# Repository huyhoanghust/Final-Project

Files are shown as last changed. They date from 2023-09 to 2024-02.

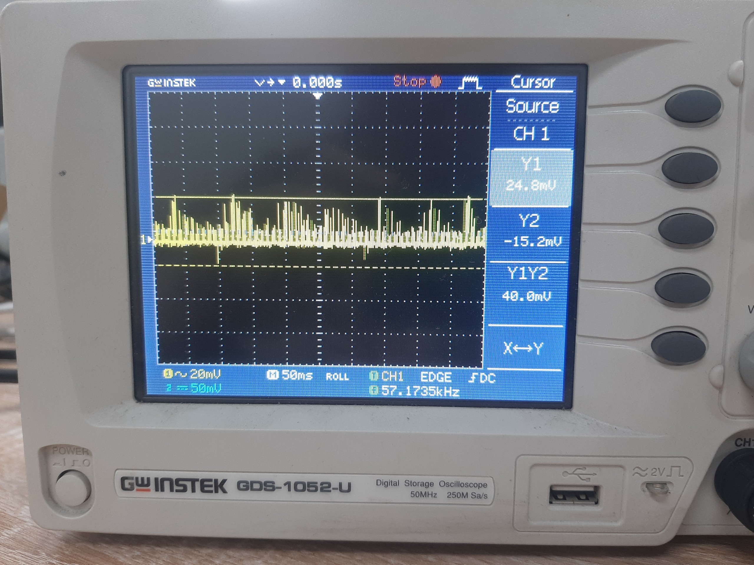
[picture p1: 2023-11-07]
PICTURE/đo nguồn/ripple_mcu.jpg

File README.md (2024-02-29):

# Final-Project
Hướng dẫn cài đặt chương trình
A1. Cài đặt môi trường làm việc

A1.1 Cài đặt IDE Visual Studio Code
Visual Studio Code (VS Code) là một trình soạn thảo mã nguồn mở và miễn phí, được phát triển bởi Microsoft. Được thiết kế để hỗ trợ nhiều ngôn ngữ lập trình và nền tảng, VS Code đã trở thành một trong những trình soạn thảo mã nguồn phổ biến nhất trong cộng đồng phần mềm. 
Truy cập vào đường link sau: https://code.visualstudio.com/download, để tải môi trường lập trình IDE cho dự án. 

A1.2. Cài đặt Extensions cho dự án
Khi hoàn thành việc cài đặt IDE, tiếp theo là cài đặt Extensions để hỗ trợ lập trình cho chip STM32 với ngôn ngữ C/C++, các bước lần lượt như sau:

Bước 1: Cài đặt ngôn ngữ C/C++ cho môi trường
 
 
Hình A- 1 Tiện ích cho ngôn ngữ C/C++

Bước 2: Cài đặt gói cho chip STM32
 
 
Hình A- 2 Tiện ích cho chip STM32

Bước 3: Cài đặt MakeFile để build chương trình
 
 
Hình A- 3 Tiện ích cho Makefile

A1.3. Cài đặt Driver ST - Link hỗ trợ nạp chương trình
Sau khi thiết kế xong firmware, việc tiếp theo là nạp chương trình và debug thông qua Driver có sẵn do hãng ST của chip hỗ trợ. Đường dẫn để cài đặt Driver sau: https://www.st.com/en/development-tools/stsw-link009.html. 
A1.4. Viết file Json và Makefile cho dự án
Do Vscode là môi trường mở và đa nền tảng nên việc trích tới đường dẫn file build và chạy chương trình là cần thiết và do người dùng tự viết. Với dự án này em thiết kế như sau:
 
 
Hình A- 4 Thiết kế file Json cho trích xuất đường dẫn
 
 
Hình A- 5 Thiết kế Makefile để chạy chương trình

A2. Hướng dẫn sử dụng thiết bị
•	Bước 1: Lắp đặt các thành phần phụ kiện như Anten GPS, Anten 4G, các cảm biến, Pin RTC, màn hình Oled, quạt tản nhiệt vào thiết bị như Hình A- 6.

•	Bước 2: Cấp nguồn cho thiết bị bằng cách cắm nguồn Accqui từ xe vào thiết bị như Hình A- 7. 

•	Bước 3: Sau khi cấp nguồn, đợi khoảng 30 giây để thiết bị khởi động, kết nối mạng 4G, kết nối GPS. Nếu khởi động và kết nối thành công, đèn Led hiển thị trạng thái thiết bị bao gồm trạng thái làm việc vị trí số 1 (sáng liên tục), trạng thái sóng 4G vị trí số 2, GPS vị trí số 3 sẽ nhấp nháy với chu kì lần lượt là 0.5 giây và 1 giây như Hình A- 8.

•	Bước 4: Sau khi thấy Led hiển thị theo chu kì đó, nghĩa là thiết bị đã sẵn sàng để hoạt động trong suốt quá trình xe hoạt động. Thiết bị sẽ thu thập thông tin rồi xử lí sau đó gửi lên DashBoard để hiển thị và giám sát dữ liệu và thông tin như Hình A- 8. Nếu xe dừng hẳn sau 1 thời gian, thiết bị sẽ vào trạng thái ngủ đông để tiết kiệm năng lượng.

  
  
  
Hình A- 6 Lắp đặt các thành phần vào thiết bị

 
 
Hình A- 7 Phần cấp nguồn từ Accqui vào thiết bị

 
 
Hình A- 9 Đèn Led hiển thị trạng thái

 
 
Hình A- 8 Giao diện theo dõi thiết bị

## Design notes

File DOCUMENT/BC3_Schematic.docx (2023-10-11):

BÁO CÁO TIẾN TRÌNH ĐỒ ÁN TỐT NGHIỆP (3)

Nguyễn Huy Hoàng_20191855_Tự động hóa 06 - K64

DANH MỤC HÌNH VẼ VÀ BẢNG BIỂU

# 1. Thiết kế sơ đồ nguyên lý

Từ sơ đồ khối chung của toàn bộ hệ thống đã được trình bày ở trên, phần này của báo cáo sẽ đi vào thiết kế, tính toán, lựa chọn linh kiện cho từng khối.

Sau khi có sơ đồ khối, đồ án đi vào thiết kế sơ đồ nguyên lý. Hình dưới thể hiện các sơ đồ khối phần cứng được thiết kế kết nối với nhau một cách chi tiết:

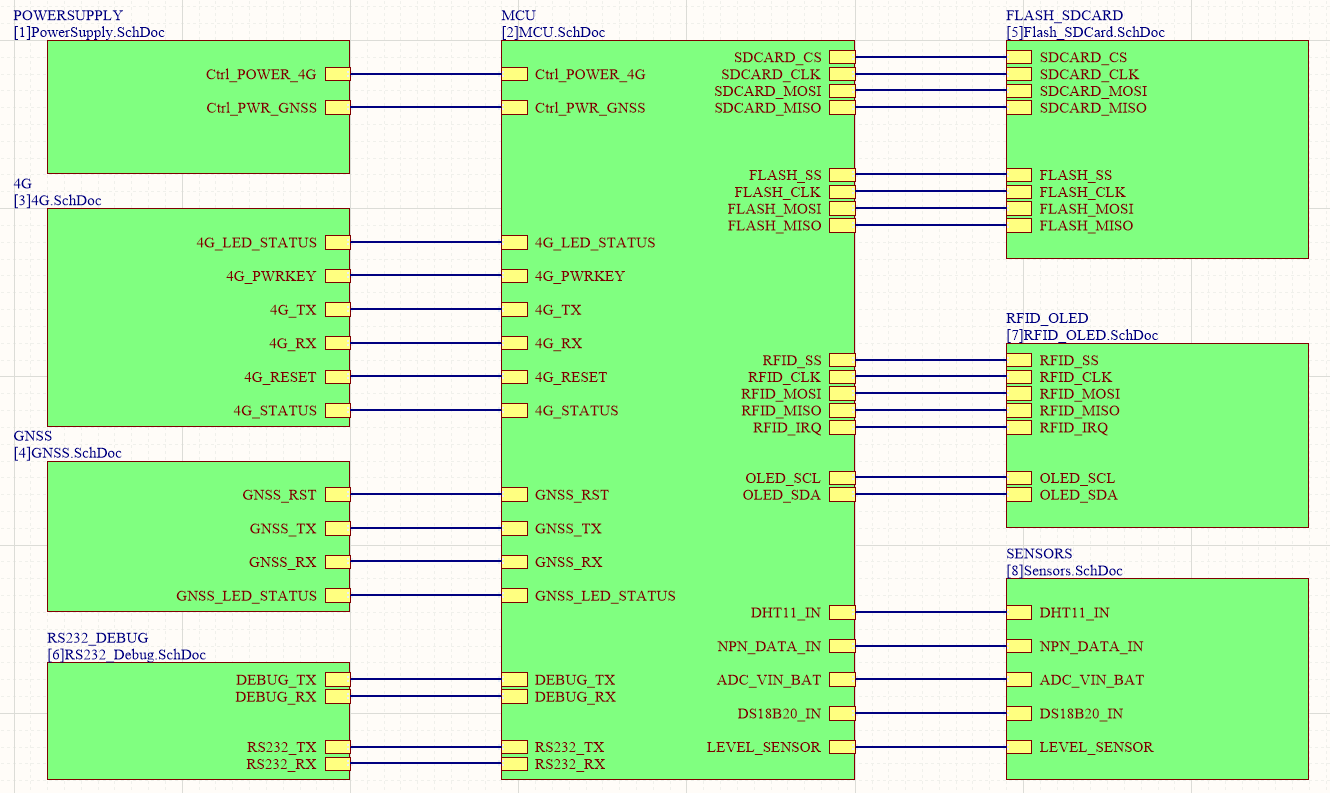
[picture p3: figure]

Hình 1. 1 Sơ đồ mạch nguyên lý tổng thể của thiết bị

# 2. Thiết kế khối nguồn

Đây là khối giúp cung cấp năng lượng cho toàn bộ thiết bị hoạt động. Nó được coi như trái tim của thiết bị, quyết định đến sự hoạt động ổn định và lâu dài của thiết bị. Do đó việc tính toán thiết kế khối nguồn một cách cẩn thận sẽ giúp cho thiết bị hoạt động hiệu quả liên tục trong thời gian dài.

Để thiết kế được khối nguồn đảm bảo hoạt động của toàn bộ các thành phần còn lại của hệ thống, trước tiên em phải làm rõ mức độ tiêu thụ của các khối chính trong mạch. Năng lượng tiêu thụ của các thành phần trong mạch sẽ được tham khảo từ Datasheet của các thành phần đó.

Đối với MCU STM32F103RCT6, năng lượng tiêu thụ của chip sẽ được tham khảo từ công cụ STM32CubeMX của chính hãng STMicroelectronics cũng cấp. Từ công cụ, em tính toán được một cách tương đối dòng tiêu thụ của MCU khi tất cả ngoại vi cùng hoạt động rơi vào khoảng 41mA

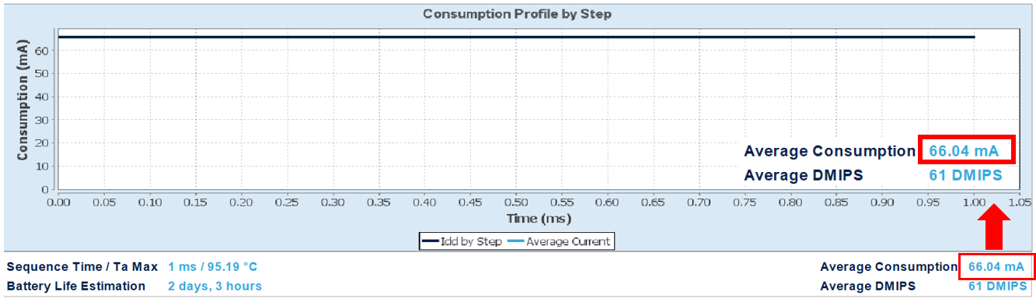
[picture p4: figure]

Hình 1. 2Năng lượng tiêu thục trung bình của MCU khi tất cả các ngoại vi cần thiết hoạt động

Đối với các thành phần còn lại, em tham khảo Datasheet của các hãng cung cấp để ước lượng tương đối năng lượng tiêu thụ trung bình của các linh kiện đó và được thể hiện như trong Bảng sau:

Bảng 1. 1Mức độ tiêu thụ năng lượng của các khối chính trong mạch

STT | Khối chính | Tác vụ tiêu thụ | Điện áp sử dụng (V) | Mức tiêu thụ (mA)
1 | STM32F103RCT6 | Tất cả ngoại vi cần thiết hoạt động đồng thời | 3.3 | ≈ 66
2 | OLED 1.3” | Hiển thị ( Nền đen. Chữ trắng, độ sáng từ 31-255) | 3.3 | ≈ 23 - 32
3 | RFID | Quét mã thẻ RFID | 3.3 | ≈ 13 - 26
4 | GNSS L70 | Tracking Mode | 3.3 | ≈ 18
5 | Đèn led, còi | Sáng đèn, bật còi | 3.3 | ≈ 100
6 | Sensor | Đo nhiệt độ và độ ẩm môi trường: DHT11 Đo nhiệt độ thiết bị: DS18B20 | 5 | ≈ 4 1.5 2.5
7 | RS232/Debug | Truyền, nhận dữ liệu | 5/3.3 | ≈ 10
8 | Flash/SDcard | Đọc, ghi dữ liệu | 3.3 | ≈ 100
9 | SIM A7672 | Gửi dữ liệu | 3.8 | ≈ 600
TỔNG | | | | ≈ 1000

Riêng đối với module SIM7672, do có nhiều chế độ hoạt động khác nhau dẫn đến việc tiêu thụ năng lượng trong từng chế độ cũng khác nhau, vì thế cần phải tính toán thiết kế riêng cho module này hệ thống nguồn riêng tách biệt với các thành phần còn lại của thiết bị. Bảng 2.2 thể hiện mức độ tiêu thụ của module SIM800 trong các chế độ khác nhau.

Bảng 1. 2Mức tiêu thụ năng lượng của module SIM7672 ở các chế độ

Chế độ | Tần số hoạt động | Mức tiêu thụ
Sleep Mode | | 3.5mA
Idle Mode | | 28.5mA
Call | EGSM900 | 320mA
| DCS1800 | 262mA
LTE Cat1 (LTE-FDD B1) | 10MHz, 23dBm | 600mA
Transmission Burst | | 2A

Từ bảng trên ta có thể thấy rằng, có thời điểm module SIM7672 có thể tiêu thụ dòng cỡ 2A. Do đó cần phải tính toán thiết kế khối nguồn riêng cho module SIM7672 tách biết với nguồn cho các thành phần còn lại của hệ thống.

Từ 2 bảng trên, thấy được nguồn và dòng cần cung cấp cho các khối là khác nhau, tùy theo các khối sử dụng điện áp và dòng điện có thể tách biệt hoặc dùng chung với những điện áp cấp cho các khối là: 12V, 5V, 3.8V, 3.3V. Do vậy, để đáp ứng về các khối có thể hoạt động bình thường trong thời gian dài, em thiết kế khối nguồn như hình sau:

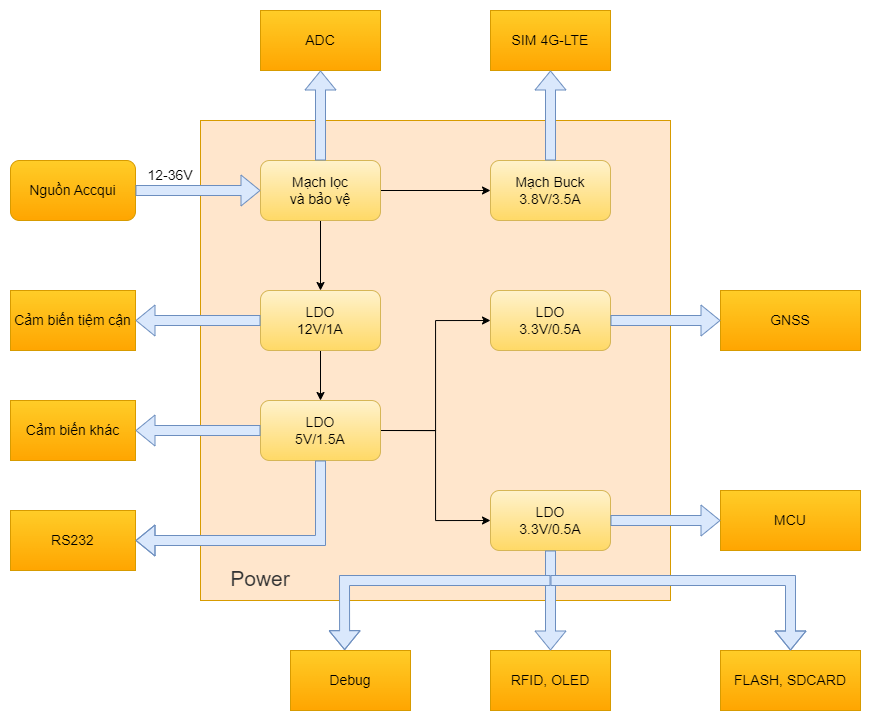
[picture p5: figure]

Hình 1. 3Mô hình tổng quan thiết kế khối nguồn cho thiết bị

Từ Bảng 1 và Bảng 2, ta thấy nguồn điện cần cung cấp cho thiết bị tối đa là 3A. Nguồn điện này hoàn toàn có thể đáp ứng được do thiết bị sử dụng trực tiếp nguồn điện từ ắc quy xe. Điện áp cung cấp cho thiết bị sẽ lấy từ ắc quy của xe, có dải điện áp dao động từ 12V-36VDC. Vì điện áp này cũng được sử dụng cho việc khởi động xe do đó nếu dùng chung điện áp này để cấp cho thiết bị thì cần có một hệ thống bảo vệ, lọc điện áp, tránh các xung điện cao áp tác động làm hư hại thiết bị trong quá trình xe khởi động/tắt máy. Hơn nữa dòng 2A mà module SIM7672 cần trong 1 khoảng thời gian rắt ngắn, cỡ μs. Do đó ở module SIM7672, em sẽ tính toán thiết kế một mạch nguồn Buck khoảng 3.5A riêng cho SIM, còn đối với các thành phần còn lại của hệ thống sẽ được cấp nguồn qua các mạch LDO riêng biệt có dòng điện và điện áp phù hợp.

## 2.1. Khối bảo vệ và lọc điện áp đầu vào

Khối bảo vệ quá áp/quá dòng, bảo vệ chống ngược cực, lọc điện áp đầu vào được mô tả như trong hình dưới. Trong đó cầu chì F1(Tự phục hồi) là loại 40V-3.5A để bảo vệ quá áp/quá dòng. Tụ chống sét C5 bảo vệ thiết bị khỏi xung cao áp lẫn trong nguồn vào. Diode D1 5A-60V bảo vệ chống ngược cực thiết bị, cuộn lọc L1 cùng 2 tụ C3, C4 tần số cao để lọc phẳng điện áp vào.

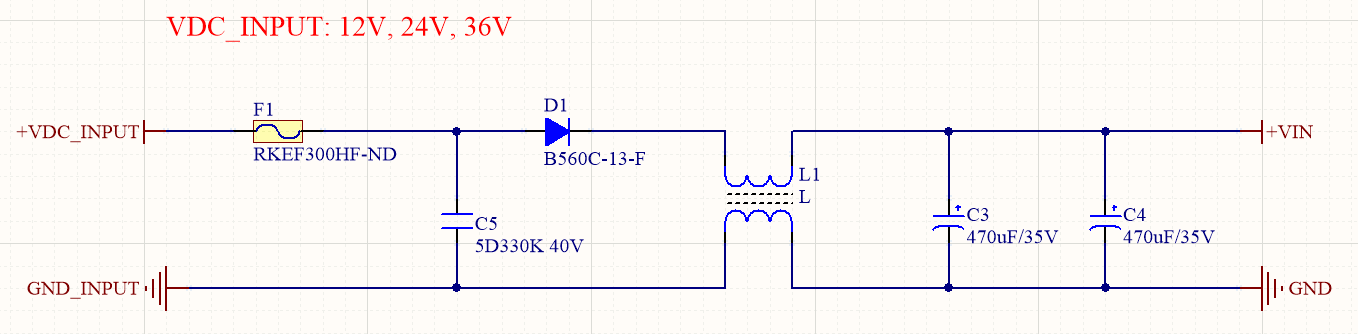
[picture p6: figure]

Hình 1. 4Khối bảo vệ và lọc điện áp đầu vào

Điện áp VIN sau khối này có thể nói là đã khá đẹp và có thể dùng để cấp cho hệ thống mạch LDO và mạch Buck ở sau.

## 2.2. Thiết kế mạch Buck cho SIM7672

Từ phân tích ở trên, module SIM7672 cần nguồn đáp ứng dòng lên tới 2A, vì thế yêu cầu thiết kế một mạch Buck riêng cấp cho SIM7672. Các thông số cơ bản đối với mạch Buck này như sau:

- V_(IN) : 12-36V
- V_(OUT) : 3.8V ± 0.1V
- I_(OUT) > 2A

Từ các thông số trên, em lựa chọn IC nguồn TPS54360 của hãng TI. Đây là một dòng IC nguồn chất lượng cao, giá thành hợp lí, hiệu suất chuyển đổi cao của hãng TI, phù hợp với các thiết bị yêu cầu tính nhỏ gọn. Một vài tính năng của IC này được trình bày ngắn gọn như sau:

- Dải điện áp vào rộng: 4.5V-60V
- Dòng liên tục cỡ 3.5A, có thể peak lên 4.5A
- Dòng không tải nhỏ ~ 146uA
- Tự động lock chip khi VIN <4.3 V.

Sơ đồ chân và chức năng từng chân được trình bày như hình và bảng dưới đây:

Tên chân | Chức năng
BOOT | Chân gắn tụ Bootstrap
VIN | Cấp điện áp Input
EN | On/Off chip
RT/CLK | Chân tạo clock
FB | Chân phản hồi điện áp
GND | Chân Ground
SW | Chân S của Mosfet

Hình 1. 5Sơ đồ chân IC TPS54360

Sơ đồ thiết kế mạch Buck sử dụng IC TPS54360 được tham khảo từ Datasheet của hãng và được mô tả như trong hình dưới. Trong đó VIN là điện áp đã được lọc từ trước, 2 tụ đầu vào C9, C10 2.2uF/100V được thêm vào để ổn định điện áp đầu vào VIN. Tụ C6 là tụ Bootstrap thêm vào theo đúng Reference của hãng. Các thành phần còn lại được thiết kế dựa trên sơ đồ chung của một mạch Buck thông thường bao gồm diode schotky D2 B560C, cuộn cảm L2 8.2uH, khối phản hồi điện áp về để fix điện áp đầu ra ở khoảng 3.8V, diode và tụ lọc điện áp đầu ra. Các linh kiện mắc vào chân RT/CLK và chân COMP được tham khảo từ Datasheet của hãng. IC được điều khiển hoạt động (ON/OFF) bằng MCU thông qua chân EN. Cụ thể khi điện áp chân EN dưới 1.2V thì IC sẽ ngừng hoạt động. Do đó em thiết kế thêm mạch ON/OFF IC nguồn này thông qua Transistor Q1 C1815 nhằm Power-off IC nguồn cấp điện cho module SIM7672 trong những trường hợp muốn cho thiết bị hoạt động ở chế độ ngủ.

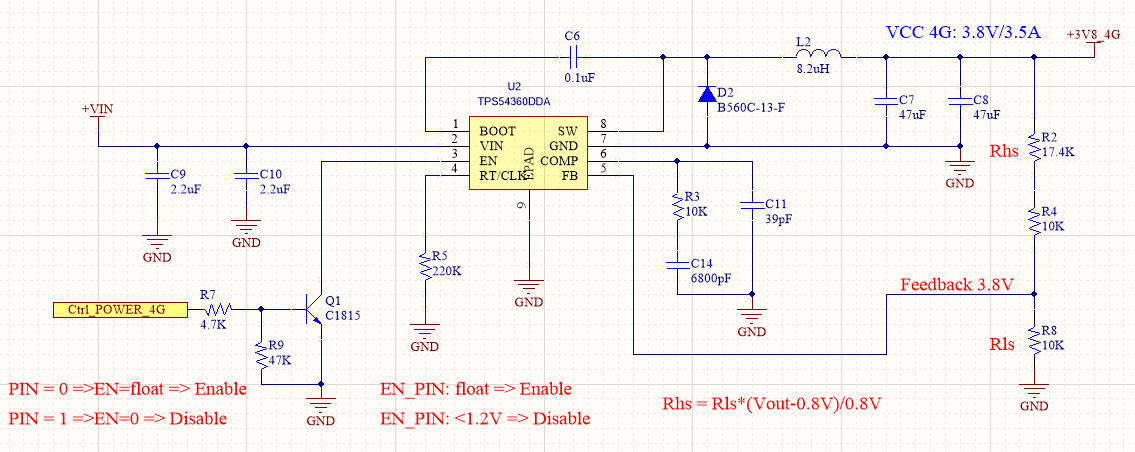
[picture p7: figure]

Hình 1. 6Sơ đồ nguyên lí mạch Buck 3.8V

Bảng 1. 3Chi tiết các thông số thành phần của mạch Buck được thiết kế như sau:

Thông số | Giá trị
Điện áp ra | 3.8V
Dòng điện ra | 3.5A
Điện áp vào | Dải điện áp vào từ 8.5V đến 60V Đáp ứng điện áp accqui: 12V, 24V, 36V
Độ ripple của điện áp ra | 0.5%Vout

Thiết kế lựa chọn Tần số đóng cắt (Switch Frequency)

f_(SW) =1/(t_(ON))*(I_0 *R_(dc) *V_(OUT) *V_d)/(V_(IN) *I_0 *R_(DS(on)) *V_d)

- I_0 : dòng ra
- I_(cl) : dòng giới hạn
- R_(dc) : điện trở cuộn cảm
- V_(in) : điện áp vào max
- V_(out) : điện áp ra
- V_(outsc) : điện áp trong suốt short
- V_d : điện áp rơi trên diode
- R_(ds) :điện trở đóng cắt
- T_(on) : thời gian có thể điều khiển

F_(div) : hệ số chia tần với điện trở:

Với t_(onmin) được chọn theo hãng là 135 ns, điện áp ra là 3.8V và điện áp vào max là 36V, điện áp rơi trên diode là 0.7V, trở kháng cuộn dây là 25 mΩ , điện trở đóng cắt là 92 mΩ , dòng điện giới hạn là 4.7A và điện áp ra short là 0.1V. Từ đó tính được tần số đóng cắt theo phương trình là:

f_(SW(maxskip)) =1/(135ns)*((3.5A* 25mΩ+3.8V+0.7V)/(36V-3.5A*92mΩ+0.7V))=934kHz

Chọn tần số đóng cắt f_(SW) =441kHz từ đó thay vào phương trình tìm điện trở R_T :

R_T =101756/(441^1.008)=220 (kΩ)

Hai tụ C9 và C10 được thêm vào để lọc điện áp đầu và xác định độ Ripple của điện áp vào tương ứng với I_(OUT) =3.5A , C_(in) =4.4uF , f_(SW) =441kHz ta được:

ΔV_(in) =(I_(OUT) *0.25)/(C_(in) *f_(SW))= (3.5A*0.25)/(4.4uF*441kHz)=451mV

Do khối buck hoạt động theo nguyên lí băm xung. Do đó phần tử cuộn cảm có tác dụng hiệu chỉnh dòng điện ra được tính theo công thức:

L_(0(min)) =(V_(IN(max)) -V_(OUT))/(I_(OUT) *0.3)*(V_(OUT))/(V_(IN(max)) *f_(SW))=(36V-3.8V)/(3.5A*0.3)*(3.8V)/(36V*441kHz)

- L_(0(min)) =7.3 uH

Chọn cuộn dây có L = 8.2uH

Độ Ripple của cuộn dây:

I_(RIPPLE) =(V_(OUT) *(V_(IN(max)) -V_(OUT) ))/(V_(IN(max)) *L_0 *f_(SW))=(3.8V*(36V-3.8V))/(36V*8.2uH*441kHz)=0.564 A

I_(L(ms)) =√((I_(OUT) )^2 +1/12*(I_(RIPPLE) )^2)=3.5A

I_L =I_(OUT) +(I_(RIPPLE))/2=3.78 A

Phần tử tụ điện có tác dụng xác định cực, độ Ripple của điện áp ra và điều chỉnh với sự thay đổi của dòng điện tải. ΔI_(OUT) là độ thay đổi dòng điện ra tham khảo từ hãng là từ 0.875A tới 2.625A do vậy ΔI_(OUT) =2.625-0.875=1.75A . ΔV_(OUT) là độ thay đổi điện áp ra cho phép là 4% do đó ΔI_(OUT) =0.04*3.8=0.152V . Từ đó tính được giá trị của tụ điện theo công thức:

C_(OUT) >(2*ΔI_(OUT))/(f_(SW) *ΔV_(OUT))=(2*1.75A)/(441 kHz*0.152V)=52.2 uF

- Chọn 2 tụ có giá trị là 47 uF

Thành phần diode schotky SS56 được lựa chọn dựa theo đề xuất của hãng.

Cầu điện trở phân áp để thiết kế fix điện áp ra ở ngưởng 3.8V theo công thức của hãng:

R_(HS) =R_(LS) *(V_(OUT) -0.8)/0.8

Chọn R_(LS) =10kΩ , với V_(OUT) =3.8V từ đó tính được R_(HS) =37.5kΩ . Chọn 2 điện trở mắc nối tiếp có giá trị là 17.4kΩ và 10kΩ . Thay ngược lại tính được V_(OUT) =3.792V gần với 3.8V. Điện áp này hoàn toàn phù hợp với modul SIM7672.

## 2.3. Thiết kế mạch LDO cho các khối còn lại của thiết bị

Đối với các khối còn lại, do lượng năng lượng tiêu thụ nhỏ ≈1000mA, do đó có thể sử dụng các mạch LDO để cung cấp năng lượng cho các khối đó do đặc điểm đơn giản, dễ thiết kế, hiệu quả cao đối với các tải có công suất thấp cũng như chất lượng điện áp cao nhất giúp các thiết bị hoạt động trong thời gian dài. Do điện áp VIN dao động từ 12-36VDC, khá lớn nếu chúng ta hạ thẳng xuống mức điện áp 5V hoặc 3.3V. Do đặc điểm của mạch nguồn LDO là phát nhiệt nhiều khi chênh lệch điện áp giữa đầu vào và đầu ra lớn, cùng với việc cấp điện áp cho khối cảm biến 12V và 5V, vì thế nên để tăng tính hiệu quả và ổn định thì em sẽ thiết kế mạch LDO để hạ điện áp từ VIN xuống 12V, sau đó hạ tiếp từ 12V xuống 5V, từ điện áp 5V này qua các mạch LDO khác để hạ xuống 3.3V cung cấp cho các khối còn lại.

Sơ đồ mạch LDO hạ áp từ VIN xuống 12V được mô tả như trong hình dưới. IC LDO được sử dụng là IC 7812CD2T của hãng STMicroelectronic, với thông số điện áp đầu ra fix 12V, dòng điện tối đa theo hãng công bố là 1A, hoàn toàn đáp ứng được yêu cầu cung cấp năng lượng cho các khối còn lại. Tụ C1, C2 thêm vào đầu vào và đầu ra giúp ổn định điện áp cho mạch. Đèn Led D2 biểu thị đầu ra của mạch đã có điện áp 12VDC.

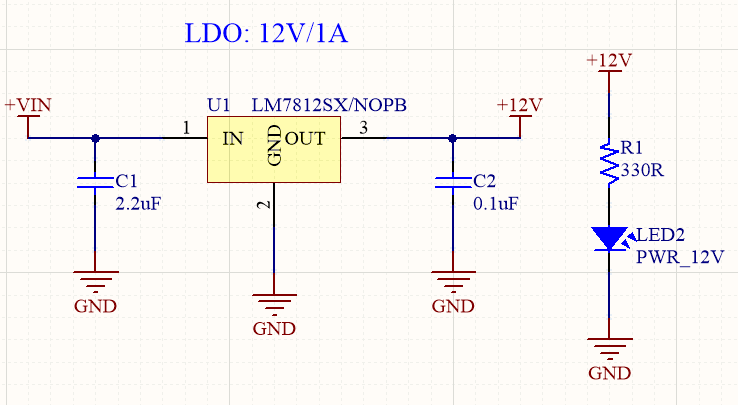
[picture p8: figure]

Hình 1. 7Mạch nguồn LDO hạ áp 12V

Điện áp 12V thu được sau khối hạ áp, tiếp tục được hạ áp xuống 5V cấp cho khối cảm biến sử dụng IC LDO LM317. Điện áp sau khối hạ áp được tính theo công thức của hãng: V_(out) =1.25*(1+(R_15)/(R_14))+I_(adj) *R_15 . Với dòng adjust theo datasheet là 50uA, từ đó chọn được R_14 =1.2k , R_15 =3.48k . Thay ngược lại V_(out) =5.05V hoàn toàn đáp ứng được cho các khối cảm biến. Các tụ điện C12, C13 được thêm vào để lọc điện áp trước và sau khối hạ áp.

Hình 1. 8Mạch nguồn LDO hạ áp 5V

Điện áp 5V tiếp tục được hạ áp xuống 3.3V qua IC RT9013 để cũng cấp cho MCU và các khối sử dụng điện áp 3.3V như Flash, SDCard, RFID, OLED, Debug. Chân EN được kẻo lên VCC qua trở 10K để Enable chip. Các tụ lọc đầu vào và đầu ra của IC giúp ổn định và lọc điện áp. Điện áp ra là 3.3V và dòng 500mA.

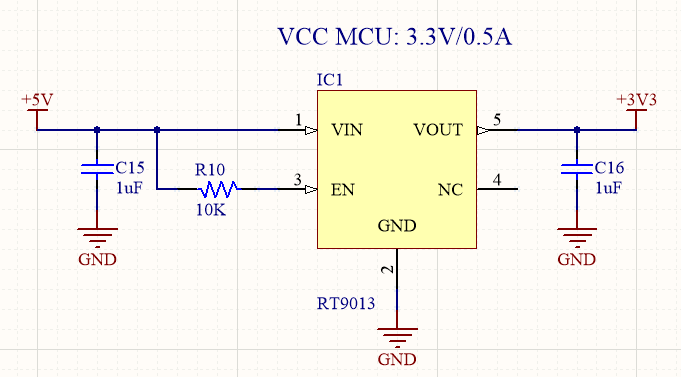
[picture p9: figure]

Hình 1. 9Mạch nguồn LDO cho khối MCU

Riêng với khối GNSS, do điện áp tiêu thụ nhỏ, tuy nhiên để đáp ứng cầu điều khiển ON/OFF module GNSS nên em thiết kế cho module một khối nguồn riêng có khả năng điều khiển ON/OFF thông qua MCU, phục vụ cho thiết bị chạy ở chế độ ngủ, tiết kiệm năng lượng. Khối nguồn cho GNSS vẫn là nguồn LDO 3.3V nên em cũng sử dụng IC RT9013. Các chân cơ bản được thiết kế giống mạch nguồn MCU, nhưng có thêm bộ điều khiển ON/OFF thống qua transistor Q2 C1815 bởi MCU.

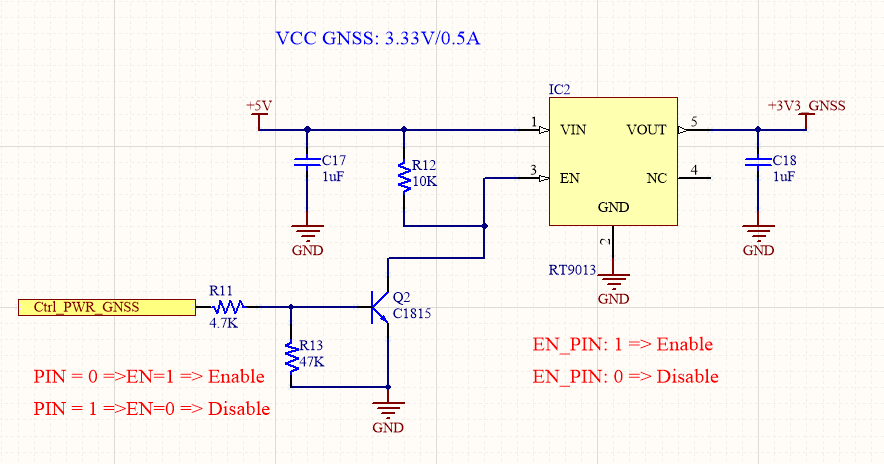
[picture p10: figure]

Hình 1. 10Mạch nguồn LDO cho khối GNSS

# 3. Khối hiển thị và thông báo

Đây là khối có nhiệm vụ hiển thị các thông tin, thông báo giúp người vận hành xe có thể biết được trạng thái làm việc của thiết bị thông qua hệ thống màn hình OLED, đèn led và còi báo. Sơ đồ khối của khối hiển thị được mô tả như hình sau:

Hình 1. 11Khối hiển thị và thông báo

Trạng thái nguồn, trạng thái mạng 4G LTE, trạng thái sóng GNSS được thể hiện qua khối đèn LED. Còi Buzzer là loại 3.3V được điều khiển thông qua transistor Q3 C1815 để thông báo trạng thái quẹt thẻ RFID hoặc các lỗi khác. Các thông tin khác được hiển thị trực tiếp trên màn hình OLED 1.3”. Màn hình này sử dụng công nghệ OLED tiết kiệm điện, giao tiếp với MCU qua giao thức I2C, nguồn điện cung cấp là 3.3VDC được lọc qua cuộn cảm FB2 100uH. Loại màn hình được sử dụng được mô tả như hình sau:

Hình 1. 12Màn hình OLED

# 4. Khối RFID

Khối RFID được thiết kế nhằm mục đích xác định người lái xe là ai, phục vụ nhu cầu giám sát, quản lí nhân sự. Có nhiều công nghệ nhận dạng con người, có thể kể đến như sử dụng RFID, dấu vân tay, sử dụng quét mã vạch/QRCode, sử dụng mật khẩu cá nhân, … Tuy nhiên trên cơ sở phân tích các ưu nhược điểm của các phương pháp trên, em lựa chọn sử dụng phương pháp quét RFID bởi những lí do sau:

- Đây là công nghệ đã phổ biến từ lâu, dễ thiết kế và thi công, độ chính xác và an toàn cao.
- Đây là phương pháp bắt buộc đối với các thiết bị giám sát hành trình thông thường do bộ GTVT quy định.
- Phương pháp sử dụng dấu vân tay hay mật khẩu cá nhân có nhược điểm tốn kém, tốn thời gian khi thao tác, do đó em không lựa chọn.
- Phương pháp sử dụng mã vạch, mã QRCode không phù hợp với bài toán đặt ra.

RFID là công nghệ nhận dạng đối tượng bằng sóng vô tuyến. Công nghệ này cho phép nhận biết các đối tượng thông qua hệ thống thu phát sóng Radio, từ đó có thể giám sát, quản lý hoặc lưu từng đối tượng, có nhiều ưu điểm vượt trội so với công nghệ mã vạch. Một thiết bị RFID được cấu tạo bởi hai thành phần chính là thiết bị đọc (RFID Reader) và thiết bị phát mã RFID có gắn chip (RFID Tag hay thẻ RFID). Hai thiết bị này hoạt động thu phát sóng điện từ cùng tần số với nhau. Các tần số thường được sử dụng trong hệ thống RFID là 125kHz hoặc 13.56MHz. Thẻ RFID được gắn với vật cần nhận dạng và mỗi thẻ RFID chứa một mã số nhất định, không trùng lặp nhau.

Nguyên lý hoạt động: thiết bị RFID Reader phát ra sóng điện từ ở một tần số nhất định; khi thiết bị RFID Tag trong vùng hoạt động sẽ cảm nhận được sóng điện từ này và thu nhận năng lượng, sau đó phát lại cho RFID Reader biết mã số của mình. Trong đồ án em sử dụng module RFID RC522 và thẻ RFID dạng S50 như hình dưới. Module có chức năng dùng để đọc và ghi dữ liệu cho thẻ RFID tần số 13.56MHz, với mức giá rẻ và thiết kế nhỏ gọn.

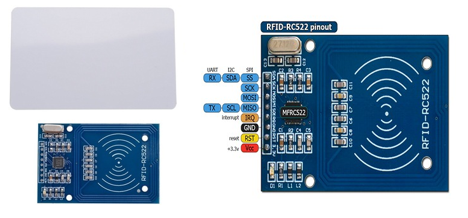
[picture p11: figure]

Hình 1. 13Module RFID RC522 và thẻ RFID S50

Trong đồ án này, em sử dụng module RC522 để đọc mã thẻ RFID S50. Mỗi một lái xe sẽ được cấp thẻ RFID riêng và được đăng kí trước trên hệ thống. Thiết bị sẽ đọc ID thẻ, gửi lên server để xác nhận thông tin ID, từ đó thông báo cho người lái xe thông qua hệ thống hiển thị.

Thông số kĩ thuật của module RFID RC522 như sau:

- Nguồn 3.3VDC, dòng tiêu thụ 13- 26mA
- Tần số sóng mang 13.56Mhz
- Khoảng cách hoạt động <6cm
- Giao tiếp SPI, tốc độ tối đa 10Mbit/s

Sơ đồ thiết kế được mô tả như trong hình dưới. Module được cấp nguồn 3.3VDC qua cuộc cảm FB3 100uH, các chân 1-6 được nối trực tiếp với chân SPI của MCU, chân RST được treo lên nguồn 3.3VDC.

Hình 1. 14Sơ đồ nguyên lí khối RFID

# 5. Khối xử lí trung tâm – MCU

Khối xử lí trung tâm là một IC khả trình có thể thực hiện thuật toán, chương trình được cài đặt sẵn, cụ thể ở đây là một vi điều khiển – MCU. Việc lựa chọn MCU phù hợp sẽ được trình bày chi tiết trong phần này.

Việc lựa chọn MCU sẽ dựa theo các tiêu chí sau:

- Lõi của MCU, xung nhịp lõi của MCU.
- Độ phổ biến của MCU.
- Các công cụ hỗ trợ phát triển (Từ hãng và từ cộng đồng), khả năng hỗ trợ nếu phát sinh lỗi trong quá trình lập trình.
- Số lượng ngoại vi phải phù hợp với yêu cầu của bài toán.
- Giá cả phải hợp lí.
- Độ ổn định khi hoạt động lâu dài.
- Vấn đề về năng lượng tiêu thụ.
- Hỗ trợ mạnh mẽ các Middle-ware như RTOS, FatFs, USB, …

Căn cứ theo bài toán đặt ra, cũng như để thực hiện đúng các chức năng của hệ thống đã đặt ra ban đầu, MCU sẽ cần có các ngoại vi và thông số như sau:

- MCU lõi ARM Cortex M, xung nhịp từ 48Mhz – 72Mhz để đáp ứng tốc độ xử lí cho hệ thống.
- Phải hoạt động tốt với điện áp 3.3V, khả năng hoạt động ổn định, chống nhiễu tốt. Hỗ trợ nhiều chế độ tiết kiệm năng lượng.
- Ngoại vi bao gồm: 1 bộ UART phục vụ giao tiếp với module SIM7672; 1 bộ UART phục vụ giao tiếp với module GNSS L70; 1-2 bộ UART phục vụ cho khối RS232 và Debug; 1 bộ SPI phục vụ giao tiếp với module RFID; 2 bộ SPI để phục vụ giao tiếp với chip flash và SDCard; 1 bộ I2C để giao tiếp với màn hình OLED; 1 bộ I2C để giao tiếp với EEPROM; ngoài ra các thành phần khác như ADC, Timer, Watchdog, RTC cũng phải có đủ.
- Dung lượng ROM phải trên 128Kb, RAM phải trên 32Kb đủ để lưu trữ chương trình và thực thi chương trình khi hoạt động.

Từ các phân tích trên, em đi đến lựa chọn vi điều khiển STM32F103RCT6 của hãng STMicroelectronic. MCU này có các thông số cơ bản hoàn toàn đáp ứng được các yêu cầu đã đặt ra bên trên, cụ thể:

- Lõi ARM Cortex M3 32bit.
- Tần số tối đa 72Mhz
- Bộ nhớ flash 256Kb, SRAM 48Kb
- 3 bộ ADC 12bit, tần số lấy mẫu 1Mhz
- 8 bộ Timer 16 bit, 1 bộ Systick Timer

24bit, 1 bộ watchdog timer, RTC, …

- 2 bộ DMA
- 2*I2C, 3*SPI, 5*USART, CAN,

USB, SDIO, I2S, …

- Số chân 64, trong đó có 51 chân I/O
- Điện áp hoạt động 3.3V, hỗ trợ nhiều

Chế độ Lowpower.

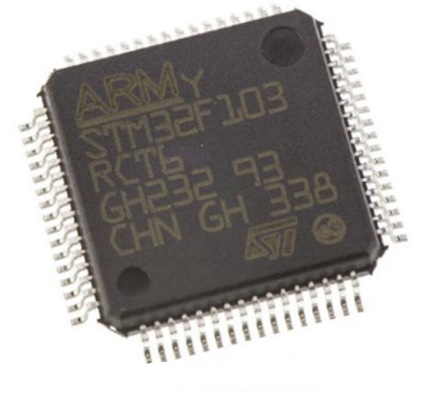
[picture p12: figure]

Hình 1. 15Vi xử lí STM32F103RCT6

Sơ đồ nguyên lí thiết kế cho khối xử lí trung tâm được trình bày trong hình dưới đây:

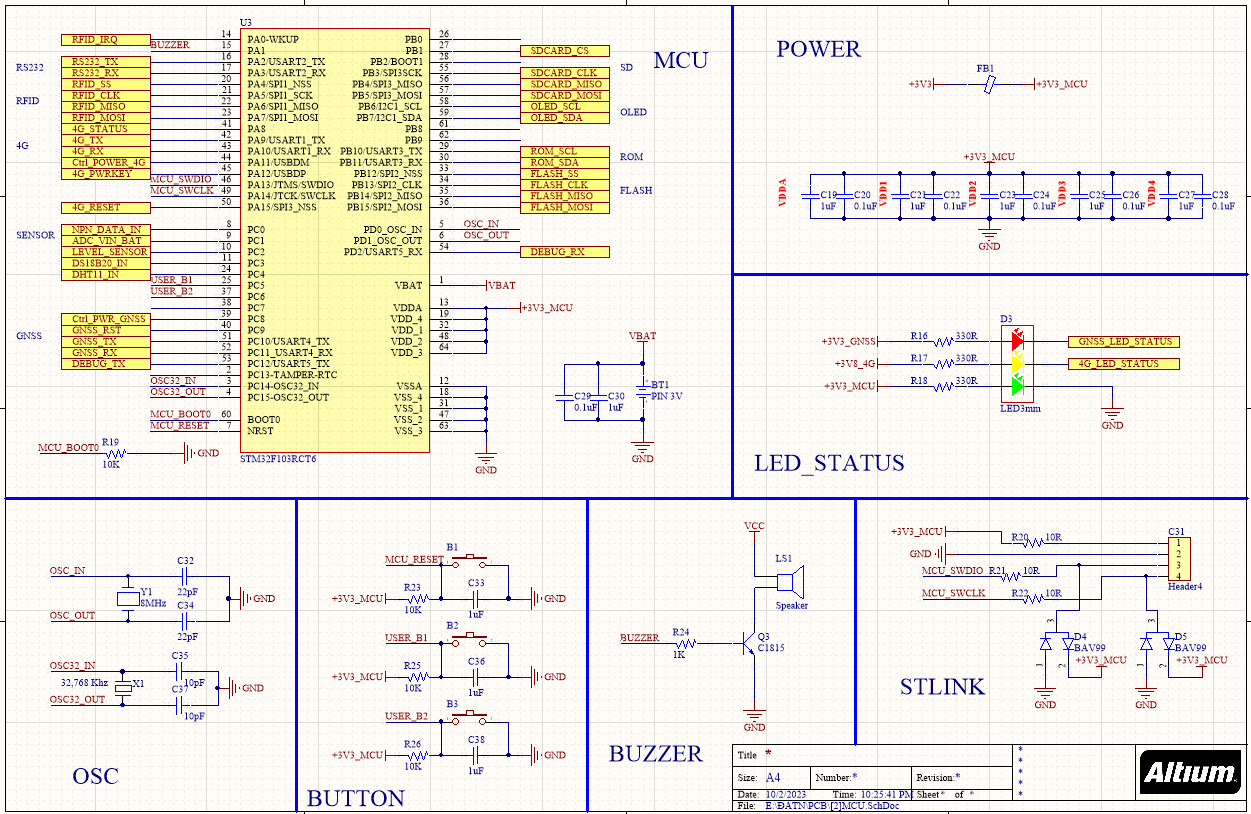
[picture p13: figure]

Hình 1. 16Sơ đồ nguyên lý khối xử lí trung tâm

Chi tiết các thành phần của thiết kế sẽ được thể hiện trong bảng dưới đây

Bảng 1. 4Giải thích các thành phần trong thiết kế khối vi điều khiển.

STT | Giải thích | Sơ đồ nguyên lí
1 | Chân RESET của MCU (Tích cực mức thấp) được treo lên VCC qua trở 10k, nút nhấn S1 nối chân RESET của MCU với GND. Tụ C33 (1-10uF) được mắc song song với nút nhấn để chống dội phím. Khi hoạt động bình thường, chân RST ở mức cao, khi muốn RESET MCU, ta ấn nút kéo chân RESET xuống GND, MCU bị RESET, chương trình chạy lại từ đầu.
2 | Đây là khối phục vụ việc nạp, debug chương trình cho MCU thông qua chuẩn SWD của ST. Các chân cần thiết bao gồm chân TMS và TCK của MCU được nối riêng ra một Connector bên ngoài để kết nối với mạch nạp ST-Link. Ngoài ra chân VCC và GND cấp nguồn cho MCU cũng được nối vào Connector này để có thể cấp nguồn cho MCU bằng mạch nạp ST-Link. Diode TVS D4 và D5 được thêm vào để bảo vệ chân TMS, TCK khỏi sự phóng tĩnh điện do các yếu tố bên ngoài tác động.
3 | Khối tạo dao động cho MCU. Mặc dù bản thân MCU STM32F103RCT6 đã được hãng trang bị bộ tạo dao động nội HSI lên đến 8Mhz và bộ LSI 40Khz cho RTC, tuy nhiên các bộ dao động này có độ chính xác không cao, HSI tốc độ chỉ có 8Mhz không đáp ứng được yêu cầu hệ thống. Thạch anh HSE 8Mhz được mắc vào 2 chân OSC IN và OSC OUT qua bộ PLL có thể nhân tần số hoạt động của chip lên tối đa 72Mhz. Thạch anh LSE 32.768Khz được mắc vào 2 chân OS32IN và OS32OUT để cấp tần số cho bộ RTC hoạt động. Các tụ C32, C34, C35, C37 được thêm vào để giúp thạch anh hoạt động ổn định và chính xác.
4 | Mức logic của 2 chân BOOT0, BOOT1 sẽ quyết định chế độ chạy của vi điều khiển, được trình bày như bảng bên dưới. Trong bài toán này lựa chọn lưu chương trình vào Flash memory. Do đó 2 chân BOOT0 và BOOT1 sẽ được kéo xuống GND qua trở.
5 | Tụ lọc tại tất cả các chân nguồn của MCU. Điện áp 3.3VDC được cho qua cuộn cảm FB1 100uH để loại bỏ điện cao tần ảnh hưởng đến MCU.
6 | Led báo trạng thái nguồn cấp cho MCU và 2 Led còn lại báo trạng thái 4G và GNSS.
7 | 2 nút nhấn dự phòng trong trường hợp cần dùng đến

# 6. Khối lưu trữ dữ liệu

Đối với các thiết bị giám sát hành trình, việc lưu trữ dữ liệu về vị trí, tốc độ, trạng thái của thiết bị 24/24 liên tục trong tối thiểu 30 ngày là yêu cầu bắt buộc. Do đó khi thiết kế thiết bị, em cũng thiết kế thêm khối lưu trữ dữ liệu để phục vụ mục đích này.

Có nhiều phương pháp để lưu trữ dữ liệu: có thể sử dụng các bộ nhớ không bay hơi như flash, hoặc sử dụng thẻ nhớ SDcard/MMC để lưu trữ dữ liệu. Trong đồ án này em lựa chọn phương án sử dụng thẻ nhớ SDCard để lưu trữ dữ liệu vì những lí do sau:

- Đơn giản, dễ thiết kế, độ ổn định cao.
- Tốc độ cao, hoàn toàn đáp ứng việc đọc ghi liên tục trong thời gian dài.
- Thẻ SDCard ngày càng có dung lượng cao và tốc độ càng nhanh.
- Dễ dàng tổ chức dữ liệu lưu trữ theo dạng File, hỗ trợ mạnh mẽ bởi các middle-ware như FatFs.
- Khi có sự cố, chỉ cần lấy thẻ SDcard cắm vào máy tính là có thể xem được dữ liệu được ghi lại.

Sơ đồ thiết kế khối SDCard được mô tả như hình dưới. Nguồn cấp cho khối này được lọc qua 2 tụ 104 và cuộn cảm FB4 100uH. Đầu đọc thẻ SDCard là loại 9Pin PUSH-PULL. Thẻ nhớ SDCard được giao tiếp với MCU qua chuẩn SPI ở chế độ 1 bit, do đó chân DAT3 của thẻ được dùng làm chân CS, chân DAT1 và DAT2 không dùng đến. Các chân của giao tiếp SPI được kéo lên nguồn VCC qua trở treo 10K Ω .

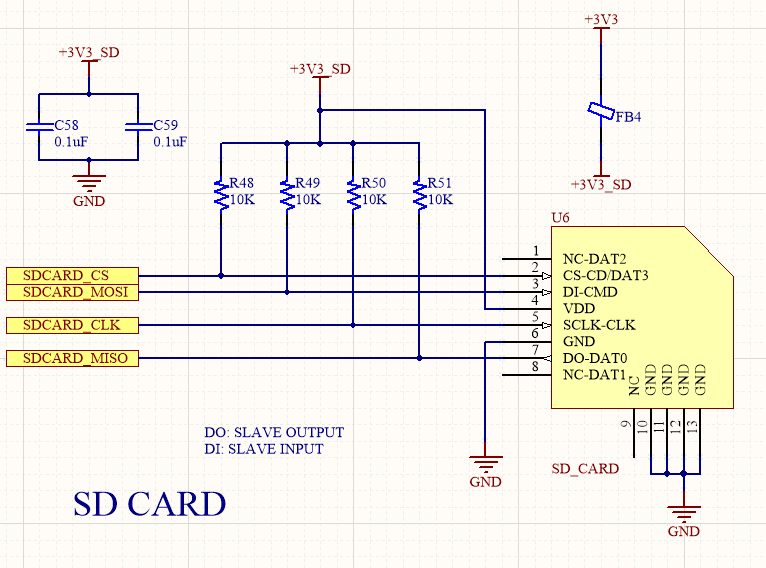
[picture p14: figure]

Hình 1. 17Sơ đồ nguyên lí khối SDCard

Ngoài ra, trong thiết kế khối này, em có thiết kế thêm một bộ FLASH nhằm lưu trữ các dữ liệu quan trọng khác như các cài đặt ban đầu cho thiết bị, các dữ liệu phục vụ việc xác định xem các thành phần khác của thiết bị đã bị thay thế hay chưa. Sơ đồ thiết kế được mô tả như hình sau. IC được dùng là Flash W25Q32JV điện áp hoạt động 3.3V, bộ nhớ 4MB tuổi thọ 1 triệu lần ghi. Hỗ trợ giao tiếp tốc độ cao SPI và QSPI. Nguồn cấp cho khối này được lọc qua 2 tụ 104 và cuộn cảm FB5 100uH. Các chân của giao tiếp SPI được kéo lên nguồn VCC qua trở treo 10K Ω .

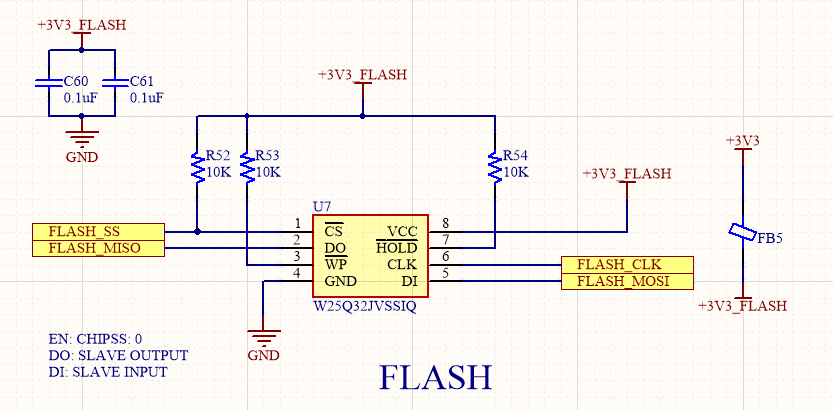
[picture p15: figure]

Hình 1. 18Sơ đồ nguyên lí khối Flash

# 7. Khối 4G LTE

Đây là khối có nhiệm vụ kết nối thiết bị với server thông qua hệ thống mạng 4G LTE để thiết bị và server có thể trao đổi dữ liệu với nhau. Hiện nay có rất nhiều giao thức không dây hỗ trợ truyền dữ liệu như wifi, lora, BLE, … Tuy nhiên đồ án sử dụng mạng 4G LTE để phục vụ kết nối thiết bị với server vì những lí do sau:

- Độ phổ biến của mạng 4G
- Đơn giản, dễ thiết kế, triển khai.
- Phạm vi kết nối rộng do hầu hết các nhà mạng như Viettel, Mobiphone, Vinaphone đều hỗ trợ công nghệ này.
- Tốc độ truyền dữ liệu cao đảm bảo tính thời gian thực của hệ thống.

Hình 1. 19Module SIM A76772

Một vài thông số kĩ thuật và các tính năng cơ bản của module SIM7672 như sau:

- Điện áp hoạt động 3.4-4.2VDC, thường dùng 3.8V
- Hỗ trợ nhiều chế độ hoạt động khác nhau, dòng điện ở chế độ ngủ là 3.5mA
- Hỗ trợ 3 dải tần: LTE – FDD(B1/B3/B5/B8), LTE - TDD (B34/B38/B39/B40/B4), GSM/GPRS/EDGE 900/1800
- LTE Cat 1: Upload 5Mbps, Download 10Mbps; EDGE: 236kbps; GPRS: 85.6Mbps.
- Hỗ trợ giao thức TCP/IP/IPV4/IPV6/Multi-PDP, FTP, FTPS , HTTP, HTTPS, DNS, MQTT
- Hỗ trợ gửi SMS và gọi điện thông qua mạng 4G.
- Hỗ trợ tập lệnh AT, dễ dàng giao tiếp với các MCU khác nhau
- Ngoại vi: SIM Card, UART, ADC, GPIO, I2C.
- Giao tiếp UART: Baudrate từ 9600 – 115200, hỗ trợ chế độ Auto Baudrate
- Hỗ trợ giao tiếp USB

Sơ đồ thiết kế khối 4G LTE sử dụng module SIM A7672 của hãng SIMCOM mô tả trong hình dưới đây. Ở đây Module được cấp nguồn chính là +3.8V qua 3 chân pin là VBAT_RF. Chân POWERKEY của module điều khiển việc ON/OFF module, do đó chân này được MCU điều khiển qua transistor Q5. Chân RESET để khởi động lại module và cũng được điều khiển bằng MCU thông qua Q4. Các chân SIM_VDD, SIM_DATA, SIM_CLK, SIM_RST được nối với khe cắm sim MICRO, đồng thời được nối với IC ESDA6 để bảo vệ các xung điện áp cao và phóng tĩnh điện. Chân NETLIGHT được nối với đèn led bên ngoài để báo hiệu trạng thái hoạt động của SIM A7672, chân STATUS được nối với đèn net và đưa đến MCU để hiển thị và đọc trạng thái hoạt động của module.

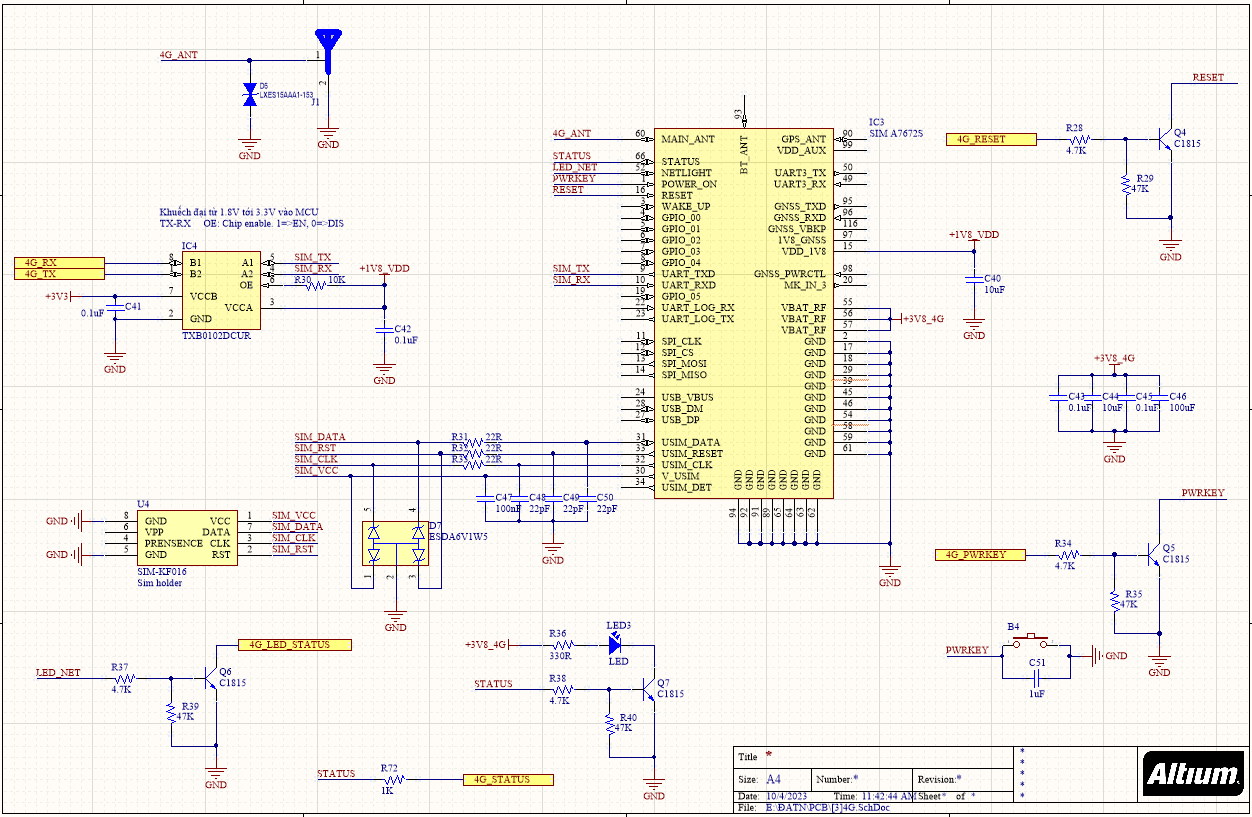
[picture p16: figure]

Hình 1. 20Sơ đồ nguyên lí khối 4G LTE

Anten của module SIM A7672 được nối vào chân MAIN_ANT qua một diode Zener D6 để giới hạn các sóng bậc cao và nhiễu do phóng tĩnh điện gây ra làm ảnh hưởng tới công suất và chất lượng đường truyền.

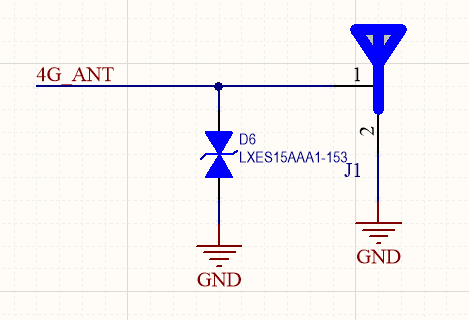
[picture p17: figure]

Hình 1. 21Anten của module SIM A7672

Module SIM giao tiếp với MCU thông qua giao thức không đồng bộ UART. Do điện áp ra và và vào chân pin của module giới hạn ngưỡng 1.8V. Vì thế em thiết kế bộ chuyển đổi mức tín hiệu (level shifter) để chuyển đổi tín hiệu giữa 2 mức điện áp khác nhau là 3.3V và 1.8V. Chân OE của IC được kéo lên VDD để enable chip. Các tụ điện C41 và C42 để lọc điện áp.

Hình 1. 22Sơ đồ nguyên lí khối chuyển đổi mức tín hiệu

# 8. Khối GNSS

Đây là khối có nhiệm vụ tính toán, xác định vị trí của thiết bị thông qua hệ thống Định vị Toàn cầu bằng Vệ Tinh GNSS - Global Navigation Satellite System. Hệ thống GNSS chủ yếu dựa vào sự kết hợp của nhiều vệ tinh trên vùng không gian để gửi tín hiệu đến các thiết bị trên mặt đất. Hai hệ thống GNSS phổ biến nhất là GPS (Global Positioning System) của Hoa Kỳ và GLONASS của Nga. Có thêm các hệ thống GNSS khác như Galileo của Liên minh Châu Âu và BeiDou của Trung Quốc. Nó là một hệ thống bao gồm nhiều vệ tinh bay xung quanh Trái Đất ở độ cao 20200 Km, hoạt động trong mọi điều kiện, thời tiết, mọi nơi trên Trái, liên tục trong 24 giờ và hoàn toàn miễn phí đối với một số dịch vụ.

Nguyên lí hoạt động của GNSS thông qua vệ tinh cụ thể là GPS của Mỹ: Các vệ tinh bay quanh trái đất hai lần một ngày theo một quỹ đạo rất chính xác và phát tín hiệu có thông tin xuống Trái Đất. Các máy thu GPS nhận tín hiệu này, sau đó tính toán thông qua các phép tính lượng giác để tính được chính xác vị trí của máy thu. Bản chất của GPS là so sánh thời gian tín hiệu được phát đi từ vệ tinh với thời gian nhận được chúng ở bộ thu. Độ sai lệch thời gian cho biết máy thu GPS cách vệ tinh bao xa, với nhiều khoảng cách từ máy thu đến các vệ tinh mà máy thu có thể tính toán được vị trí của chúng. Để tính ra được vị trí 2 chiều (kinh độ và vĩ độ) thì máy thu phải nhận được tín hiệu ít nhất là 3 vệ tinh, với ít nhất 4 vệ tinh thì có thể tính được vị trí 3 chiều (kinh độ, vĩ độ và độ cao). Một khi vị trí người dùng đã tính được thì máy thu GPS có thể tính các thông tin khác như tốc độ, hướng chuyển động, bám sát di chuyển, khoảng hành trình, ...

Hiện nay có nhiều hãng sản xuất module GNSS như AI-Thinker, Ublox, Quectel với nhiều dòng và nhiều mức giá khác nhau phục vụ cho yêu cầu định vị GNSS thông thường và định vị chính xác. Đối với đồ án này, yêu cầu định vị GNSS chỉ là định vị thông thường với sai số dưới 10m, do đó em sử dụng module GNSS L70 của hãng QUECTEL với ưu điểm: Nhỏ gọn, giá thành hợp lí, độ ổn định và chính xác cao. Hình dưới là hình ảnh thực tế module GNSS L70 với các thông số cơ bản như sau:

- Điện áp hoạt động: 2.8-4.3V
- Dòng tiêu thụ tối đa 18mA
- Tần số GPS: 1575.42MHz (L1)
- Giao tiếp UART với MCU
- Hỗ trợ NMEA, MTK Command

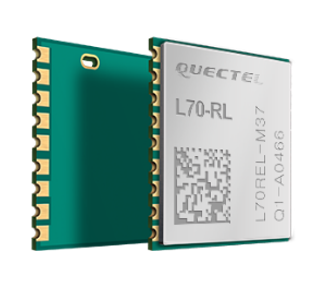
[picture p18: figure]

Hình 1. 23Module GNSS QUECTEL L70

Sơ đồ thiết kế khối GPS được mô tả như dưới. Module được cấp nguồn qua chân VCC_GPS 3.3V từ khối nguồn. Chân V_BCKP được nối với nguồn Backup nhằm nuôi bộ RTC khi module không có nguồn ở chân VCC. Antena được thiết kế theo Reference của hãng. Module giao tiếp với MCU thông qua giao thức UART.

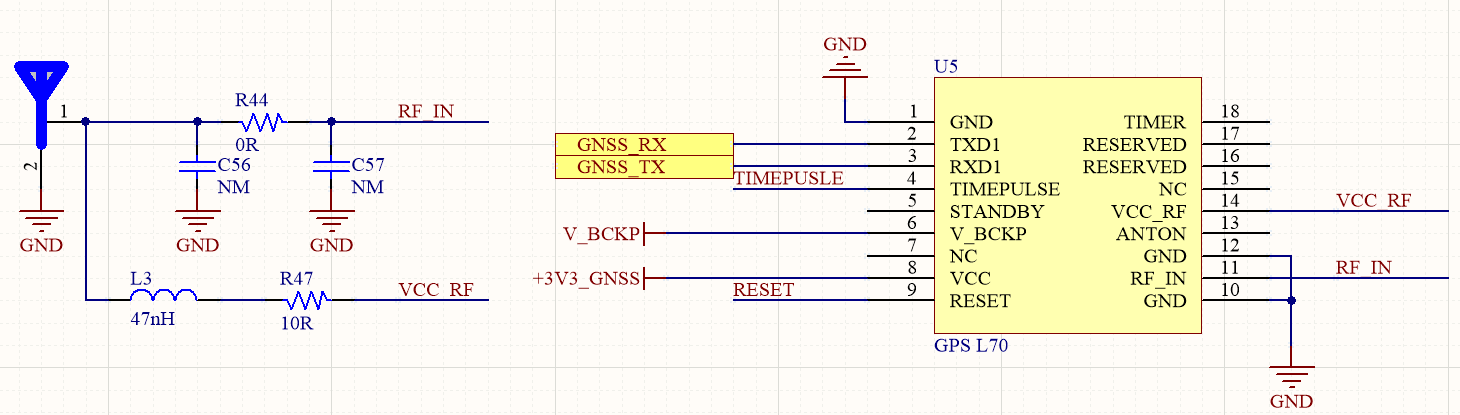
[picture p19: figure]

Hình 1. 24Sơ đồ nguyên lí khối GNSS L70

Khi thiết kế antenna cho khối GNSS, em tham khảo sơ Reference Circuit từ nhà sản xuất. có 4 phương án được đề xuất đó là

- Sử dụng Active Antenna và không sử dụng chân ATON: Trong đó Antenna được cấp nguồn trực tiếp qua chân VCC_RF. Nguồn cấp cho antenna từ 2.8 – 4.3V. Do trong bộ Active Antenna có sẵn 1 bộ LNA do đó cần nguồn nuôi trực tiếp từ chân VCC_RF để hoạt động. R1, C1, C2 được thiết kế để tạo thành mạch phối hợp trở kháng đầu vào để trở kháng antenna xấp xỉ 50 Ohm. Đồ án sử dụng thiết kế này, do đã tính toán trước kích thước Antenna Trace để trở kháng đạt xấp xỉ 50Ohm do đó R1 = 0 Ohm, C1, C2 bỏ trống (Not Mounted). Cuộn cảm L1 được thêm vào để ngăn chặn sự rò rỉ tín hiệu RF vào chân VCC_RF, theo khuyến cáo thì L1 không quá 47nH. R2=10 Ohm được thêm vào để hạn dòng trong trường hợp antenna bị ngắn mạch xuống GND.

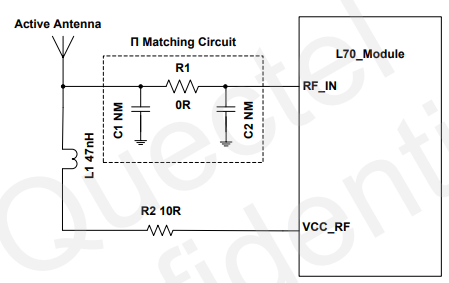
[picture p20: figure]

Hình 1. 25Sơ đồ thiết kế mạch Active Antenna without ATON

- Sử dụng Active Antenna và dùng chân ATON: Hoàn toàn tương tụ như thiết kế bên trên tuy nhiên nguồn cấp cho antenna qua chân VCC_RF được điều khiển thông qua 2 mosfet Q1 và Q2. Khi chân ATON ở mức cao, Q1 và Q2 dẫn, antenna được cấp nguồn. phương án này được sử dụng với mục đích tiết kiệm năng lượng.

Hình 1. 26Sơ đồ thiết kế Active antenna with ATON

- Sử dụng Passive Antenna không có bộ LNA: R1, C1, C2 được thêm vào để phối hợp trở kháng, đường antenna được thiết kế ngắn nhất có thể.

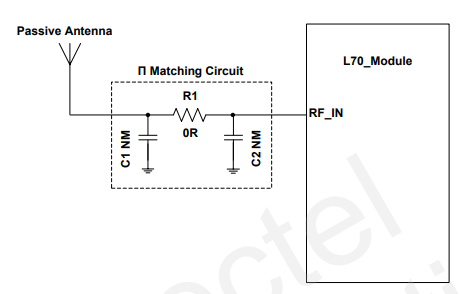
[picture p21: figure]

Hình 1. 27Sơ đồ thiết kế Passive Antenna without LNA

- Sử dụng Passive Antenna có bộ LNA: Thiết kế tương tự một bộ LNA(Low-noise Amplifier) được thêm vào để tăng độ nhạy, giúp cải thiện hiệu suất trong trường hợp tín hiệu yếu.

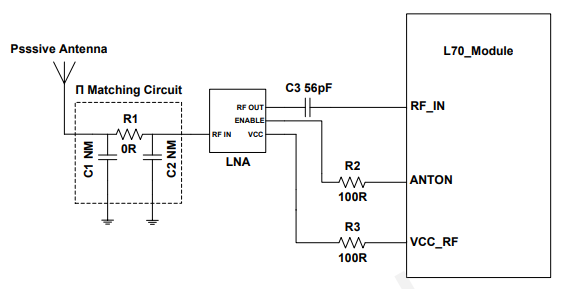
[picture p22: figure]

Hình 1. 28Sơ đồ thiết kế passive antenna with LNA

# 9. Khối RS232 và Debug

Trong quá trình phát triển firmware cho thiết bị, việc Debug là rất quan trọng. Khối RS232/Debug được thêm vào thiết bị nhằm các mục đích sau:

- Hỗ trợ quá trình Debug khi phát triển Firmware
- Bám sát yêu cầu của thiết bị GSHT: Cần có cổng RS232 để trích xuất dữ liệu.

Khối này sử dụng 2 bộ UART của MCU là UART5 cho khối Debug và UART2 cho khối RS232. IC được sử dụng là IC MAX232 của hãng MAXIM, giúp chuyển đổi mức điện áp TTL sang mức điện áp phù hợp với chuẩn RS232.

Hình 1. 29Sơ đồ nguyên lí khối RS232

Bộ Debug sử dụng IC CH340G, một IC thông dụng và rất phổ biến, độ ổn định cao, IC này giúp chuyển đổi giao tiếp Serial trên MCU (UART) sang giao tiếp USB trên máy tính giúp gửi dữ liệu từ cổng UART trên MCU lên máy tính qua cổng USB. Diode TSV được thêm vào để bảo vệ đường USB D+ và USB D-.

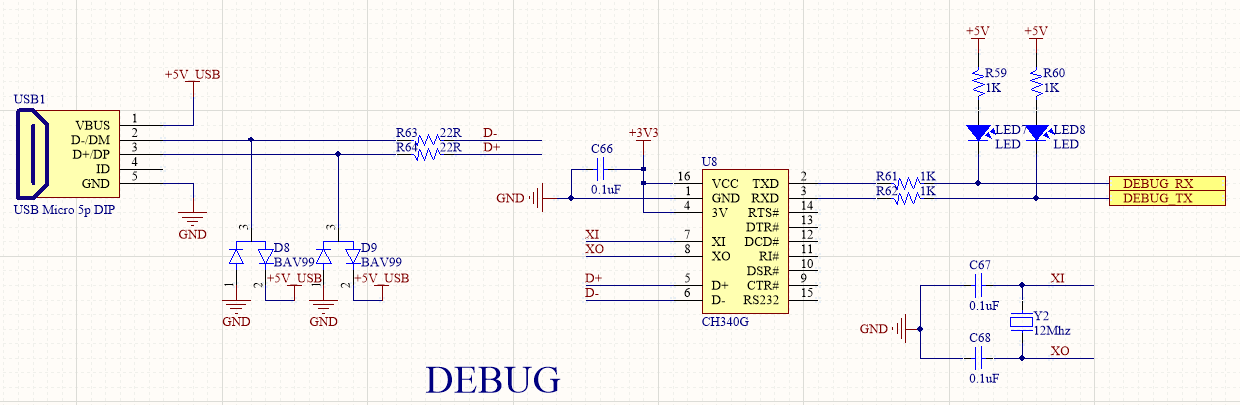
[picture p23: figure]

Hình 1. 30Sơ đồ nguyên lí khối Debug

# 10. Khối cảm biến

Để có thể đo được các thông số như nhiệt độ, độ ẩm môi trường thì em sử dụng cảm biến nhiệt độ - độ ẩm DHT11, và giám sát nhiệt độ của thiết bị em sử dụng cảm biến nhiệt độ DS18B20 với dải đo rộng. Đây là các cảm biến sử dụng giao tiếp 1-Wire. Việc đo, xử lí tính toán nhiệt độ sẽ do cảm biến tự tiến hành, nhiệm vụ của người lập trình đó là giao tiếp giữa MCU với các cảm biến này để đọc dữ liệu về.

Cảm biến DS18B20 sẽ được sử dụng để đo nhiệt độ của thiết bị, nhiệt độ của môi trường, còn cảm biến DHT11 được sử dụng để đo nhiệt độ, độ ẩm của môi trường. Hình dạng các cảm biến sử dụng được mô tả như hình dưới.

Cảm biến STRELA A là loại cảm biến được ứng dụng vào việc đo mức nhiên liệu của các xe oto cũng như các xe công trình nhằm kiểm soát được lượng nạp và rút nhiên liệu, tối ưu hóa được việc quản lí lộ trình xe đi và dừng, tránh được tình trạng trộm cắp nhiên liệu, đồng thời hình thành phong cách laais xe phù hợp nhằm tiết kiệm nhiên liệu, giảm phát thải các chất độc hại vào môi trường.

Hình 1. 31Các cảm biến sử dụng để đo nhiệt độ, độ ẩm và mức nhiên liệu

Thông số cơ bản của cảm biến DS18B20:

- Điện áp hoạt động 3-5.5VDC
- Dòng tiêu thụ ~1-1.5mA
- Chuẩn giao tiếp: Digital TTL 1-Wire. Dữ liệu truyền và nhận trên 1 đường dây duy nhất.
- Dải đo: -55°C - 125°C
- Độ chính xác: ±0.5°C
- Độ phân giải: 9-12bit có thể lập trình được.
- Thời gian chuyển đổi: 750ms ở độ phân giải 12bit.
- Hỗ trợ dạng đóng gói TO-92 và dạng dây kéo dài 1m chống nước có đầu bảo vệ bằng thép.

Thông số cơ bản của cảm biến DHT11:

- Điện áp hoạt động 3-5VDC
- Dòng tiêu thụ: tối đa 2.5mA
- Dải đo: 20-80%RH (±5%); 0-50°C (±2°C).
- Thời gian chuyển đổi: tối thiểu 1S
- Chuẩn giao tiếp: Digital TTL 1-Wire.

Thông số cơ bản của cảm biến mức STRELA A:

- Điện áp hoạt động 3-10VDC
- Dòng tiêu thụ 100mA
- Điện áp đầu ra dải từ 0-5V tương ứng với 0% và 100% mức nhiên liệu
- Đọc ADC đầu vào

Sơ đồ thiết kế khối cảm biến được mô tả như dưới. Trong đó cảm biến DS18B20 được mắc cùng trên 1 bus 1-Wire. 1 cảm biến phục vụ đo nhiệt độ của thiết bị, cảm biến còn lại đo nhiệt độ môi trường bên ngoài. Cảm biến DHT11 thì được mắc trên bus 1-wire khác nhằm đo nhiệt độ, độ ẩm môi trường xung quanh thiết bị. Cách mắc nối của cảm biến STRELA A cũng tương tự như 2 cảm biến trên. Tất cả các đường bus 1-wire đều được kéo lên VCC qua điện trở 4.7k do bus 1-wire được cấu hình ở dạng Open - drain Output. Do đó khi bus không được điều khiển bởi MCU thì cần được kéo lên VCC để giữ mức logic 1. Việc cấu hình bus 1-wire ở Open-Drain Output nhằm cho phép nhiều thiết bị hoạt động trên cùng 1 bus giống như chuẩn I2C.

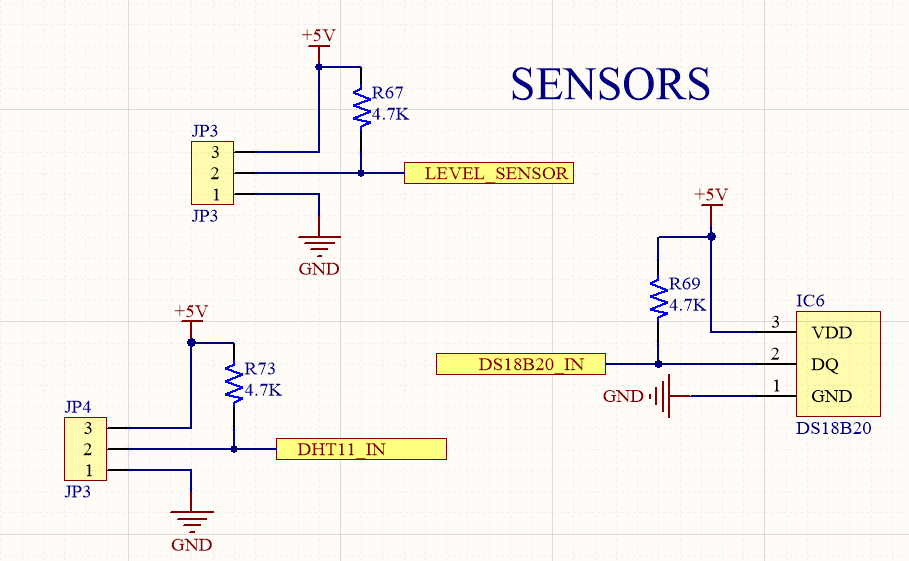
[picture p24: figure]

Hình 1. 32Sơ đồ khối cảm biến nhiệt độ, độ ẩm và đo mức

Điện áp của Ắc quy được đo thông qua ADC. Do điện áp ắc quy của xe có dải từ 12-36V, mà ADC của MCU STM32F103RCT6 có điện áp tham chiếu chỉ là 3.3V, hơn nữa nếu ta cấp thẳng điện áp trên 5V vào bất kì I/O nào của MCU đều có thể làm hư hỏng MCU. Do vậy cần một khối để chuyển đổi mức điện áp đầu vào của ắc quy để cấp cho ADC. Các đơn giản và dễ sử dụng nhất đó chính là sử dụng cầu phân áp, sơ đồ thiết kế được mô tả như hình dưới. Hai điện trở độ chính xác cao R_68 và R_70 tạo thành cầu chia áp, điện áp sau cầu chia áp sẽ nằm trong một dải nhất định phụ thuộc vào tỉ số giữa 2 điện trở phân áp.

Cụ thể là V_(OUT) = V_(IN) *(R_70)/(R_70 +R_68)

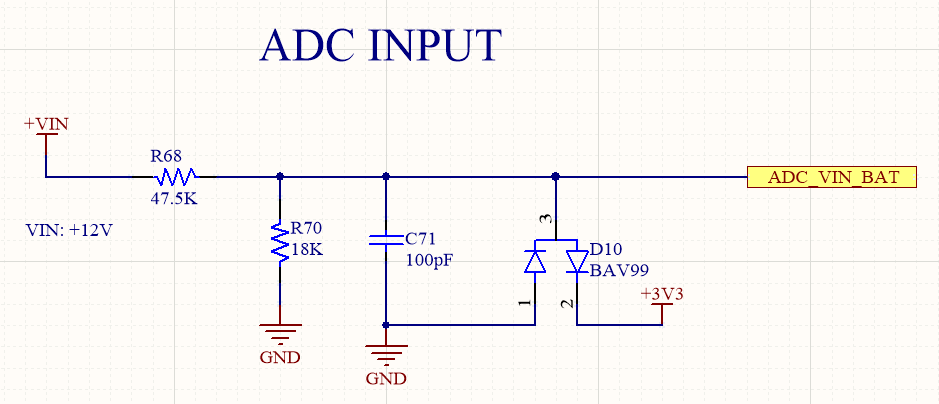
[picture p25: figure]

Hình 1. 33Sơ đồ khối mạch phân áp cho ADC

Chọn R70 = 18k, R71= 47.5k. Nếu VIN = 12VDC thì VOUT = 3.29V < 3.3V. Ngoài ra để bảo vệ cho điện áp trên chân ADC_INPUT luôn nằm trong khoảng từ 0-3.3V, TVS Diode được thêm vào để giữ cho điện áp trên chân ADC không vượt quá 3.3VDC, bảo vệ bộ ADC của MCU.

Việc đo tốc độ di chuyển của xe sẽ thông qua 2 phương án: Thứ nhất là dựa vào tốc độ đo được thông qua module GNSS, thứ 2 là đo trực tiếp thông qua cảm biến tiệm cận bằng phương pháp đếm xung. Phương án thứ 2 được sử dụng trong trường hợp thiết bị mất sóng GPS. Cảm biến tiệm cận được sử dụng để đo tốc độ là loại cảm biến tiệm cận NPN.

Hình 1. 34Cảm biến tiệm cận từ LJ12A3-4-Z/BX NPN

Một vài thông số chính của cảm biến như sau:

- Điện áp hoạt động: 6 ~ 36Vdc

- Dòng đầu ra: 300mA

- Phát hiện kim loại, khoảng cách tối đa 4mm

- Đường kính cảm biến: 12mm

- Ngõ ra NPN 3 Dây, NO

- Đối tượng phát hiện: Kim loại/sắt

Sơ đồ thiết kế mạch được mô tả hình dưới. Sử dụng Opto PC817 để cách li tín hiệu đầu ra cảm biến với chân I/O của MCU, giúp bảo vệ MCU khi có sử cố từ cảm biến. Đầu ra của cảm biến là dạng Open - Collector, được mắc với chân K của Opto PC817, chân A của opto được mắc với nguồn 12V cấp chung cho cảm biến tiệm cận. Chân C của Opto được mắc lên nguồn 3V3 để giữ mức logic 1, chân E của Opto được mắc xuống GND. Khi cảm biến phát hiện kim loại, đầu ra của nó ở mức điện áp 12V, không có dòng chạy qua Led hồng ngoại của opto, phototransitor không dẫn, đầu ra DATA_IN ở mức logic 1. Khi cảm biến không phát hiện kim loại, đầu ra của nó ở mức logic 0V, có dòng chạy qua led hồng ngoại của opto, phototransistor dẫn, đầu ra DATA_IN ở mức logic 0.

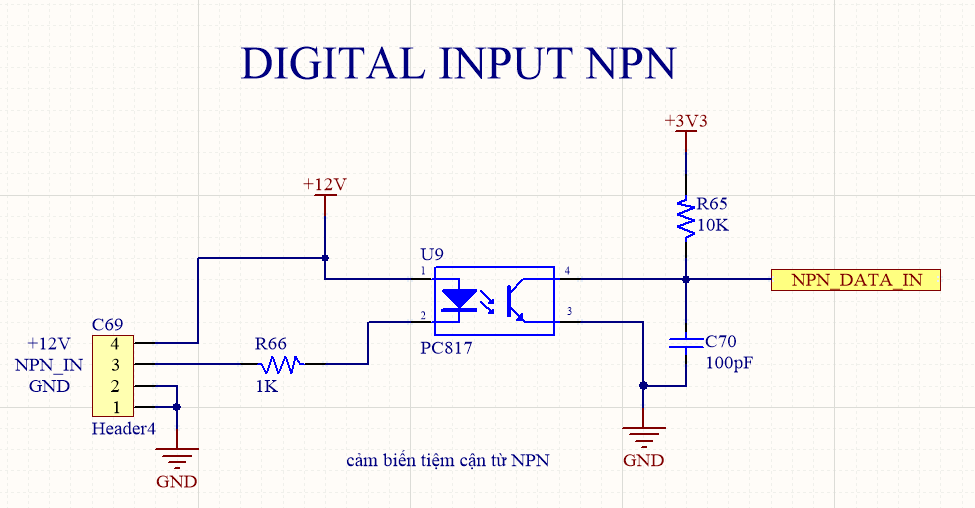
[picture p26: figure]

Hình 1. 35Sơ đồ nguyên lí cảm biến tiệm cận NPN

Nguyên lí đo tốc độ sử dụng cảm biến tiệm cận: Sử dụng một đĩa có dạng giống đĩa encoder đục lỗ gắn đồng trục với bánh xe của xe. Đặt cảm biến gần sát đĩa, khi đĩa quay, tại các điểm bị đục lỗ, cảm biến không phát hiện được kim loại, từ đó thay đổi mức logic đầu ra. Đếm xung đầu ra của cảm biến trong một đơn vị thời gian, căn cứ theo số xung đếm được trong 1 giây, chu vi đĩa encoder, hệ số truyền từ bánh xe đến đĩa encoder ta có thế tính toán ra được tốc độ quay của bánh xe, từ đó tính ra vận tốc di chuyển của xe.

Hình 1. 36Đo tốc độ bằng cảm biến tiệm cận NPN

Dựa theo hãng sản xuất, 4 tụ điện ceramic 33pF/10pF/0.1uF/1uF được sử dụng để lọc nguồn cấp vào chip và tăng hiệu suất của RF.

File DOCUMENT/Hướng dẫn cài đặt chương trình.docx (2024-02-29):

Hướng dẫn cài đặt chương trình

A1. Cài đặt môi trường làm việc

A1.1 Cài đặt IDE Visual Studio Code

Visual Studio Code (VS Code) là một trình soạn thảo mã nguồn mở và miễn phí, được phát triển bởi Microsoft. Được thiết kế để hỗ trợ nhiều ngôn ngữ lập trình và nền tảng, VS Code đã trở thành một trong những trình soạn thảo mã nguồn phổ biến nhất trong cộng đồng phần mềm.

Truy cập vào đường link sau: https://code.visualstudio.com/download, để tải môi trường lập trình IDE cho dự án.

A1.2. Cài đặt Extensions cho dự án

Khi hoàn thành việc cài đặt IDE, tiếp theo là cài đặt Extensions để hỗ trợ lập trình cho chip STM32 với ngôn ngữ C/C++, các bước lần lượt như sau:

Bước 1: Cài đặt ngôn ngữ C/C++ cho môi trường


Hình A- 1 Tiện ích cho ngôn ngữ C/C++

Bước 2: Cài đặt gói cho chip STM32


Hình A- 2 Tiện ích cho chip STM32

Bước 3: Cài đặt MakeFile để build chương trình


Hình A- 3 Tiện ích cho Makefile

A1.3. Cài đặt Driver ST - Link hỗ trợ nạp chương trình

Sau khi thiết kế xong firmware, việc tiếp theo là nạp chương trình và debug thông qua Driver có sẵn do hãng ST của chip hỗ trợ. Đường dẫn để cài đặt Driver sau: https://www.st.com/en/development-tools/stsw-link009.html.

A1.4. Viết file Json và Makefile cho dự án

Do Vscode là môi trường mở và đa nền tảng nên việc trích tới đường dẫn file build và chạy chương trình là cần thiết và do người dùng tự viết. Với dự án này em thiết kế như sau:


Hình A- 4 Thiết kế file Json cho trích xuất đường dẫn


Hình A- 5 Thiết kế Makefile để chạy chương trình

A2. Hướng dẫn sử dụng thiết bị

- Bước 1: Lắp đặt các thành phần phụ kiện như Anten GPS, Anten 4G, các cảm biến, Pin RTC, màn hình Oled, quạt tản nhiệt vào thiết bị như Hình A- 6.
- Bước 2: Cấp nguồn cho thiết bị bằng cách cắm nguồn Accqui từ xe vào thiết bị như Hình A- 7.
- Bước 3: Sau khi cấp nguồn, đợi khoảng 30 giây để thiết bị khởi động, kết nối mạng 4G, kết nối GPS. Nếu khởi động và kết nối thành công, đèn Led hiển thị trạng thái thiết bị bao gồm trạng thái làm việc vị trí số 1 (sáng liên tục), trạng thái sóng 4G vị trí số 2, GPS vị trí số 3 sẽ nhấp nháy với chu kì lần lượt là 0.5 giây và 1 giây như Hình A- 8.
- Bước 4: Sau khi thấy Led hiển thị theo chu kì đó, nghĩa là thiết bị đã sẵn sàng để hoạt động trong suốt quá trình xe hoạt động. Thiết bị sẽ thu thập thông tin rồi xử lí sau đó gửi lên DashBoard để hiển thị và giám sát dữ liệu và thông tin như Hình A- 8. Nếu xe dừng hẳn sau 1 thời gian, thiết bị sẽ vào trạng thái ngủ đông để tiết kiệm năng lượng.


Hình A- 6 Lắp đặt các thành phần vào thiết bị


Hình A- 7 Phần cấp nguồn từ Accqui vào thiết bị


Hình A- 9 Đèn Led hiển thị trạng thái


Hình A- 8 Giao diện theo dõi thiết bị

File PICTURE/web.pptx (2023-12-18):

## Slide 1


Access Token

Các Device được tạo thành công

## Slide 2


Các bản tin nhận được

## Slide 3


Khu vực hiện vị trí thiết bị

Khu vực hiện trạng thái thiết bị

Khu vực hiện nhiệt độ, độ ẩm môi trường

Khu vực hiện danh sách thiết bị

Khu vực hiện nhiệt độ thiết bị

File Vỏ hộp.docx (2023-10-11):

Đây là bản mạch của ae mũi tên tương ứng với khoảng cách của từng vật thể, ae có đính kèm ảnh 1 mẫu thiết kế hơi giống cái ae đang muốn thiết kế:


Mặt trước và sau nó trông như thế này (cái này ae tham khảo từ 1 hộp có trước):


Mặt trước


Mặt sau


Vỏ nhìn từ trên xuống


Vỏ trên là mặt sau, dưới là mặt trước

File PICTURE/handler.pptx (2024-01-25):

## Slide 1


Quá trình truyền nhận tốt

Kiểm tra chức năng và trạng thái của simCard

Kiểm tra cường độ tín hiệu của mạng

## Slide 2


Cho phép kết nối bằng MQTT

Kết nối tới Broker với Idclient và địa chỉ Broker cổng com 1883

Chọn Topic “Test1z” để gửi bản tin thử nghiệm “123456789”

Chọn Topic “Test1z” để nhận bản tin thử nghiệm “123456780” từ 1 client khác

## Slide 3


Bản tin phản hồi dạng đầy đủ

Vị trí tọa độ đã được xử lý

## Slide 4


Khối nguồn

Khối MCU

Khối SIM 4G

Khối RS232

Khối GPS và Debug

Khối cảm biến và hiển thị

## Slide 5


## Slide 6


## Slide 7


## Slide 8


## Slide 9


Bộ xử lý

Nguồn Accquy

Anten

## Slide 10


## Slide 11

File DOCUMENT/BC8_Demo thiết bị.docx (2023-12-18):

BÁO CÁO TIẾN TRÌNH ĐỒ ÁN TỐT NGHIỆP (8)

Nguyễn Huy Hoàng_20191855_Tự động hóa 06 - K64

# 1. Thiết kế vỏ hộp

Ở báo cáo 2, đồ án đã trình bày các yêu cầu về vỏ hộp thiết bị, từ những yêu cầu đó, em sẽ sử dụng nhựa để làm vỏ hộp vì những ưu điểm sau:

- Dễ gia công, sử dụng công nghệ in 3D.
- Giá thành rẻ, phổ biến.
- Trọng lượng nhẹ, khả năng chịu lực cao, sử dụng loại nhựa ABS

Vỏ hộp được thiết kế trên phần mềm Solid Work, sau đó gia công bằng in 3D để tạo mẫu. Thiết kế 3D của vỏ hộp được trình bày như hình dưới:


Vỏ hộp dạng 3D được thiết kế trên SolidWork

Phần vỏ hộp bao gồm phần thân vỏ, 2 cạnh bên ốp và lắp trên, phần mạch sẽ đặt cố định ở bên trong phần thân vỏ. Phần cạnh bên sẽ có các lỗ antenna, đèn báo và cổng cắm. thiết kế 2D của các phần được mô tả như hình sau:


Thiết kế phần mặt trước và sau của hộp


Thiết kế phần mặt đáy của hộp

# 2. Kết quả gia công

Kết quả sau khi gia công phần thân và cách cạnh của vỏ hộp.


Mặt trên có màn hình hiển thị OLED 0.96inch


Mặt sau của vỏ hộp


Kết quả đóng hộp thiết bị

# 3. Demo sản phẩm

Link video:

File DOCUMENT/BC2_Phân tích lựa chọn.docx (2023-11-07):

BÁO CÁO 2

Nguyễn Huy Hoàng - Tự động hóa 06 – K64

# 1. Vạch kĩ các chức năng hoạt động

Sau khi tìm hiểu và tổng hợp thông tin trong QCVN 31: 22014 của BGTVT em đưa ra các chức năng sau:

1) Xác định tài xế thông qua RFID, thời điểm bắt đầu và kết thúc phiên làm việc, từ đó xác định thời gian làm việc liên tục của tài xế (việc đăng nhập/đăng xuất chỉ thực hiện khi xe dừng).
2) Cảnh báo đối với lái xe khi quá tốc độ và thời gian lái xe liên tục quá 4h hoặc tổng thời gian làm việc của cùng 1 người là quá 10h/ ngày.
3) Lưu trữ các thông số đo được vào bộ nhớ bao gồm cả thời gian, tọa độ, tốc độ. Tần suất ghi và lưu không quá 30 giây/ lần khi xe hoạt động và không quá 15 phút/ lần khi xe dừng. Cho phép trích xuất dữ liệu từ bộ nhớ qua phần mềm của bộ GTVT.
4) Xác định vị trị của xe và gửi lên Server thông qua Module GNSS, Module Sim (4G LTE).
5) Đo tốc độ di chuyển thông qua GNSS hoặc qua cảm biến tiệm cận, từ đó xác định được thời gian và quãng đường di chuyển cũng như số lần thời gian dừng, đỗ xe.
6) Đo thông số về môi trường như nhiệt độ độ ẩm, điện áp làm việc của ắc quy, mức nhiên liệu (dầu hoặc xăng) của xe.
7) Gửi tất cả các thông số đo được lên server. Web hiển thị bản đồ vị trí của thiết bị, danh sách trạng thái thiết bị(dừng/đỗ, biển số xe, thông tin lái xe, tốc độ xe, phiên làm việc, số lần đỗ), số thiết bị online, offline, giao diện theo dõi nhiệt độ, độ ẩm và mức nhiên liệu, .
8) Cho phép cấu hình từ server, bao gồm: tần suất gửi của nhiệt độ thiết bị, nhiệt độ, độ ẩm môi trường, mức nhiên liệu, gửi vị trí thiết bị, gửi điện áp ắc quy, giới hạn và thời gian gửi tốc độ xe.
9) Hiển thị trạng thái làm việc, trạng thái GPS, trạng thái kết nối với server, tình trạng bộ nhớ thông qua màn hình hoặc đèn led.
10) Trích xuất, sao lưu truyền dữ liệu từ thiết bị qua cổng kết nối RS232.
11) OTA cập nhật firmware trên thiết bị từ máy chủ khi có yêu cầu.

Yêu cầu với giao diện Web Server:

- Đối với giao diện web: cần phải thân thiện, dễ sử dụng, phải đảm bảo các chức năng cơ bản đó là:
- Hiển thị các thông tin từ thiết bị gửi lên bao gồm giao diện hiển thị bản đồ vị trí của thiết bị, danh sách trạng thái thiết bị(dừng/đỗ, biển số xe, thông tin lái xe, tốc độ xe, phiên làm việc, số lần đỗ), số thiết bị online, offline, giao diện theo dõi nhiệt độ, độ ẩm và mức nhiên liệu.
- Vẽ lại hành trình di chuyển của thiết bị.
- Trích xuất dữ liệu hành trình.
- Quản lí được thời gian làm việc của lái xe, thời gian, số lần dừng đỗ, thời gian khởi hành và kết thúc.
- Cấu hình thiết bị từ server bao gồm: tần suất gửi của nhiệt độ thiết bị, nhiệt độ, độ ẩm môi trường, mức nhiên liệu, gửi vị trí thiết bị, gửi điện áp ắc quy, giới hạn và thời gian gửi tốc độ xe.
- Cảnh báo sử dụng thất thường nhiên liệu.
- Đối với server, yêu cầu phải có khả năng xử lí được luồng dữ liệu từ nhiều thiết bị gửi lên.
- Đối với database: yêu cầu phải có khả năng lưu trữ thông tin về phiên làm việc của lái xe; lộ trình của xe, các thông tin về lịch trình lái trong ít nhất 30 ngày; các thông tin thu được từ các cảm biến được thiết bị gửi lên cũng phải được lưu lại.

# 2. Sơ đồ hệ thống

Chọn phương án thiết kế tổng thể: Mỗi xe gắn 1 thiết bị quản lý, hoạt động độc lập với nhau, kết nối chung về 1 Server quản lí để truyền/ nhận dữ liệu


Sơ đồ tổng quan giải pháp thiết kế hệ thống

# 3. Phân tích lựa chọn đáp ứng yêu cầu

Đối với mô hình kết nối từ các thiết bị gắn xe với server, em lựa chọn các giao thức dựa trên mô hình bảy tầng OSI.


Mô hình 7 tầng OSI

Trong 7 tầng, em sẽ lựa chọn các giao thức liên quan đến đồ án như sau:

- Lựa chọn giao thức tầng vật lí (Physical Layer):

Như đã trình bày ở trên, đồ án lựa chọn sử dụng mạng 4G LTE để truyền nhận dữ liệu với server.

- Lựa chọn giao thức tầng giao vận (Transport Layer):

Đồ án lựa chọn sử dụng giao thức TCP để đảm bảo dữ liệu được truyền toàn vẹn và đáng tin cậy giữa server và thiết bị.

- Lựa chọn giao thức tầng ứng dụng (Application):

Mặc dù sử dụng giao thức TCP, ta đã có thể kết nối và trao đổi dữ liệu giữa server và thiết bị, nhưng khi đó, khối lượng công việc sẽ lớn do phải xử lý thêm các gói tin ở tầng giao vận, bên cạnh công việc xử lý của tầng ứng dụng.

Hơn nữa, hiện nay đã có nhiều giao thức ở tầng ứng dụng đã giúp ta xử lý các gói tin TCP, đã và đang được sử dụng rộng rãi như HTTP, MQTT, …

Do khả năng xử lý hạn chế của các thiết bị phần cứng so với máy tính, cũng như băng thông mạng hạn chế và không ổn định, nên việc đảm bảo các gói tin phải có kích thước nhỏ gọn, và giao thức tiêu tốn ít băng thông. Và MQTT đã ra đời để phục vụ mục đích đó, do vậy, đồ án sẽ em sẽ lựa chọn giao thức MQTT.

Từ thiết kế tổng quan và các yêu cầu chức năng trên, em đi vào thiết kế các khối trong thiết bị thu thập thông tin hiện trường (gọi tắt là thiết bị giám sát máy công trình). Em chia hệ thống trong mỗi thiết bị thành các khối như sau:


Sơ đồ thiết kế thiết bị giám sát máy công trình

Chức năng của từng khối được trình bày ngắn gọn như sau:

- Khối 1 - Khối nguồn: Đây được coi là trái tim của toàn thiết bị, quyết định đến sự vận hành ổn định của thiết bị sau này. Khối này nhận điện áp trực tiếp từ ắc quy của xe công trình( 12-24-36VDC) sau đó chuyển đổi thành các mức điện áp phù hợp để cung cấp cho các thành phần khác của thiết bị.
- Khối 2 – Khối hiển thị, thông báo: Đây là khối giúp cho người vận hành xe/máy công trình biết được trạng thái hoạt động của thiết bị cũng như thông báo các thông tin đến người vận hành. Khối này bao gồm hệ thống đèn led báo trạng thái ( Nguồn, GPS, 4G LTE, RFID); màn hình Oled 1.3” và Còi buzzer.
- Khối 3 – Khối Flash/SD Card : Đối với mỗi thiết bị giám sát, việc lưu trữ thông tin giám sát cần phải thực hiện liên tục trong tối thiểu 30 ngày để phục vụ cho việc sử dụng sau này. Do đó khối này có nhiệm vụ lưu trữ các thông tin về tốc độ, vị trí của xe 24/24 trong vòng tối thiểu 30 ngày. Ngoài ra còn lưu trữ một số thông tin khác về xe, về thiết bị cũng như thông tin người lái. Em sử dụng thẻ SDcard kết hợp với chip nhớ flash tốc độ cao để lưu trữ các thông tin này.
- Khối 4 – Khối RFID: Đây là khối giúp nhận dạng được người lái. Để có thể nhận dạng được người dùng là ai, có rất nhiều công nghệ phổ biến hiện nay có thể kể đến như dùng thẻ RFID, sử dụng vân tay, sử dụng mã QR/mã vạch, hay nhập mật khẩu cá nhân. Sau khi phân tích các hình thức trên thì em lựa chọn sử dụng thẻ RFID do tính tiện lợi, dễ sử dụng và thiết kế cũng như độ bảo mật là tương đối cao. Ở đây em sử dụng Đầu đọc RFID tần số hoạt động 13.56Mhz theo quy chuẩn kĩ thuật quốc gia về thiết bị GSHT.
- Khối 5 – Khối MCU: Đây có thể coi là bộ não của thiết bị, xử lí/tính toán các công việc đã được lập trình trước. Để đáp ứng các yêu cầu về tốc độ, ngoại vi thì em sẽ lựa chọn sử dụng chip ARM Cortex M3 của ST, cụ thể là STM32F103RCT6.
- Khối 6 – Khối cảm biến IN/OUT: Đây là khối phục vụ việc chuẩn hóa, nhận tín hiệu từ các cảm biến để đưa vào MCU.
- Khối 7 – Khối RS232/Debug: Khối này nhằm gửi các thông tin phục vụ yêu cầu đọc dữ liệu từ phần mềm phân tích dữ liệu của bộ GTVT.
- Khối 8 – Khối 4G LTE: Khối này phục vụ việc trao đổi dữ liệu giữa thiết bị với server thông qua mạng 4G LTE. Ở đây em lựa chọn Module SIM7672 của SIMCOM.
- Khối 9 – Khối GNSS: Khối này phục vụ việc định vị về vị trí của thiết bị thông qua hệ thống định vị toàn cầu GPS. Ở đây em lựa chọn module GPS L70 của QUECTEL.

Hình dưới thể hiện rõ chi tiết các giao thức liên kết giữa từng khối với nhau trong thiết bị.


Các giao thức sử dụng

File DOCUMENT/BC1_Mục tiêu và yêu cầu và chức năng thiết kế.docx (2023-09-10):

Mục tiêu, các yêu cầu và chức năng thiết kế của đồ án tốt nghiệp

Kỳ 2023.1

Nguyễn Huy Hoàng - Tự động hóa 06 – K64

# 1. Mục tiêu thiết kế

Đề tài “Thiết kế thiết bị thu thập thông tin hiện trường ứng dụng trong hệ thống quản lí giám sát xe công trình” dựa theo quy chuẩn QCVN 31: 2014 của BGTVT về thiết bị giám sát hành trình của ô tô nhằm những mục đích sau:

- Tạo ra một thiết bị có khả năng thu thập các thông tin hiện trường bao gồm:

• Nhiệt độ/ độ ẩm môi trường làm việc.

• Nhiệt độ làm việc của thiết bị.

• Điện áp làm việc của ắc quy xe.

• Tọa độ và tốc độ của xe.

• ID của người vận hành.

• Thông tin về xe.

• Thông tin về thời gian khởi động/ kết thúc phiên làm việc của xe.

- Gửi các thông tin thu thập được lên hệ thống quản lí, giám sát riêng của doanh nghiệp.
- Đối tượng áp dụng của đề tài này là những loại xe làm việc tại công trường xây dựng, nơi có điều kiện làm việc khắc nghiệt.


Thiết bị giám sát hành trình của Viettel VTR02

# 2. Cấu tạo chung của một thiết bị giám sát hành trình.

Thiết bị giám sát hành trình là một thiết bị đóng gói hoàn chỉnh nên còn gọi là hộp đen. Cấu tạo chung của phần cứng bao gồm các bộ phận chính như sau.


Thiết bị giám sát hành trình của Viview VT06

- Bộ xử lý trung tâm: Thu thập, xử lí dữ liệu, điều khiển mọi hoạt động của thiết bị. Đây có thể là bất kì một bộ vi điều khiển 8/16/32 bit nào. Hiện nay phổ biến nhất là sử dụng các vi điểu khiển lõi ARM 32 bit.
- Bộ phận lưu trữ thông tin: Lưu trữ các thông tin thu thập được trong suốt quá trình thiết bị vận hành nhằm phục vụ mục đích lưu trữ, sử dụng trong tương lai. Các thông tin được lưu trữ bao gồm : Thông tin lái xe; Thông tin của xe; Thời gian vận hành/kết thúc phiên làm việc; Hành trình của xe; Tốc độ của xe. Các phương pháp lưu trữ đang được sử dụng là sử dụng thẻ nhớ SDCard hoặc chip nhớ Flash.
- Bộ phận GPS: Nhiệm vụ là xác định vị trí ( Kinh độ, vĩ độ) và vận tốc di chuyển của xe.
- Bộ phận 2G/3G/4G: Nhiệm vụ là tạo ra kết nối TCP/IP thông qua hệ thống mạng 2G/3G/4G giúp cho thiết bị với máy chủ có thể giao tiếp, trao đổi dữ liệu với nhau trong suốt quá trình hoạt động.
- Bộ phận nhận diện lái xe: Nhiệm vụ là xác định thông tin lái xe thông qua RFID hoặc Camera.
- Bộ phận truyền thông RS232/485: phục vụ việc truy xuất dữ liệu được lưu trữ ngay tại thiết bị.
- Ngoài ra để thiết bị hoạt động được thì cần có các khối đảm nhiệm việc cung cấp nguồn điện, khối nhận dữ liệu đầu vào từ các cảm biến và khối đầu ra để điều khiển các cơ cấu chấp hành.

Yêu cầu với giao diện Web Server:

- Đối với giao diện web: cần phải thân thiện, dễ sử dụng, phải đảm bảo các chức năng cơ bản đó là:
- Hiển thị các thông tin từ thiết bị gửi lên bao gồm thông tin về nhiệt độ, độ ẩm, tốc độ, trạng thái hoạt động của thiết bị, vị trí của xe gắn thiết bị, …
- Vẽ lại hành trình di chuyển của thiết bị.
- Trích xuất dữ liệu hành trình.
- Quản lí được thời gian làm việc của lái xe.
- Cấu hình thiết bị từ server
- Đối với server, yêu cầu phải có khả năng xử lí được luồng dữ liệu từ nhiều thiết bị gửi lên.
- Đối với database: yêu cầu phải có khả năng lưu trữ thông tin về phiên làm việc của lái xe; lộ trình của xe, các thông tin về lịch trình lái trong ít nhất 30 ngày; các thông tin thu được từ các cảm biến được thiết bị gửi lên cũng phải được lưu lại.

Đối với vỏ hộp, yêu cầu như sau:

- Có kết cấu chắc chắn, phải có khả năng bảo vệ phần mạch bên trong khỏi các tác nhân bên ngoài như nhiệt độ, độ ẩm, bụi, rung lắc
- Khả năng chịu lực cao. Không bị nứt vỡ khi chịu ngoại lực mạnh tác động vào.
- Tính thẩm mĩ
- Khả năng lắp đặt vào xe.

# 3. Các chức năng cơ bản và cách thức hoạt động của thiết bị

Chức năng hoạt động:

1) Xác định tài xế thông qua RFID, thời điểm bắt đầu và kết thúc phiên làm việc, từ đó xác định thời gian làm việc liên tục của tài xế (việc đăng nhập/đăng xuất chỉ thực hiện khi xe dừng).
2) Cảnh báo đối với lái xe khi quá tốc độ; thời gian lái xe liên tục quá 4h hoặc tổng thời gian làm việc của cùng 1 người lá quá 10h/ ngày.
3) Lưu trữ các thông số đo được vào bộ nhớ bao gồm cả thời gian, tọa độ, tốc độ. Tần suất ghi và lưu không quá 30 giây/ lần khi xe hoạt động và không quá 15 phút/ lần khi xe dừng. Cho phép trích xuất dữ liệu từ bộ nhớ qua phần mềm của bộ GTVT.
4) Xác định vị trị của xe và gửi lên Server thông qua Module GNSS, Module Sim (4G LTE).
5) Đo tốc độ di chuyển thông qua GNSS hoặc qua cảm biến tiệm cận, từ đó xác định được thời gian và quãng đường di chuyển cũng như số lần thời gian dừng, đỗ xe.
6) Đo thông số về môi trường như nhiệt độ độ ẩm, điện áp làm việc của ắc quy, mức nhiên liệu (dầu hoặc xăng) của xe.
7) Gửi tất cả các thông số đo được lên server. Web hiển thị bản đồ vị trí của thiết bị, danh sách trạng thái thiết bị(dừng/đỗ, biển số xe, thông tin lái xe, tốc độ xe, phiên làm việc, số lần đỗ), số thiết bị online, offline, giao diện theo dõi nhiệt độ, độ ẩm và mức nhiên liệu, .
8) Cho phép cấu hình từ server, bao gồm: tần suất gửi của nhiệt độ thiết bị, nhiệt độ, độ ẩm môi trường, mức nhiên liệu, gửi vị trí thiết bị, gửi điện áp ắc quy, giới hạn và thời gian gửi tốc độ xe.
9) Hiển thị trạng thái làm việc, trạng thái GPS, trạng thái kết nối với server, tình trạng bộ nhớ thông qua màn hình hoặc đèn led.
10) Trích xuất, sao lưu truyền dữ liệu từ thiết bị qua cổng kết nối RS232.
11) OTA

Ngoài ra thiết bị phải đáp ứng các yêu cầu sau:

- Khả năng làm việc ổn định trong thời gian dài ở điều kiện khắc nghiệt. (Nhiệt độ và độ ẩm thay đổi; bụi; rung lắc; …)
- Khả năng kết nối ổn định với server.
- Khả năng lưu trữ dữ liệu trong thời gian tối thiểu 30 ngày.

Cách thức hoạt động của thiết bị:

Khi thiết bị được gắn lên xe, nó được cấp nguồn trực tiếp từ ắc quy của xe. Khi chưa đăng nhập tài xế, thiết bị sẽ liên tục đo các thông số và gửi lên server để theo dõi và lưu lại. Khi có tài xế đăng nhập qua RFID, thiết bị sẽ đợi phản hồi từ server xem ID đó có hợp lệ không, nếu ID hợp lệ thì tài xế đã đăng nhập phiên làm việc thành công. Khi này thiết bị sẽ bắt đầu tính toán thời gian làm việc cho đến khi tài xế quẹt thẻ RFID lần nữa để đăng xuất. Thông tin đăng xuất cũng như thời gian làm việc của tài xế sẽ được đồng bộ lên server.

Tần suất gửi thông tin lên server được cấu hình từ server tùy theo từng thời điểm trong ngày. Cụ thể khi xe không di chuyển trong thời gian dài thì tần suất gửi thông tin sẽ giảm đi đồng thời tắt các ngoại vi không cần thiết để tiết kiệm năng lượng.

# 4. Phương án thiết kế tổng thể

Khi thiết kế hệ thống thu thập thông tin hiện trường, em dựa trên cơ sở của một hệ thống giám sát hành trình cho xe ô tô thông thường. Do đó, hệ thống bao gồm rất nhiều các thiết bị thu thập thông tin gắn trên các xe cần giám sát ở công trường. Từ đó em đưa ra 2 phương án thiết kế như sau:

- Phương án 1: Mỗi xe sẽ gắn một thiết bị để quản lí, thu thập thông tin, các thiết bị ở mỗi xe sẽ giao tiếp với nhau và truyền lên một thiết bị chính để đẩy dữ liệu lên server.

- Phương án 2: Mỗi xe sẽ gắn một thiết bị để quản lí, Các thiết bị này hoạt động độc lập với nhau, có khả năng kết nối chung về một server quản lí để truyền/nhận dữ liệu, phục vụ cho hệ thống quản lí, giám sát bên trên.

Đối với phương án thứ nhất, các thiết bị muốn giao tiếp với nhau thì chúng cần phải chung một chuẩn giao tiếp, ở đây có thể dùng các chuẩn giao tiếp không dây phổ biến như wifi, lora, hoặc zigbee. Tuy nhiên yêu cầu chung của các chuẩn giao tiếp không dây này đó là các thiết bị phải nằm trong phạm vi cho phép của chuẩn giao tiếp đó, từ đó dẫn đến hạn chế về phạm vi mà các thiết bị này có thể giao tiếp với nhau. Ngoài ra, khi thiết kế hệ thống theo hướng này thì yêu cầu hệ thống cần có thêm bộ gateway để xử lí dữ liệu. Việc này sẽ làm tăng chi phí của hệ thống và làm tăng độ trễ do các thiết bị phải trao đổi với server thông qua gateway. Do vậy phương án thứ nhất này không được tối ưu.

Đối với phương án thứ hai, cũng là phương án mà đồ án sẽ sử dụng, các thiết bị hoạt động độc lập và kết nối độc lập với server. Do vậy việc gửi dữ liệu lên server cũng như nhận và xử lí lệnh từ server xuống cũng đáp ứng rất nhanh. Ngoài ra trong phương án này, các thiết bị sẽ không sử dụng các chuẩn truyền không dây thông thường như ở phương án một mà sẽ sử dụng mạng LTE 4G để truyền/nhận dữ liệu với server. Do đó phạm vi hoạt động sẽ rất lớn, bất kì ở đâu chỉ cần phủ sóng LTE 4G thì ở đó thiết bị đều có thể hoạt động được. Có thể thấy phương án này khắc phục hoàn toàn những nhược điểm đã nêu ra ở phương án thứ nhất.

Thiết bị giám sát máy công trình có nhiệm vụ đọc các thông tin về nhiệt độ, độ ẩm thông qua các cảm biến; thông tin về điện áp ắc quy thông qua ADC; thông tin về người lái xe thông qua RFID; thông tin về vị trí thông qua module GPS; thông tin về tốc độ thông qua cảm biến tiệm cận và GPS, sau đó xử lí, hiển thị qua hệ thống loa, đèn, màn hình, lưu trữ vào hệ thống thẻ SDcard và bộ nhớ flash, gửi lên server thông qua module Sim LTE 4G với chu kì gửi có thể cài đặt trực tiếp từ trên server.

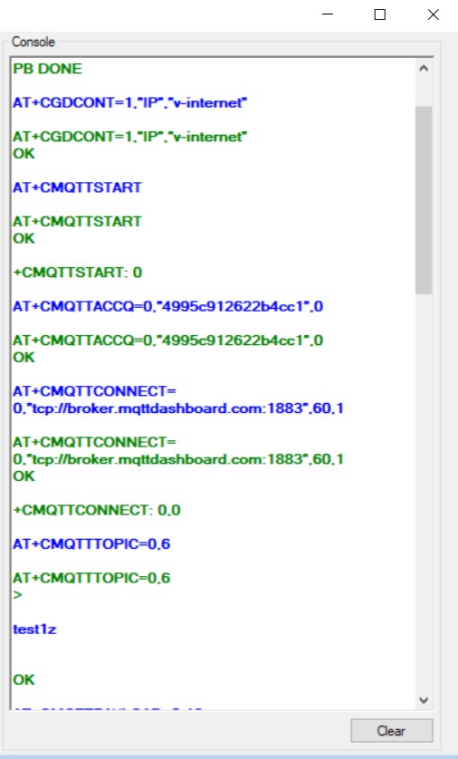
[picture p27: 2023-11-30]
PICTURE/sim/mqtt1.jpg

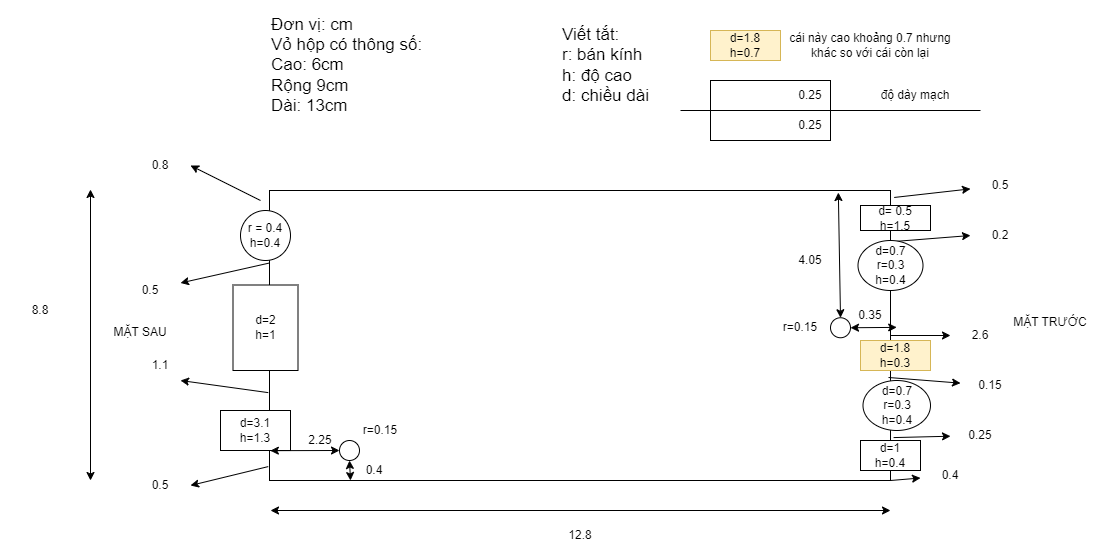
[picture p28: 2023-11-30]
ĐATN-Vỏ.drawio.png

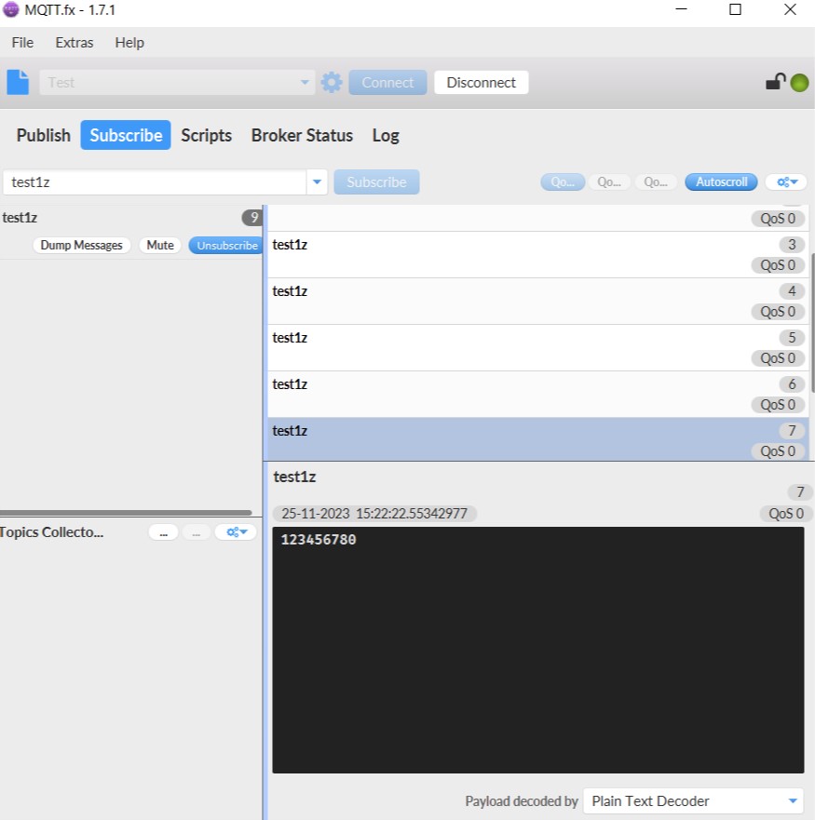
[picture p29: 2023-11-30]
PICTURE/sim/mqtt_v4.jpg

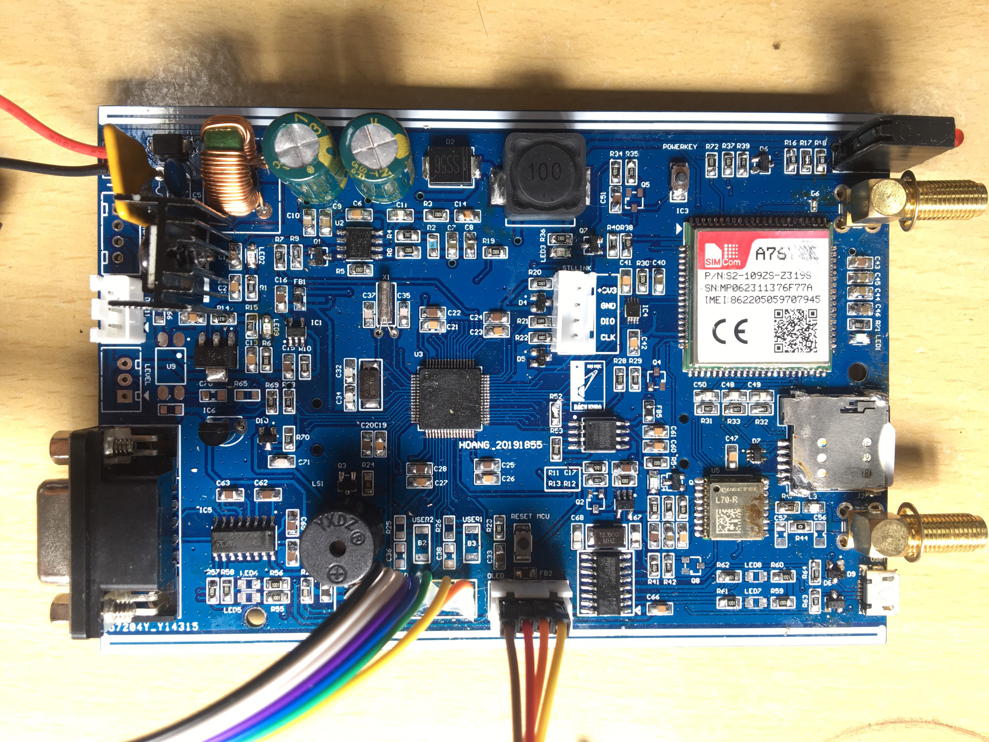
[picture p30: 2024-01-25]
PICTURE/pcb/8b4e9e9893e63bb862f73.jpg

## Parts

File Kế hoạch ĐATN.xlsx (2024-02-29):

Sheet: Kế hoạch
Hoàn thiện tất cả trước tháng 2/ 2024. 29/1/2024 nghỉ tết 19/2 bắt đầu bảo vệ (Dự kiến hoàn thiện 23 tuần từ ngày 18/8/2023)
 | Công việc | Nội dung công việc | Thời gian thực hiện | Ghi chú
Tuần 1 | - Đưa ra mục tiêu thiết kế - Liệt kê các yêu cầu thiết kế, chức năng - QCVN 31: 2014 BGTVT - Phần cứng, Server Web, Vỏ hộp | - Mục tiêu Thiết kế thiết bị thu thập thông tin hiện trường ứng dụng trong hệ thống quản lí giám sát xe công trình” dựa theo quy chuẩn QCVN 31: 2014 của BGTVT về thiết bị giám sát hành trình của ô tô - Chức năng và cách thức hoạt động của thiết bị - Chọn phương án thiết kế tổng thể: Mỗi xe gắn 1 thiết bị quản lý, hoạt động độc lập với nhau, kết nối chung về 1 Server quản lí để truyền/ nhận dữ liệu | 1 tuần 18 - 25/08/2023 | Sơ lược Trao đổi với cô Hường
Tuần 2 | - Vạch ra thêm các yêu cầu (chi tiết các chức năng) - Vẽ sơ đồ cả hệ thống (từ thiết bị - Server - Web) - Liệt kê các thành phần linh kiện sử dụng - Yêu cầu của Web Server - Thêm cảm biến dầu (xác định thời gian, địa điểm nạp/xả dầu - > giảm thất thoát và quản lý tối ưu cài đặt và cảnh báo thất thường) - Web thay đổi mức nhiên liệu bằng đồ thị - OTA | - Bổ sung các yêu cầu chức năng của thiết bị (trong file Báo cáo 1) - Sơ đồ thiết kế, sơ đồ giao thức - Bổ sung yêu cầu của Web Server, chốt phương án sử dụng giao thức MQTT cho việc gửi dữ liệu từ thiết bị - Tìm hiểu các giao thức cần giao tiếp với các module ngoại vi: UART, SPI, 1-wire - Tìm hiểu module SIM7672 về phần thiết kế nguồn, anten, các thông số của module, điện áp hoạt động 3.8V - Tại sao trở kháng vào là 50ohm, 77ohm(tổn thất ít nhất), 30ohm(công suất truyền tối ưu nhất), là 2 đồ thì parabol. - Cần tham khảo mạch anh Trung về nguồn và mạch SIM - Chưa chốt OTA, update qua Server | 2 tuần 25/8/2023 - 6/9/2023 | cảm biến đo mức dầu giá thành cao, gồm có loại cảm biến tiếp xúc và không tiếp xúc. Dự định sử dụng cảm biến siêu âm HC-SR04
Tuần 3 | - Tìm hiểu datasheet các khối trong đồ án(9 khối): Khối nguồn, khối 4G LTE, GNSS, MCU, khối hiển thị,/thông báo, Flash/SD, khối cảm biến, khối debug/RS232, RFID, cho thêm cảm biến dầu (Option) - Phân tích lựa chọn, lý do chọn các linh kiện đó - Thiết kế Schematic | -Vẽ và hoàn thiện 9 khối trong schematic - Bỏ phần EEPROM, chỉ sử dụng Flash và SDCard - Thêm phần cảm biến mức nhiên liệu - Phân tích và thiết kế các khối bảo vệ và lọc điện áp, tránh nhiễu và phóng tĩnh điện trên đường truyền - Chọn các linh kiện phù hợp (trong bomlist file) | 4 tuần 8/9/2023 - 4/10/2023 | Đã báo cáo
Tuần 4 | - Thiết kế mạch PCB, đi dây, và các thông số Clearence cho khối nguồn cũng như dây tín hiệu - Tính toán thiết kế trở kháng đường dây Anten trên Web , (trích dẫn công thức) https://chemandy.com/calculators/coplanar-waveguide-with-ground-calculator.htm - Khoanh vùng các khối, liệt kê 1 số chuẩn đi dây với sắp xếp linh kiện | - Đã thiết kế mạch PCB dài 12.8 rộng 8.6 (cm) - Đặt mạch CXT - Tính toán trở kháng vào của khối 4G(1mm; 0.2mm) và GNSS(1.4mm; 0.2mm) - Hỏi các nguyên lý của mạch schematic về khối bảo vệ ESD, tụ, cuộn lọc,.. | 1 tuần 5/10/2023 - 12/10/2023 | Đã báo cáo
Tuần 5 | - Check mạch, đặt mạch - Đặt linh kiện - Code chức năng RFID, DHT11, DS18b20, cảm biến nhiên liệu, điện áp acqui, thời gian lái xe liên tục, cảm biến tiệm cận - Thời gian lái xe liên tục 4h - Tổng thời gian lái xe của cùng 1 người là 10h/ngày | - Đặt linh kiện ở CXT, llinhkienchatluong, banlinhkien trong file Excel - Viết quá trình giao tiếp với module DS18B20 và DHT11 - Đọc ADC từ cảm biến mức và accqui - RTC đếm thời gian để xuất ra giờ ngày tháng năm, hẹn thời gian để ghi flash (15ph) | 1 tuần 13/10/2023 - 22/10/2023 | Đã báo cáo
Tuần 6 | - Hàn mạch và debug mạch | - Mạch Ver1.2, lí do chip hỏng - Check nguồn oke, Test nguồn vào 12V, qua khối LDO 12V, Buck 3.8V, LDO 5V, LDO 3.3V cho MCU và GNSS - Check giao tiếp SIM oke (Lỗi gặp phải khối chuyển 1.8V-3.3V), đã viết hàm giao tiếp với SIM - Khối USB oke - Khối GNSS - Khối RS232 - Khối lưu trữ | 3 tuần 23/10/2023-11/11/2023 | đo xung ở netlight -đo dòng nguồn 3.8v -usbttl Đã báo cáo
Tuần 7 | - Code các chức năng còn lại: + Khối GNSS đo vị trí + Khối SIM gửi SMS, kết nối tới Server + Đo tốc độ, và cảnh báo tốc độ + Giao tiếp với Flash và SD + Truyền dữ liệu qua RS232 + OTA | - code xong GNSS về latitude, longtitude, speed, time, date - SIM kết nối tới Broker gửi MQTT, và nhận bản tin gửi về - mqtt broker sử dụng của Hive - code xong SDCard(chưa test) - | 3 tuần 12/11/2023-20/12/2023 | Đã báo cáo
Tuần 8 | - Thiết kế WebServer | - Thiết kế xong Dashboard - Thử nghiệm truyền lên dashboard oke, hơi bị delay nhưng không nhiều - Giao thức mqtt - Gồm có 4 device: Status, gps, rfid, sensor - Cần phải có access token để phân biệt giữa các device, và các device chung 1 topic là "v1/devices/me/telemetry" |  | Các bản tin nằm trong mục TestTB.txt
Tuần 9 | - Thiết kế vỏ hộp | - Vỏ hộp Thiết kế Solidworks - Xuất được file .STL - Chờ in |  | Đã báo cáo
Tuần 10 | - Thử nghiệm và đánh giá | - Demo được hoạt động của thiết bị đáp ứng đủ chức năng, nhưng còn thiếu các chức năng như: + Đo tốc độ qua cảm biến tiệm cận + Quãng đường di chuyển + Cấu hình thông số từ server + OTA + Số lần dừng/đỗ - Đã thử nghiệm việc đo độ chính xác của gps và thử nghiệm quãng đường di chuyển của thiết bị | 3 tuần 20/12/2023-10/1/2024 | 22/12/2023 đến gặp cô báo cáo, đề xuất dàn ý báo cáo, sửa đổi và thêm các ý từ bổ sung của cô
Tuần 11 | - Viết báo cáo | - OKE | 1 tuần 22/12/2023-10/1/2024

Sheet: Link sp
Linh kiện
Cầu chì tự phụ hồi | https://linhkien.cxt.vn/3729-cau-chi-tu-phuc-hoi-pptc-30v-tu-0-den-9a.html | x
tụ hóa | http://www.linhkienchatluong.vn/tu-hoa-co-phan-cuc/tu-hoa-35v-470uf-10x17mm-tan-so-cao_sp454_ct930.aspx | x
LM7812 | https://linhkien.cxt.vn/1833-lm7812ct-ic-reg-linear-12v-1a-to-220.html
Đèn báo 2 led | https://banlinhkien.com/den-bao-2-led-xanh-do-dbl22rg-5-chiec-p23489477.html | x
LM317 | https://linhkien.cxt.vn/9013-lm317dcyr-ic-reg-linear-pos-adj-15a-sot223-4.html
nút nhấn 3x4x2.5 | https://linhkien.cxt.vn/5070-nut-nhan-smd-2p.html | x
diode bav | https://linhkien.cxt.vn/2725-bav99215-a7w-diode-100v-125ma-sot-23-10c.html
simcard | https://linhkien.cxt.vn/1994-socket-micro-sim-6p-push.html | x
 | https://linhkien.cxt.vn/4502-esda6v1w5-tvs-diode-3vwm-sot323-5.html
zener anten | https://linhkien.cxt.vn/4503-lxes15aaa1-153-tvs-diode-4vwm-0402-10c.html
cuộn cảm | https://linhkien.cxt.vn/2829-cuon-cam-47nh-0805-10c.html | x
Sdcard | https://linhkien.cxt.vn/9682-tf-card-micro-sd-card-9p.html
flash | https://linhkien.cxt.vn/6664-w25q32fvssig-tr-ic-flash-32mbit-spiquad-8soic.html
usb | https://linhkien.cxt.vn/9725-10118193-0001lf-conn-rcpt-usb20-micro-b-smd-ra.html
xt12mhz | https://linhkien.cxt.vn/6633-thach-anh-12mhz-6035-2p.html
cảm biến tiệm cận từ NPN | http://linhkienchatluong.vn/cam-bien-tiem-can/cam-bien-tiem-can-lj12a3-4-zbx-npn-thuong-mo-chinh-hang-omch_sp1079_ct5094.aspx
tản nhiệt | https://linhkien.cxt.vn/7858-tan-nhiet-20x15x10mm-1-chan.html
rs232 | http://linhkienchatluong.vn/cong-usb-may-tinh-may-in/cong-db9-cai-chan-cong-han-mach-rs232comdr9_sp731_ct4222.aspx
jack nguồn | http://linhkienchatluong.vn/jack---o-cam-nguon-dc/jack-nguon-dc-cai-55x21mm-sat-tron-dc-022b_sp795_ct5466.aspx

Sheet: GSHT
Comment | Description | Designator | Footprint | LibRef | Quantity | Hãng | Trạng thái
Button 3x4x2.5 |  | B1, B2, B3, B4 | Button 3x4x2.5 | Button 3x4x2.5 | 4 | c | oke
PIN 3V MCU | Battery 3VDC | BT1 | CR1220 SMD | PIN 3V | 1 | c | oke
PIN 3V GNSS | Battery 3VDC | BT2 | CR1220 SMD | PIN 3V | 1 | c | oke
2.2uF | Capacitor | C1, C9, C10 | CAP_0805 | CapSMD | 3 | c | oke
0.1uF | Capacitor | C2, C6, C12, C13, C20, C22, C24, C26, C28, C29, C41, C42, C43, C45, C52, C55, C58, C59, C60, C61, C66 | CAP_0805 | CapSMD | 21 | c | oke
470uF/35V | Cap 1000uF/16V - 220uF/50V | C3, C4 | C10mm | CP4 | 2 | l | oke
5D330K 40V | 5D330K 33V | C5 | CN2 | CN | 1 | c | oke
47uF | Capacitor | C7, C8 | CAP_0805 | CapSMD | 2 | c | oke
39pF | Capacitor | C11 | CAP_0805 | CapSMD | 1 | c | oke
6800pF | Capacitor | C14 | CAP_0805 | CapSMD | 1 | c | oke
1uF | Capacitor | C15, C16, C17, C18, C19, C21, C23, C25, C27, C30, C33, C36, C38, C51, C62, C63, C64, C65 | CAP_0805 | CapSMD | 18 | c | oke
STLINK | Header IDC, 4 x 1 Pin Vertical 2.54mm Pitch (Non-Boxed, Male) | C31 | CON_4P | Header4 | 1 | c | oke
22pF | Capacitor | C32, C34, C48, C49, C50, C67, C68 | CAP_0805 | CapSMD | 7 | c | oke
10pF | Capacitor | C35, C37 | CAP_0805 | CapSMD | 2 | c | oke
OLED | Header IDC, 4 x 1 Pin Vertical 2.54mm Pitch (Non-Boxed, Male) | C39 | CON_4P | Header4 | 1 | c | oke
10uF | Capacitor | C40, C44, C53 | CAP_0805 | CapSMD | 3 | c | oke
100uF | Capacitor | C46 | CAP_0805 | CapSMD | 1 | c | oke | thay thế bằng tụ 10uF
100nF | Capacitor | C47 | CAP_0805 | CapSMD | 1 | 0.1u | oke
4.7uF | Capacitor | C54 | CAP_0805 | CapSMD | 1 | c | oke
NM | Capacitor | C56, C57 | CAP_0805 | CapSMD | 2 |  | không cần
NPN | Header IDC, 4 x 1 Pin Vertical 2.54mm Pitch (Non-Boxed, Male) | C69 | CON_4P | Header4 | 1 | c | oke
100pF | Capacitor | C70, C71 | CAP_0805 | CapSMD | 2 | c | oke
COM 9 FMALE | COM 9 | COM1 | DSB 9-F | DSB9F | 1 | l | oke
M7 | Diode 1A | D1 | SMA11 | D1A | 1 | c |  | Diode schottky
B560C-13-F | DIODE SCHOTTKY 60V 5A SMC | D2 | DO-214AB SMC | D5A | 1 | b
LED3mm | LED 3 holder RGB 3mm | D3 | LED 3 holder 3mm | LED3Holder_3 | 1 | b | oke
BAV99 | Diode Array 1 Pair Series Connection Standard 100V 215mA (DC) Surface Mount TO-236-3, SC-59, SOT-23-3 | D4, D5, D8, D9, D10 | DIO_BAV99 | BAV99 | 5 | c | oke
LXES15AAA1-153 | TVS DIODE 4VWM 1005 | D6 | R-0402 | TVS | 1 | c | oke
ESDA6V1W5 | - Clamp - Ipp Tvs Diode Surface Mount SOT-323-5 | D7 | SOT65P210X110-5N | ESDA6V1W5 | 1 | c | oke
RKEF300HF-ND | PTC RESET FUSE 60V 3A RADIAL | F1 | FUSE2 | Fuse | 1 | c | 40V 4A
120R | Ferrite beads | FB1, FB2, FB3, FB4, FB5 | RES-SMD-0805 | Ferrite beads | 5 | c | oke
RT9013 | RT9013-33GB IC REG LINEAR 3.3V 500mA SOT23-5 | IC1, IC2 | SOT23-5 | RT9013 | 2 | c | oke
SIM A7672S | SIM A7672S-CAT-M1 | IC3 | SIM A7672S | SIM A7672S | 1 |  | đặt từ epi
TXB0102DCUR | IC TRNSLTR BIDIRECTIONAL US8 | IC4 | US8 | TXB0102DCUR | 1 | c | oke
MAX232 | Dual EIA-232 Driver/Receiver | IC5 | MAX232DR | MAX232 | 1 | c | oke
DS18B20 | High Precision 1-Wire® Digital Thermometer | IC6 | DS18S20 | DS18S20 | 1 | c | oke
GPS |  | J1 | Antenna-MCX5.08-H5 | ANTEN | 1 | c | oke
GPS_ANTENNA |  | J2 | Antenna-MCX5.08-H5 | ANTEN | 1 | c | oke
RFID | Connector 8 | JP1 | CON_8P | Con8 | 1 | c | oke | có cảm biến
JP2 | WR-PHD 2.54 mm Angled Socket Header | JP2 | JP2-C1T | JP2 | 1 |  | Nguồn
LEVEL | Connector 3 | JP3 | CON3 | Con3 | 1 | c | oke | có cảm biến
DHT11 | Connector 3 | JP4 | CON3 | Con3 | 1 | c | oke | có cảm biến
L | Inductor | L1 | L2 UF9.8 | L2x220 | 1 | b |  | x
8.2uH | FIXED IND 6.2UH 5.7A 22.4 MOHM | L2 | L01 SMD 12*12*6 | L1 | 1 | l | oke | 6.8uH
47nH | Inductor | L3 | RES-SMD-0805 | L1 | 1 | c | oke
PWR_5V | LED Single colour Green and Red | LED1, LED9 | LED-0805-Blue | LED | 2 | c | oke
PWR_12V | LED Single colour Green and Red | LED2 | LED-0805-Blue | LED | 1 | c | oke
LED | LED Single colour Green and Red | LED3, LED4 | LED-0805-Red | LED | 2 | c | oke
LED | LED Single colour Green and Red | LED5, LED6, LED7, LED8 | LED-0805-Blue | LED | 4 | c | oke
Speaker | Loudspeaker | LS1 | SPEAKER | Speaker | 1 | c | oke
C1815 | NPN 600mW, ECB | Q1, Q2, Q3, Q4, Q5, Q6, Q7, Q8, Q9 | SOT23B | C1815 | 9 | c | oke
330R | Resistor SMD | R1, R6, R16, R17, R18, R36, R43, R71 | R0805 | RM | 8 | c | oke
17.4K | Resistor SMD | R2 | R0805 | RM | 1 | c | oke
10K | Resistor SMD | R3, R4, R8, R10, R12, R19, R23, R25, R26, R27, R30, R48, R49, R50, R51, R52, R53, R54, R65 | R0805 | RM | 19 | c | oke
220K | Resistor SMD | R5 | R0805 | RM | 1 | c | oke | l
4.7K | Resistor SMD | R7, R11, R28, R34, R37, R38, R41, R45, R67, R69, R73 | R0805 | RM | 11 | c | oke | l
47K | Resistor SMD | R9, R13, R29, R35, R39, R40, R42, R46 | R0805 | RM | 8 | c | oke
1.2K | Resistor SMD | R14 | R0805 | RM | 1 | c | oke
3.48K | Resistor SMD | R15 | R0805 | RM | 1 | c | oke
10R | Resistor SMD | R20, R21, R22, R47 | R0805 | RM | 4 | c | oke
1K | Resistor SMD | R24, R55, R56, R57, R58, R59, R60, R61, R62, R66, R72 | R0805 | RM | 11 | c | oke
22R | Resistor SMD | R31, R32, R33, R63, R64 | R0805 | RM | 5 | c | oke | l
0R | Resistor SMD | R44 | R0805 | RM | 1 | c | oke
47.5K | Resistor SMD | R68 | R0805 | RM | 1 | c | oke | thay bằng 47K
18K | Resistor SMD | R70 | R0805 | RM | 1 | c | oke
LM317DCYR | 1.5-A, 40-V, adjustable linear voltage regulator 4-SOT-223 0 to 125 | U | SOT230P700X180-4N | LM317DCYR | 1 | c | oke
LM7812SX/NOPB | LM7812SX/NOPB | U1 | QTO-220 | LM78xx_1 | 1 | c | oke
TPS54360DDA | REG BUCK SPLIT RAIL 8SOPWRPAD | U2 | DDA8_3P1X2P4-M | TPS54360DDA | 1 | c | oke
STM32F103RCT6 | MCU 32BIT 256KB FLASH 64LQFP | U3 | LQFP-64 | STM32F103RCT6 | 1 |  | đã có
SIM-KF016 | SIM Card Holder KF-016 | U4 | Sim Socket | Sim holder | 1 | c | oke
GPS L70 |  | U5 | GPS L70 | GPS L70 | 1 |  | đã có
SD_CARD | SD/MMC holder | U6 | MICROSD2 | MicroSD | 1 | c | oke
W25Q32JVSSIQ | FLASH 32MBIT 133MHZ 8SOP | U7 | SO-8 208 | W25Q32JV | 1 | c | oke
CH340G | High and Low Side Driver | U8 | SO16 | CH340G | 1 | c | oke
PC817 | Single Opto | U9 | SOT254P975X400-4N | PC817 | 1 | c | oke
USB Micro 5p DIP | USB Type B | USB1 | USB Micro 5p DIP | USB Micro 5p DIP | 1 | c | oke
32,768 Khz | Crystal 32,768kHz for timer real | X1 | XT32kn | XT32k | 1 | c | oke
8MHz | CRYSTAL 16MHZ 18PF SMD | Y1 | ABM7_v1_1_BIG | ABM7-16.000MHZ-D2Y-T | 1 | c | oke
12Mhz | Crystal For all Crystal 2pin. | Y2 | Thach Anh 2 chan SMD5032 | Thach Anh 2 chan SMD 5032 | 1 | c | oke

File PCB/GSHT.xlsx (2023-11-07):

Comment | Description | Designator | Footprint | LibRef | Quantity
Button 3x4x2.5 |  | B1, B2, B3, B4 | Button 3x4x2.5 | Button 3x4x2.5 | 4
PIN 3V MCU | Battery 3VDC | BT1 | CR1220 SMD | PIN 3V | 1
PIN 3V GNSS | Battery 3VDC | BT2 | CR1220 SMD | PIN 3V | 1
2.2uF | Capacitor | C1, C9, C10 | CAP_0805 | CapSMD | 3
0.1uF | Capacitor | C2, C6, C12, C13, C20, C22, C24, C26, C28, C29, C41, C42, C43, C45, C52, C55, C58, C59, C60, C61, C66 | CAP_0805 | CapSMD | 21
470uF/35V | Cap 1000uF/16V - 220uF/50V | C3, C4 | C10mm | CP4 | 2
5D330K 40V | 5D330K 33V | C5 | CN2 | CN | 1
47uF | Capacitor | C7, C8 | CAP_0805 | CapSMD | 2
39pF | Capacitor | C11 | CAP_0805 | CapSMD | 1
6800pF | Capacitor | C14 | CAP_0805 | CapSMD | 1
1uF | Capacitor | C15, C16, C17, C18, C19, C21, C23, C25, C27, C30, C33, C36, C38, C51, C62, C63, C64, C65 | CAP_0805 | CapSMD | 18
STLINK | Header IDC, 4 x 1 Pin Vertical 2.54mm Pitch (Non-Boxed, Male) | C31 | CON_4P | Header4 | 1
22pF | Capacitor | C32, C34, C48, C49, C50, C67, C68 | CAP_0805 | CapSMD | 7
10pF | Capacitor | C35, C37 | CAP_0805 | CapSMD | 2
OLED | Header IDC, 4 x 1 Pin Vertical 2.54mm Pitch (Non-Boxed, Male) | C39 | CON_4P | Header4 | 1
10uF | Capacitor | C40, C44, C53 | CAP_0805 | CapSMD | 3
100uF | Capacitor | C46 | CAP_0805 | CapSMD | 1
100nF | Capacitor | C47 | CAP_0805 | CapSMD | 1
4.7uF | Capacitor | C54 | CAP_0805 | CapSMD | 1
NM | Capacitor | C56, C57 | CAP_0805 | CapSMD | 2
NPN | Header IDC, 4 x 1 Pin Vertical 2.54mm Pitch (Non-Boxed, Male) | C69 | CON_4P | Header4 | 1
100pF | Capacitor | C70, C71 | CAP_0805 | CapSMD | 2
COM 9 FMALE | COM 9 | COM1 | DSB 9-F | DSB9F | 1
M7 | Diode 1A | D1 | SMA11 | D1A | 1
B560C-13-F | DIODE SCHOTTKY 60V 5A SMC | D2 | DO-214AB SMC | D5A | 1
LED3mm | LED 3 holder RGB 3mm | D3 | LED 3 holder 3mm | LED3Holder_3 | 1
BAV99 | Diode Array 1 Pair Series Connection Standard 100V 215mA (DC) Surface Mount TO-236-3, SC-59, SOT-23-3 | D4, D5, D8, D9, D10 | DIO_BAV99 | BAV99 | 5
LXES15AAA1-153 | TVS DIODE 4VWM 1005 | D6 | R-0402 | TVS | 1
ESDA6V1W5 | - Clamp - Ipp Tvs Diode Surface Mount SOT-323-5 | D7 | SOT65P210X110-5N | ESDA6V1W5 | 1
RKEF300HF-ND | PTC RESET FUSE 60V 3A RADIAL | F1 | FUSE2 | Fuse | 1
120R | Ferrite beads | FB1, FB2, FB3, FB4, FB5 | RES-SMD-0805 | Ferrite beads | 5
RT9013 | RT9013-33GB IC REG LINEAR 3.3V 500mA SOT23-5 | IC1, IC2 | SOT23-5 | RT9013 | 2
SIM A7672S | SIM A7672S-CAT-M1 | IC3 | SIM A7672S | SIM A7672S | 1
TXB0102DCUR | IC TRNSLTR BIDIRECTIONAL US8 | IC4 | US8 | TXB0102DCUR | 1
MAX232 | Dual EIA-232 Driver/Receiver | IC5 | MAX232DR | MAX232 | 1
DS18B20 | High Precision 1-Wire® Digital Thermometer | IC6 | DS18S20 | DS18S20 | 1
GPS |  | J1 | Antenna-MCX5.08-H5 | ANTEN | 1
GPS_ANTENNA |  | J2 | Antenna-MCX5.08-H5 | ANTEN | 1
RFID | Connector 8 | JP1 | CON_8P | Con8 | 1
JP2 | WR-PHD 2.54 mm Angled Socket Header | JP2 | JP2-C1T | JP2 | 1
LEVEL | Connector 3 | JP3 | CON3 | Con3 | 1
DHT11 | Connector 3 | JP4 | CON3 | Con3 | 1
L | Inductor | L1 | L2 UF9.8 | L2x220 | 1
8.2uH | FIXED IND 6.2UH 5.7A 22.4 MOHM | L2 | L01 SMD 12*12*6 | L1 | 1
47nH | Inductor | L3 | RES-SMD-0805 | L1 | 1
PWR_5V | LED Single colour Green and Red | LED1, LED9 | LED-0805-Blue | LED | 2
PWR_12V | LED Single colour Green and Red | LED2 | LED-0805-Blue | LED | 1
LED | LED Single colour Green and Red | LED3, LED4 | LED-0805-Red | LED | 2
LED | LED Single colour Green and Red | LED5, LED6, LED7, LED8 | LED-0805-Blue | LED | 4
Speaker | Loudspeaker | LS1 | SPEAKER | Speaker | 1
C1815 | NPN 600mW, ECB | Q1, Q2, Q3, Q4, Q5, Q6, Q7, Q8, Q9 | SOT23B | C1815 | 9
330R | Resistor SMD | R1, R6, R16, R17, R18, R36, R43, R71 | R0805 | RM | 8
17.4K | Resistor SMD | R2 | R0805 | RM | 1
10K | Resistor SMD | R3, R4, R8, R10, R12, R19, R23, R25, R26, R27, R30, R48, R49, R50, R51, R52, R53, R54, R65 | R0805 | RM | 19
220K | Resistor SMD | R5 | R0805 | RM | 1
4.7K | Resistor SMD | R7, R11, R28, R34, R37, R38, R41, R45, R67, R69, R73 | R0805 | RM | 11
47K | Resistor SMD | R9, R13, R29, R35, R39, R40, R42, R46 | R0805 | RM | 8
1.2K | Resistor SMD | R14 | R0805 | RM | 1
3.48K | Resistor SMD | R15 | R0805 | RM | 1
10R | Resistor SMD | R20, R21, R22, R47 | R0805 | RM | 4
1K | Resistor SMD | R24, R55, R56, R57, R58, R59, R60, R61, R62, R66, R72 | R0805 | RM | 11
22R | Resistor SMD | R31, R32, R33, R63, R64 | R0805 | RM | 5
0R | Resistor SMD | R44 | R0805 | RM | 1
47.5K | Resistor SMD | R68 | R0805 | RM | 1
18K | Resistor SMD | R70 | R0805 | RM | 1
LM317DCYR | 1.5-A, 40-V, adjustable linear voltage regulator 4-SOT-223 0 to 125 | U | SOT230P700X180-4N | LM317DCYR | 1
LM7812SX/NOPB | LM7812SX/NOPB | U1 | QTO-220 | LM78xx_1 | 1
TPS54360DDA | REG BUCK SPLIT RAIL 8SOPWRPAD | U2 | DDA8_3P1X2P4-M | TPS54360DDA | 1
STM32F103RCT6 | MCU 32BIT 256KB FLASH 64LQFP | U3 | LQFP-64 | STM32F103RCT6 | 1
SIM-KF016 | SIM Card Holder KF-016 | U4 | Sim Socket | Sim holder | 1
GPS L70 |  | U5 | GPS L70 | GPS L70 | 1
SD_CARD | SD/MMC holder | U6 | MICROSD2 | MicroSD | 1
W25Q32JVSSIQ | FLASH 32MBIT 133MHZ 8SOP | U7 | SO-8 208 | W25Q32JV | 1
CH340G | High and Low Side Driver | U8 | SO16 | CH340G | 1
PC817 | Single Opto | U9 | SOT254P975X400-4N | PC817 | 1
USB Micro 5p DIP | USB Type B | USB1 | USB Micro 5p DIP | USB Micro 5p DIP | 1
32,768 Khz | Crystal 32,768kHz for timer real | X1 | XT32kn | XT32k | 1
8MHz | CRYSTAL 16MHZ 18PF SMD | Y1 | ABM7_v1_1_BIG | ABM7-16.000MHZ-D2Y-T | 1
12Mhz | Crystal For all Crystal 2pin. | Y2 | Thach Anh 2 chan SMD5032 | Thach Anh 2 chan SMD 5032 | 1

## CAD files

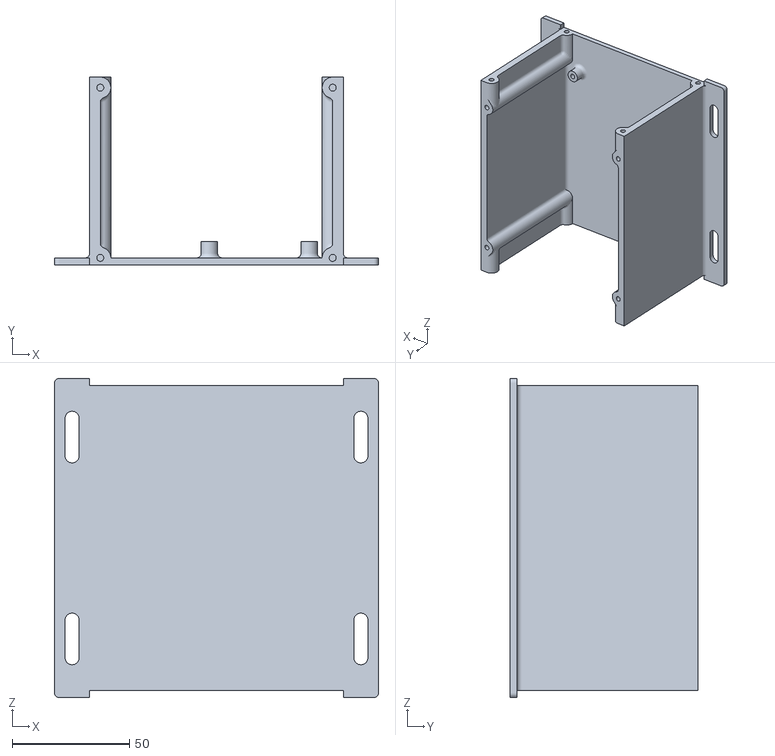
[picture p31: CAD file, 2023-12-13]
PICTURE/hộp/Vỏ hộp/STL/4.0_matday.STL
138.0 x 80.0 x 136.0

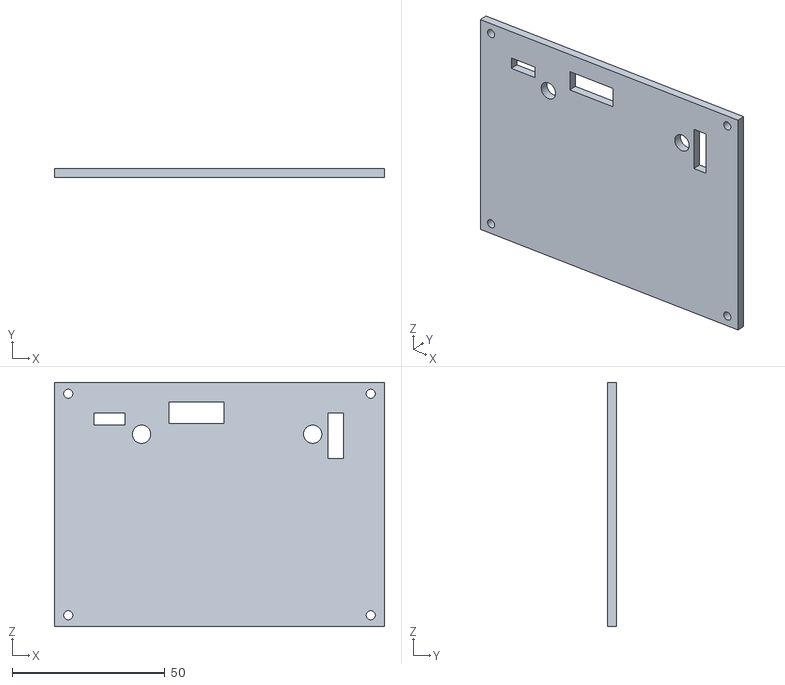
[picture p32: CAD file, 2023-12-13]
PICTURE/hộp/Vỏ hộp/STL/1.0_mattruoc.STL
108.0 x 3.00 x 80.0

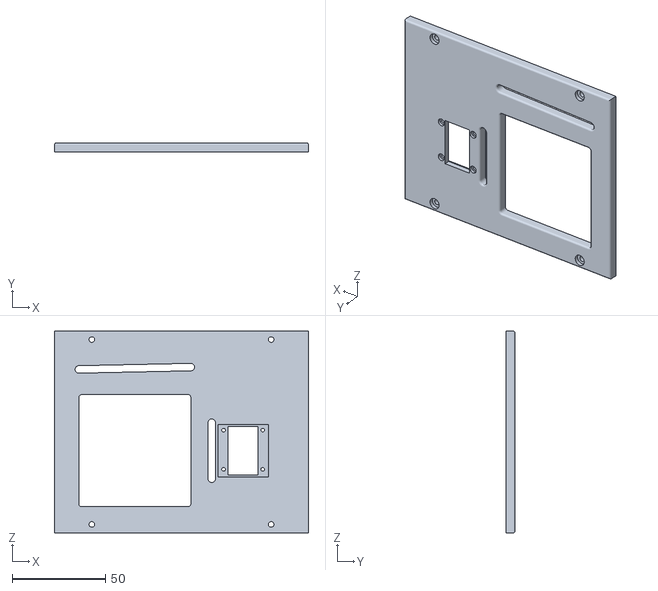
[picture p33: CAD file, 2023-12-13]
PICTURE/hộp/Vỏ hộp/STL/3.0_laptren.STL
136.0 x 5.00 x 108.0

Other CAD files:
PICTURE/hộp/Vỏ hộp/STL/2.0_matsau.STL

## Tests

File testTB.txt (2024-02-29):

https://demo.thingsboard.io/api/noauth/activate?activateToken=aiSYJKd_YbDCoSqaR91g0uFWPA_nQEc_ZemRQJKN	123345678
https://demo.thingsboard.io/api/noauth/activate?activateToken=cdT1aRv27DvPpaHvKE93aQH6zHt3SKKGboGcCjBR	Hoanghust
device-status:
{"online":1,"offline": 0,"sleep":0}
device-gps:
{"license":30N-1234,"name":Nguyen_Huy_Hoang,"phone":VN123456789,"signal":OK,"latitude":21.005159,"longitude":105.841827} 
device-rfid:
{"deviceID":GSHT_ID02,"license":30N-1234,"name": Nguyen_Huy_Hoang,"phone":VN123456789,"signal":OK,"ds18b20":35}
device-sensor:
{"ds18b20":35,"dhttemp":25,"dhthum":80}
******************************************************************************************
DATN_Device
{"online":2,"offline": 1,"sleep":0, "deviceID":GSHT_ID01, "license":30N-1234, "name":Nguyen_Huy_Hoang, "phone":VN123456789, "signal":OK, "latitude":21.005159, "longitude":105.841827,"ds18b20":25,"dhttemp":35,"dhthum":80, "fuel": 80,"timetotal":0h1, "speed":1}
******************************************************************************************
dht
AT+CMQTTCONNECT=0,"tcp://demo.thingsboard.io:1883",90,1,"HDDsbgj5mlE0lvt4UhX9","64731920-9460-11ee-ad71-4d1e7bacfffa"
ds
AT+CMQTTCONNECT=0,"tcp://demo.thingsboard.io:1883",90,1,"57OrAgUzdWLWjWE760Ir","5437ac10-9460-11ee-ad71-4d1e7bacfffa"
https://demo.thingsboard.io/dashboard/c39a29b0-9457-11ee-ad71-4d1e7bacfffa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

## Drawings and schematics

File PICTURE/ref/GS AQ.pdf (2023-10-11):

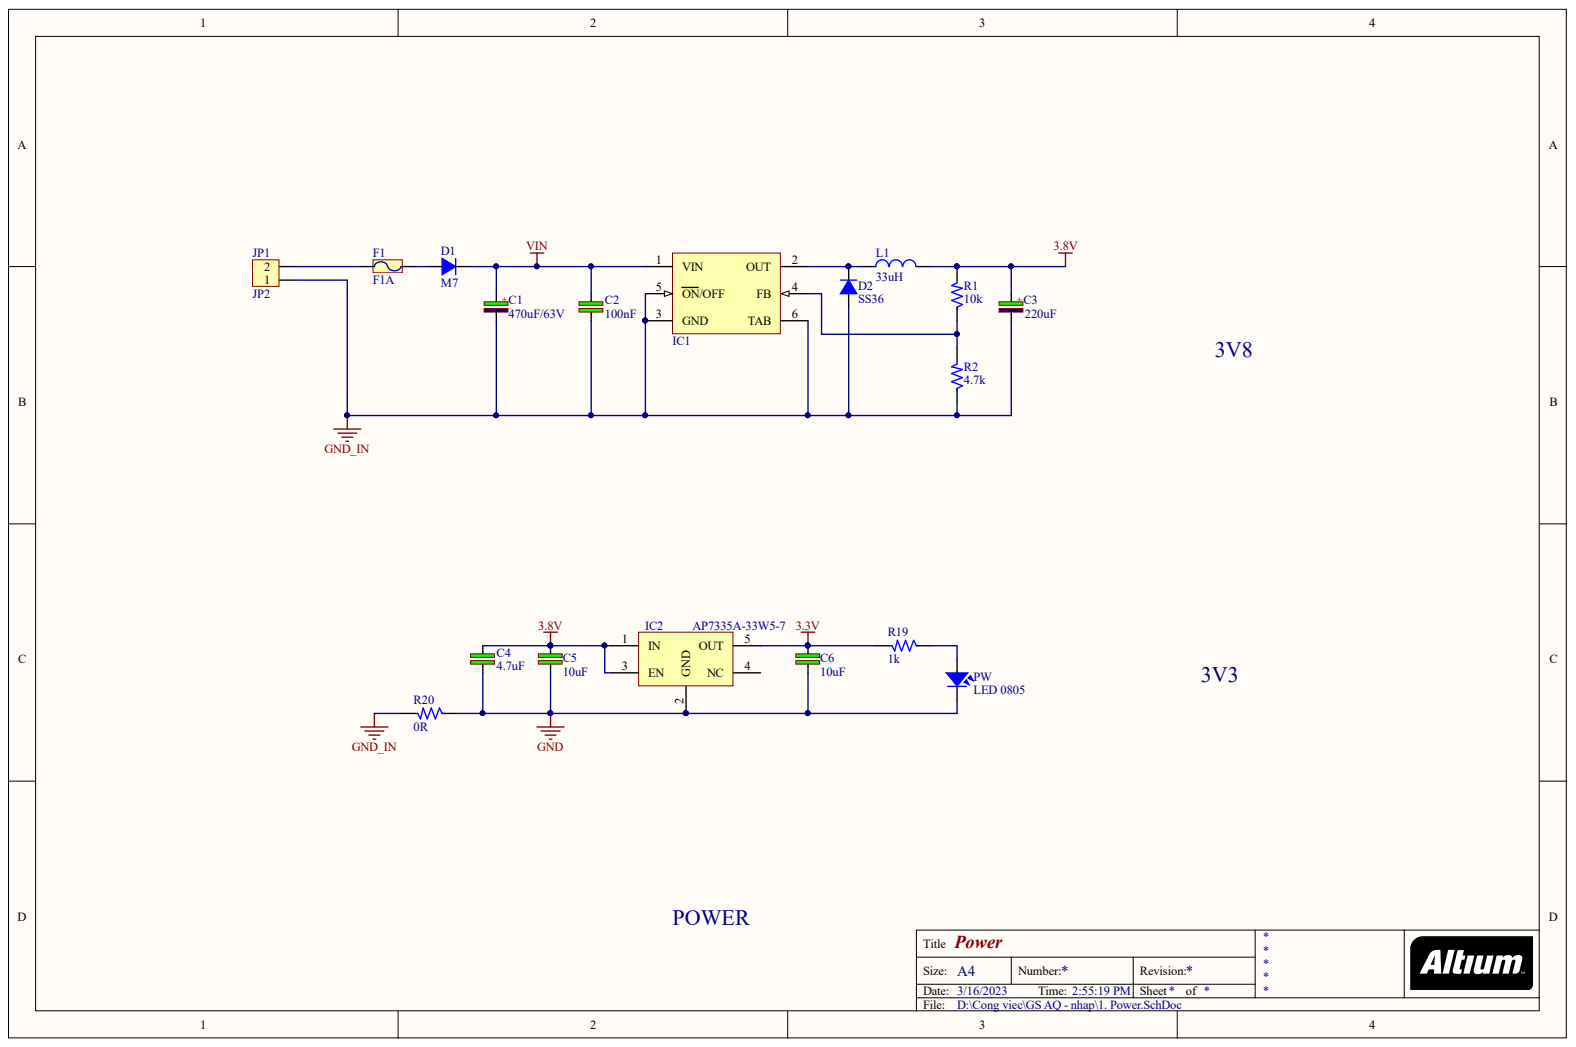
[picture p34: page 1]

Power Title | * * * * *

A4 Size: | * Number: | * Revision:

Date: 3/16/2023 Time: 2:55:19 PM | | Sheet * of *
File: D:\Cong viec\GS AQ - nhap\1. Power.SchDoc

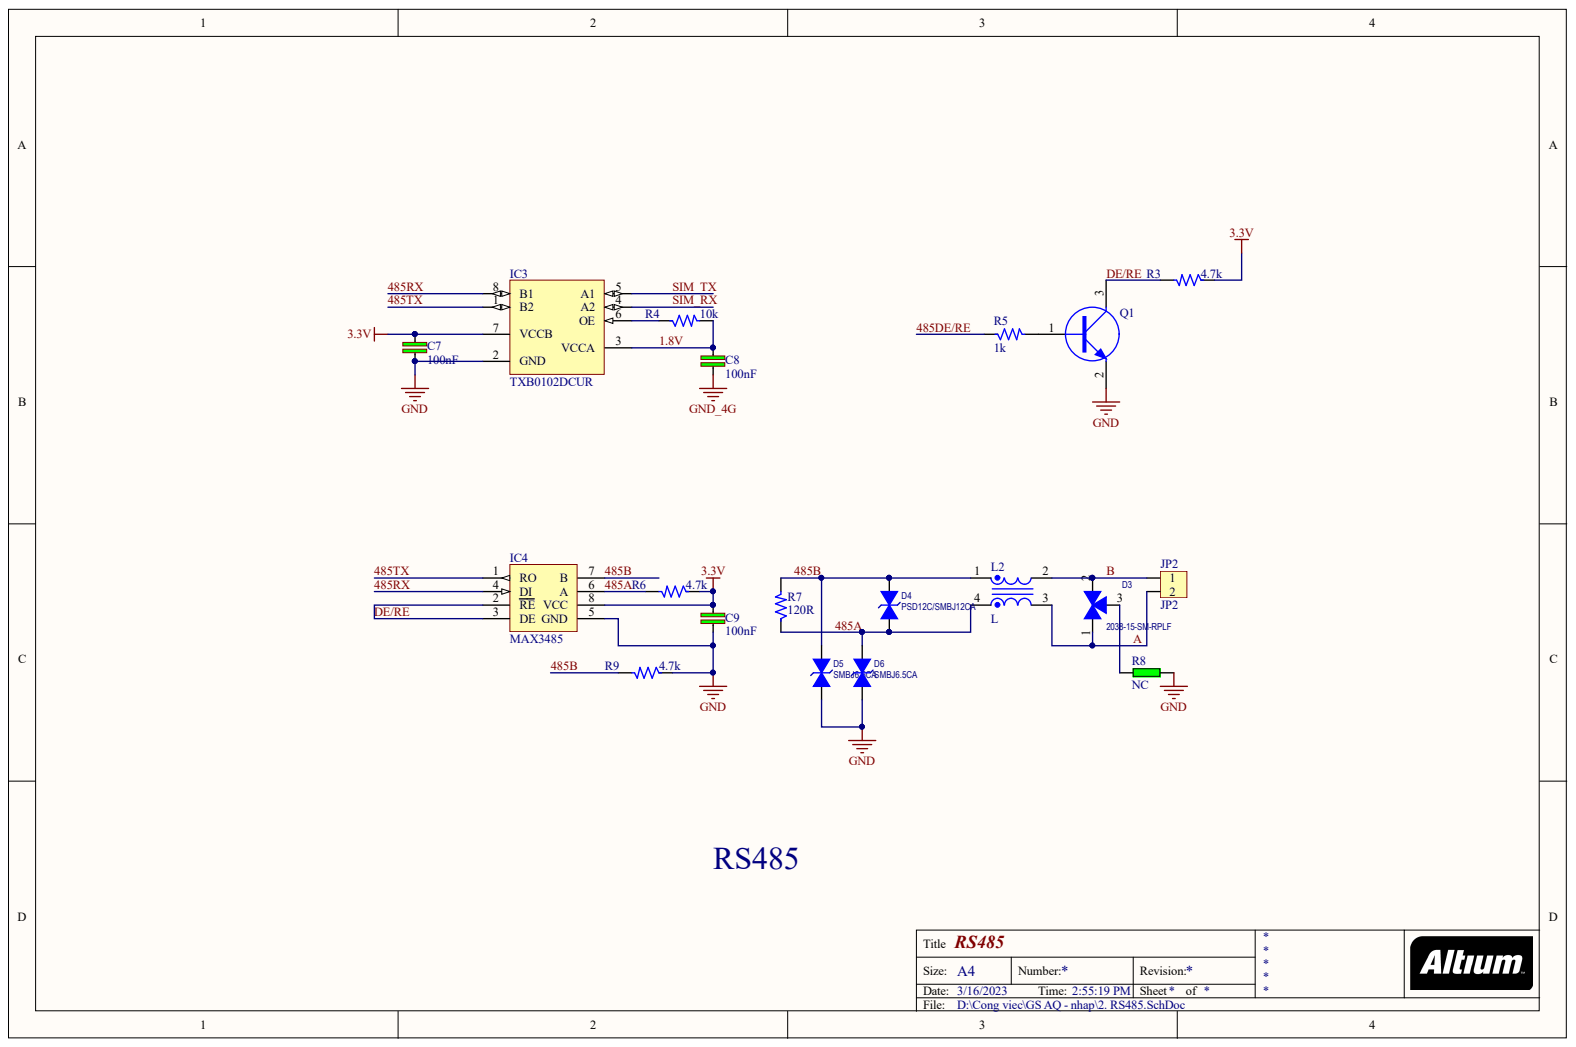
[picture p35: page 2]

RS485 Title | * * * * *

A4 Size: | * Number: | * Revision:

Date: 3/16/2023 Time: 2:55:19 PM | | Sheet * of *
File: D:\Cong viec\GS AQ - nhap\2. RS485.SchDoc

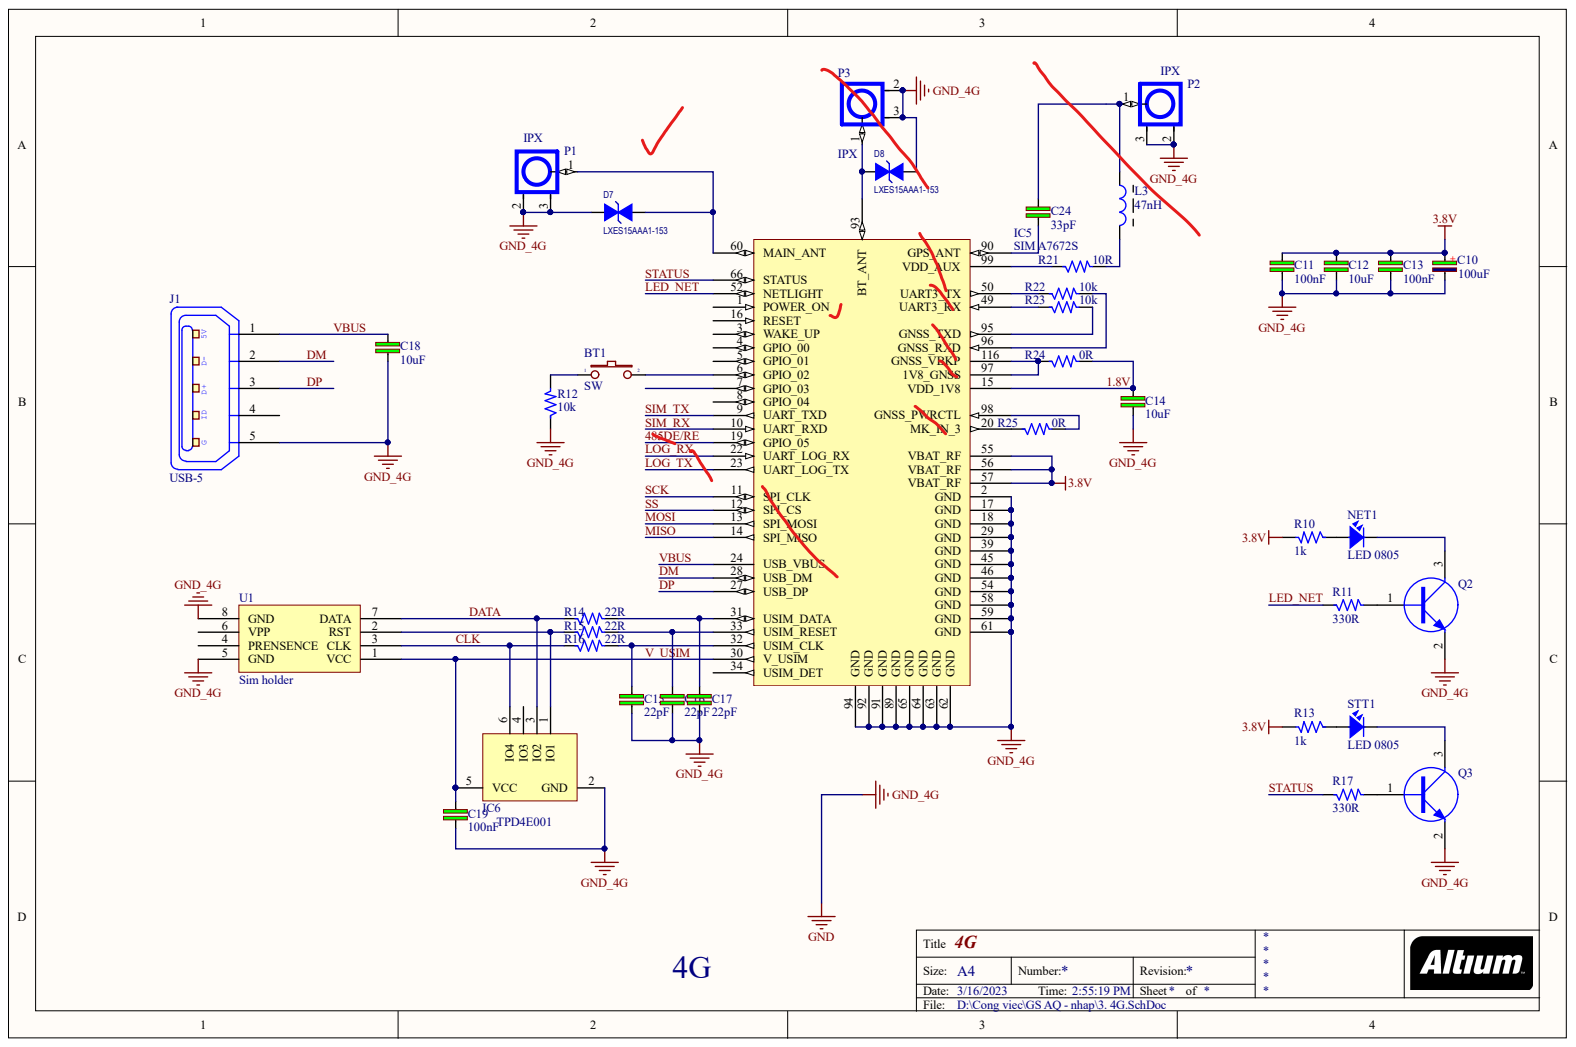
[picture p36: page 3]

GND 89 GND 91 GND 92 GND 94

A 4 | * Numbe r : | * R evision:

D ate : 3/16/2023 Time : 2:55:19 P M | | She e t * of *
File : D:\Cong vie c\G S A Q - nhap\3. 4G . S chDoc

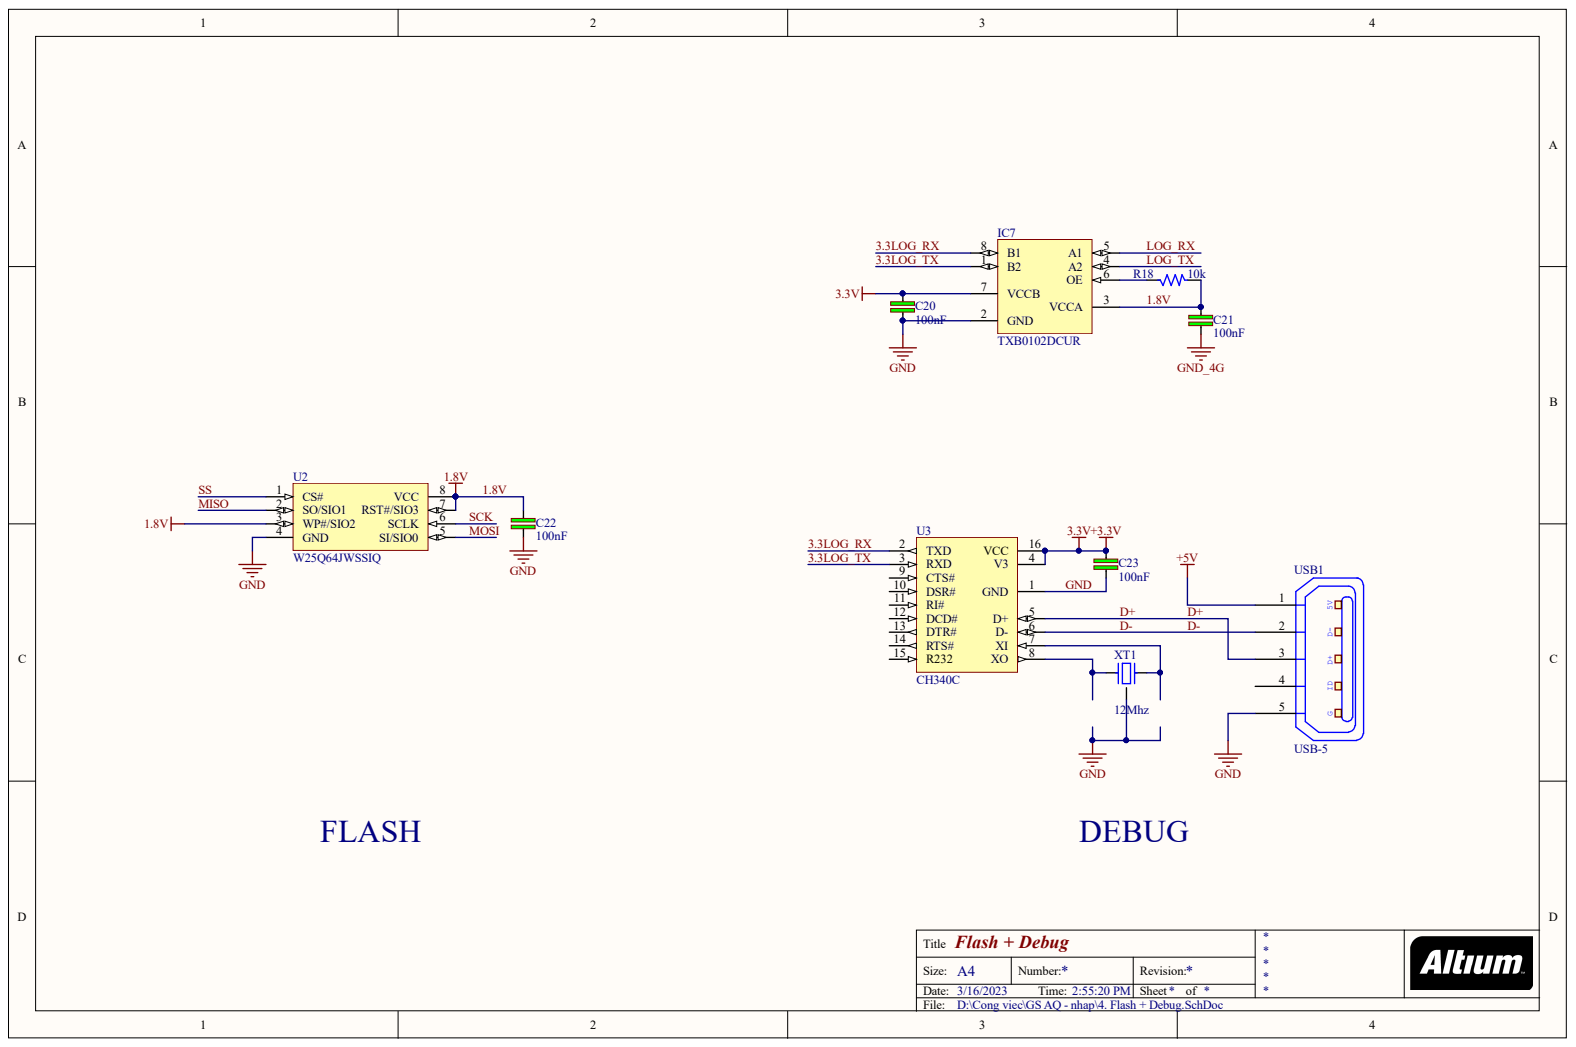
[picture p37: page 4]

6 | D -D -
8 | XT1

Flash + | **** *

A 4 | Numbe r : | * R evision:

D ate : 3/16/2023 Time : 2:55:20 P M | | She e t * of *
File : D:\Cong vie c\G S A Q - nhap\4. Flash + D ebug. S chDoc

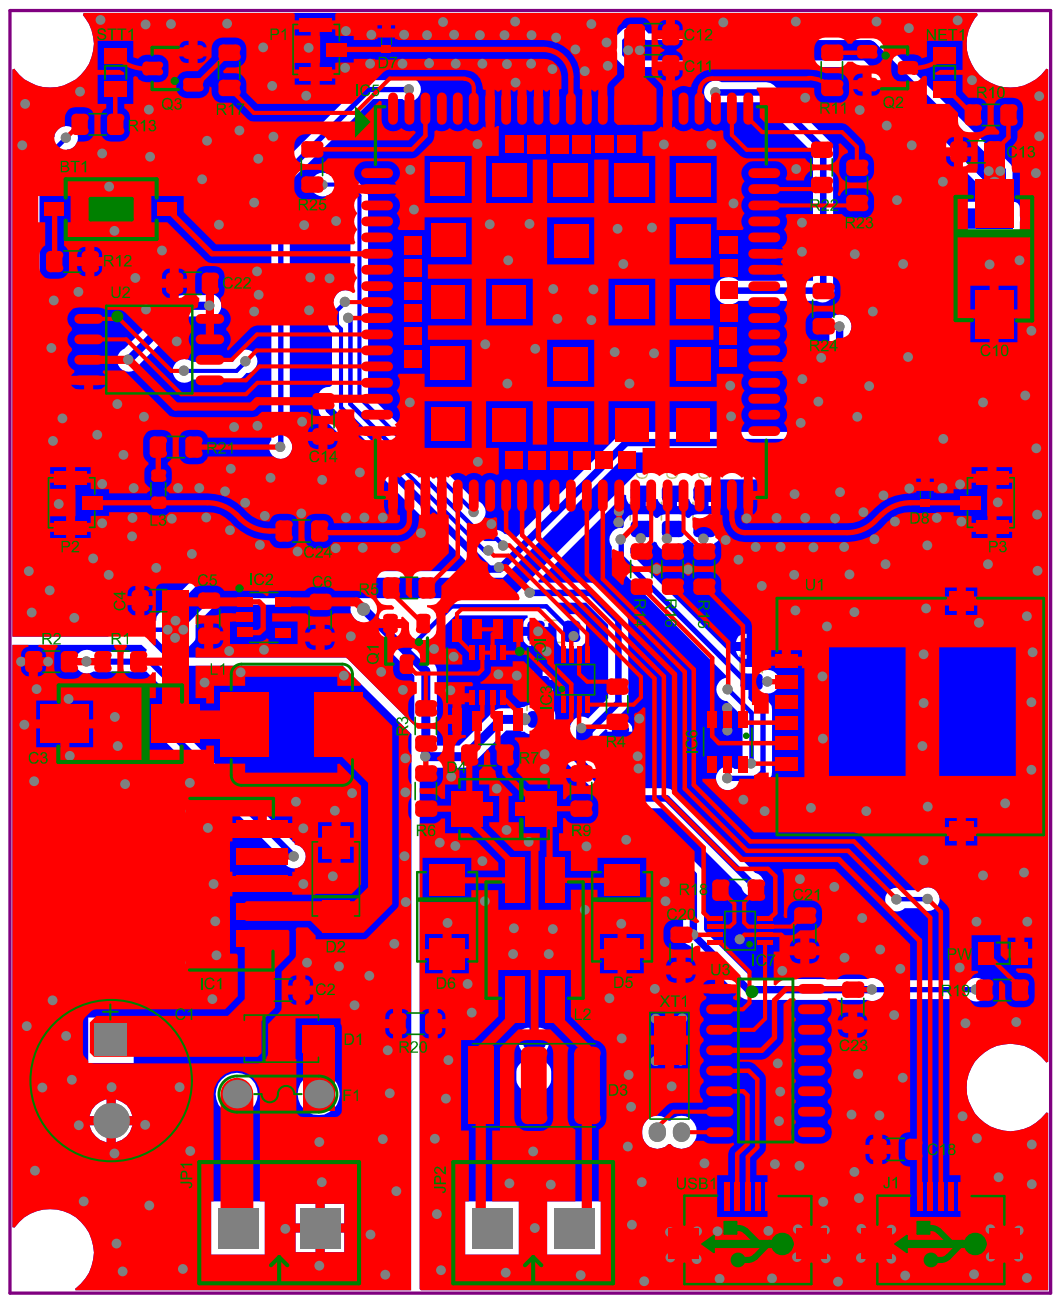
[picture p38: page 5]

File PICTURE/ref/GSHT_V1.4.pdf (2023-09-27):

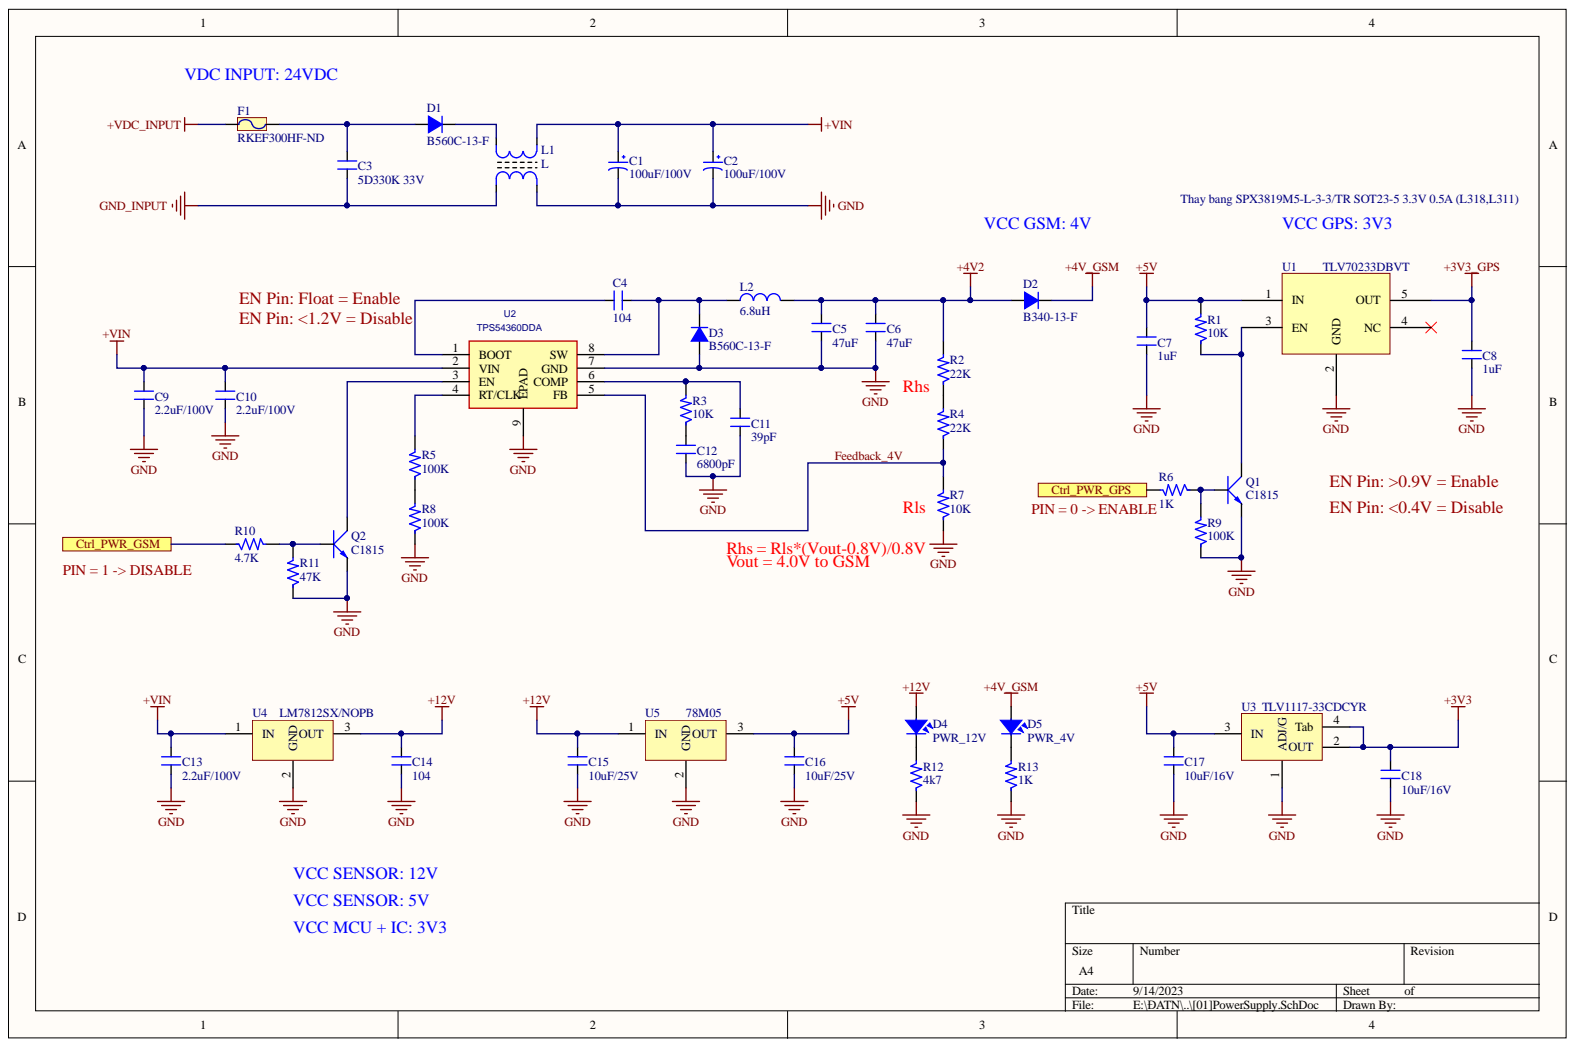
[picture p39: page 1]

EN Pin: Float = Enable
EN Pin: <1.2V = Disable

Rhs = Rls*(Vout-0.8V)/0.8V Vout = 4.0V to GSM

ADJ/G 1 OUT 2 IN 3 Tab 4

Size A4 | Number | Revision

Date: 9/14/2023 | Sheet of
File: E:\ĐATN\..\[01]PowerSupply.SchDoc | Drawn By:

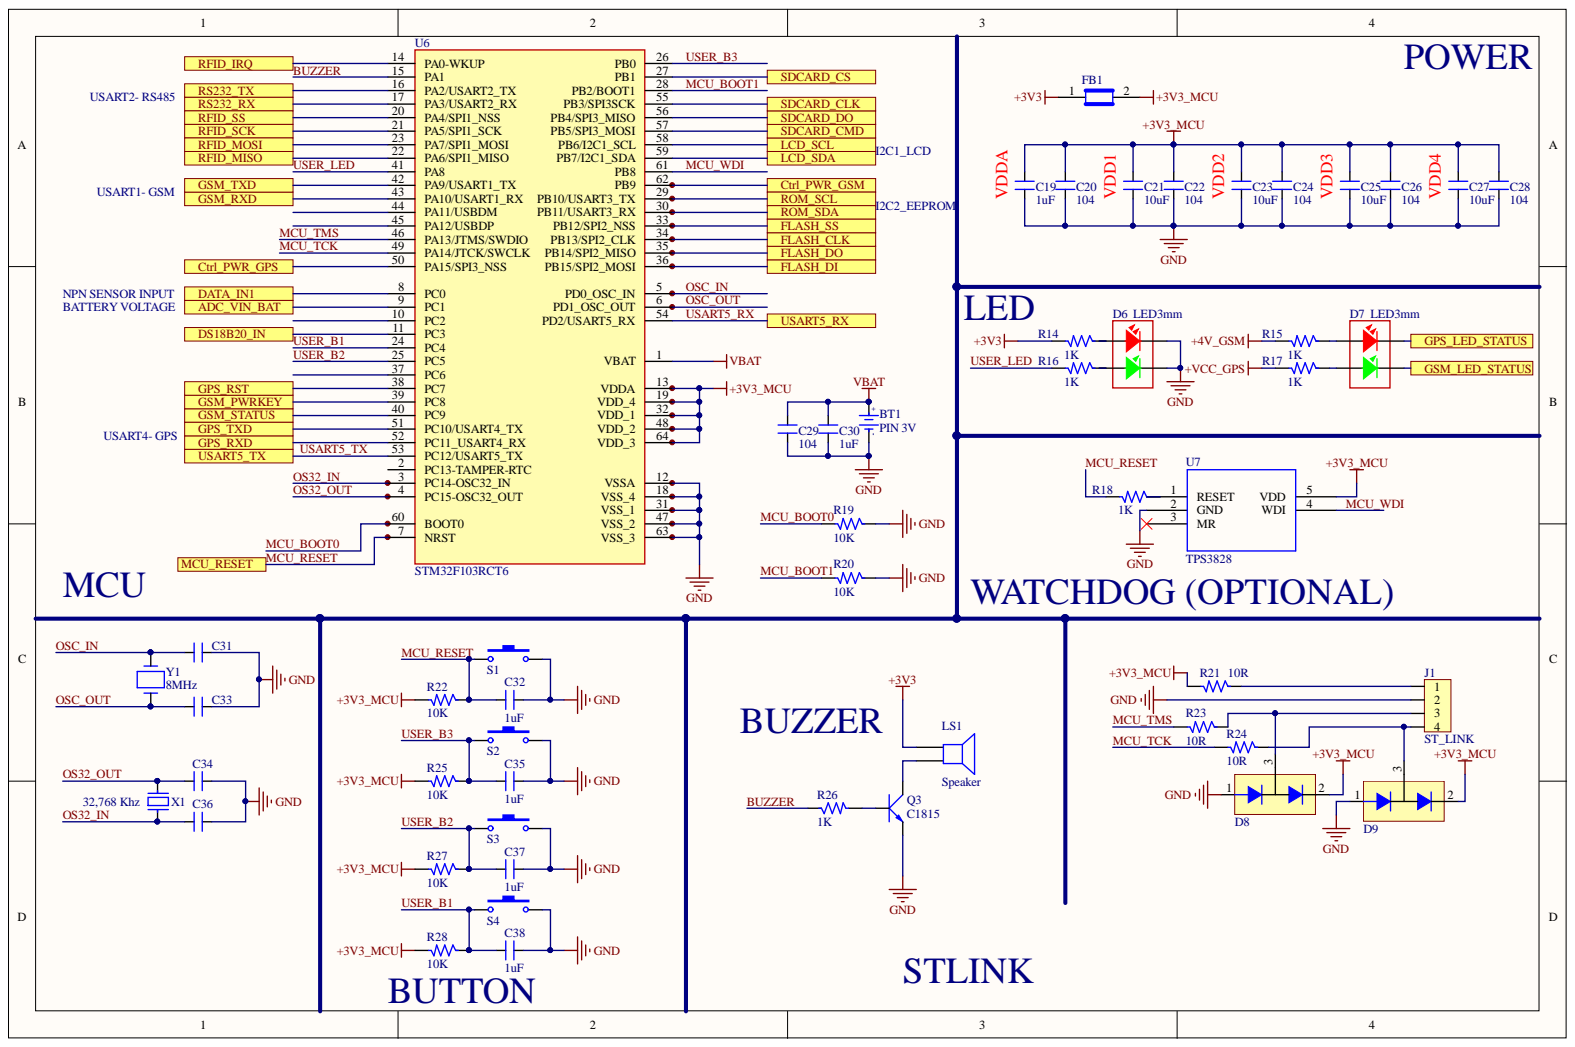
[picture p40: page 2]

RS232_RX | SDCARD_CLK
RFID_SS | SDCARD_DO

RFID_MOSI | | | | LCD_SCL
RFID_MISO | | | | LCD_SDA

USER_LED | PA8 41 | MCU_WDI

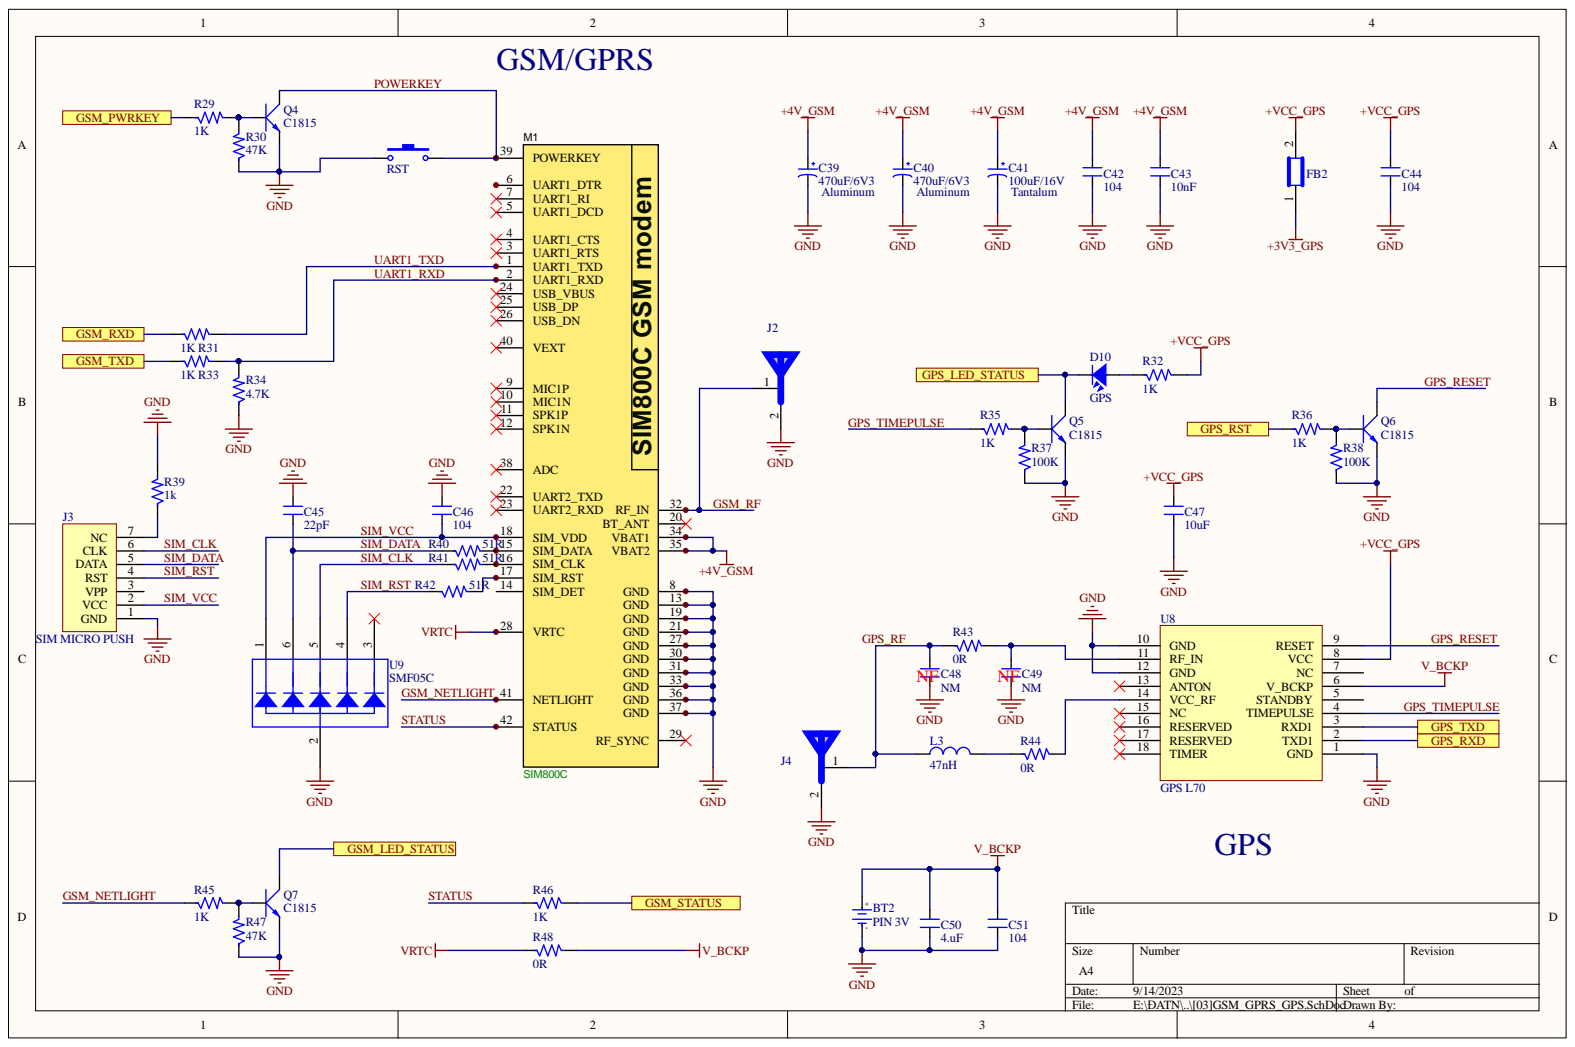
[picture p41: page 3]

UART1_RTS 3 | GND +3V3_GPS GND

UART1_RXD | UART1_RXD 2

USB_VBUS 24

Size A4 | Number | Revision

Date: 9/14/2023 | Sheet of
File: E:\ĐATN\..\[03]GSM_GPRS_GPS.SchDocDrawn By:

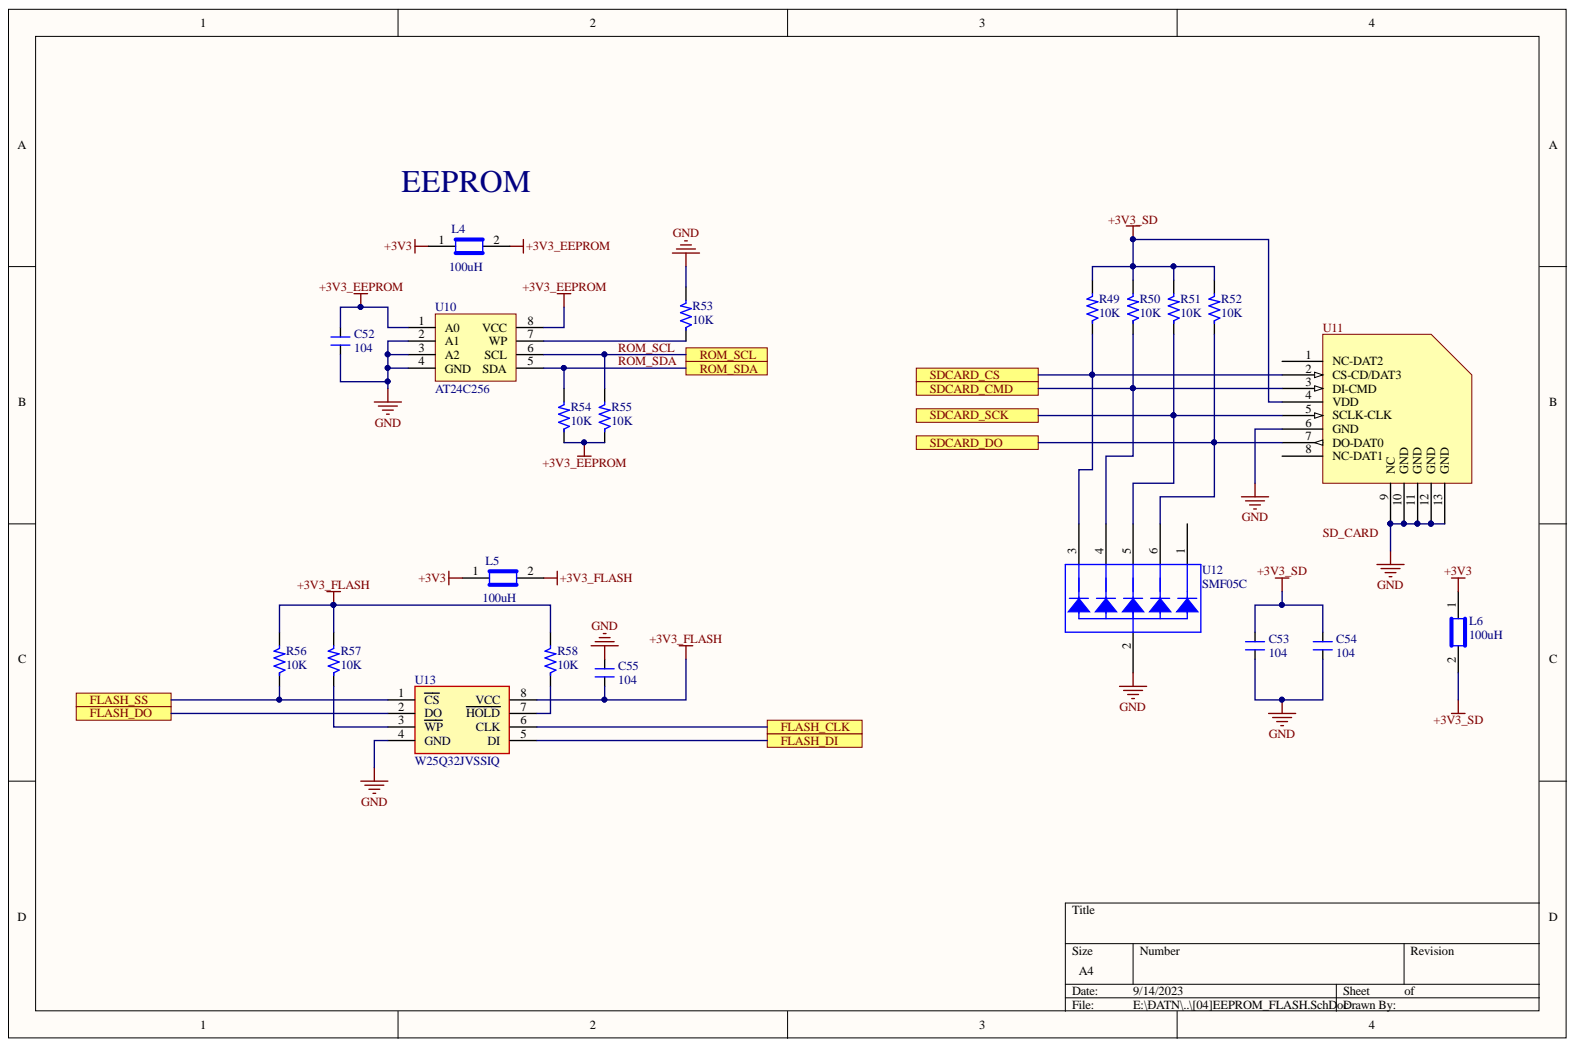
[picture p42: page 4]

ROM_SDA

DI-CMD 3
VDD 4
SCLK-CLK 5
GND 6

NC-DAT1 8

Size A4 | Number | Revision

Date: 9/14/2023 | Sheet of
File: E:\ĐATN\..\[04]EEPROM_FLASH.SchDocDrawn By:

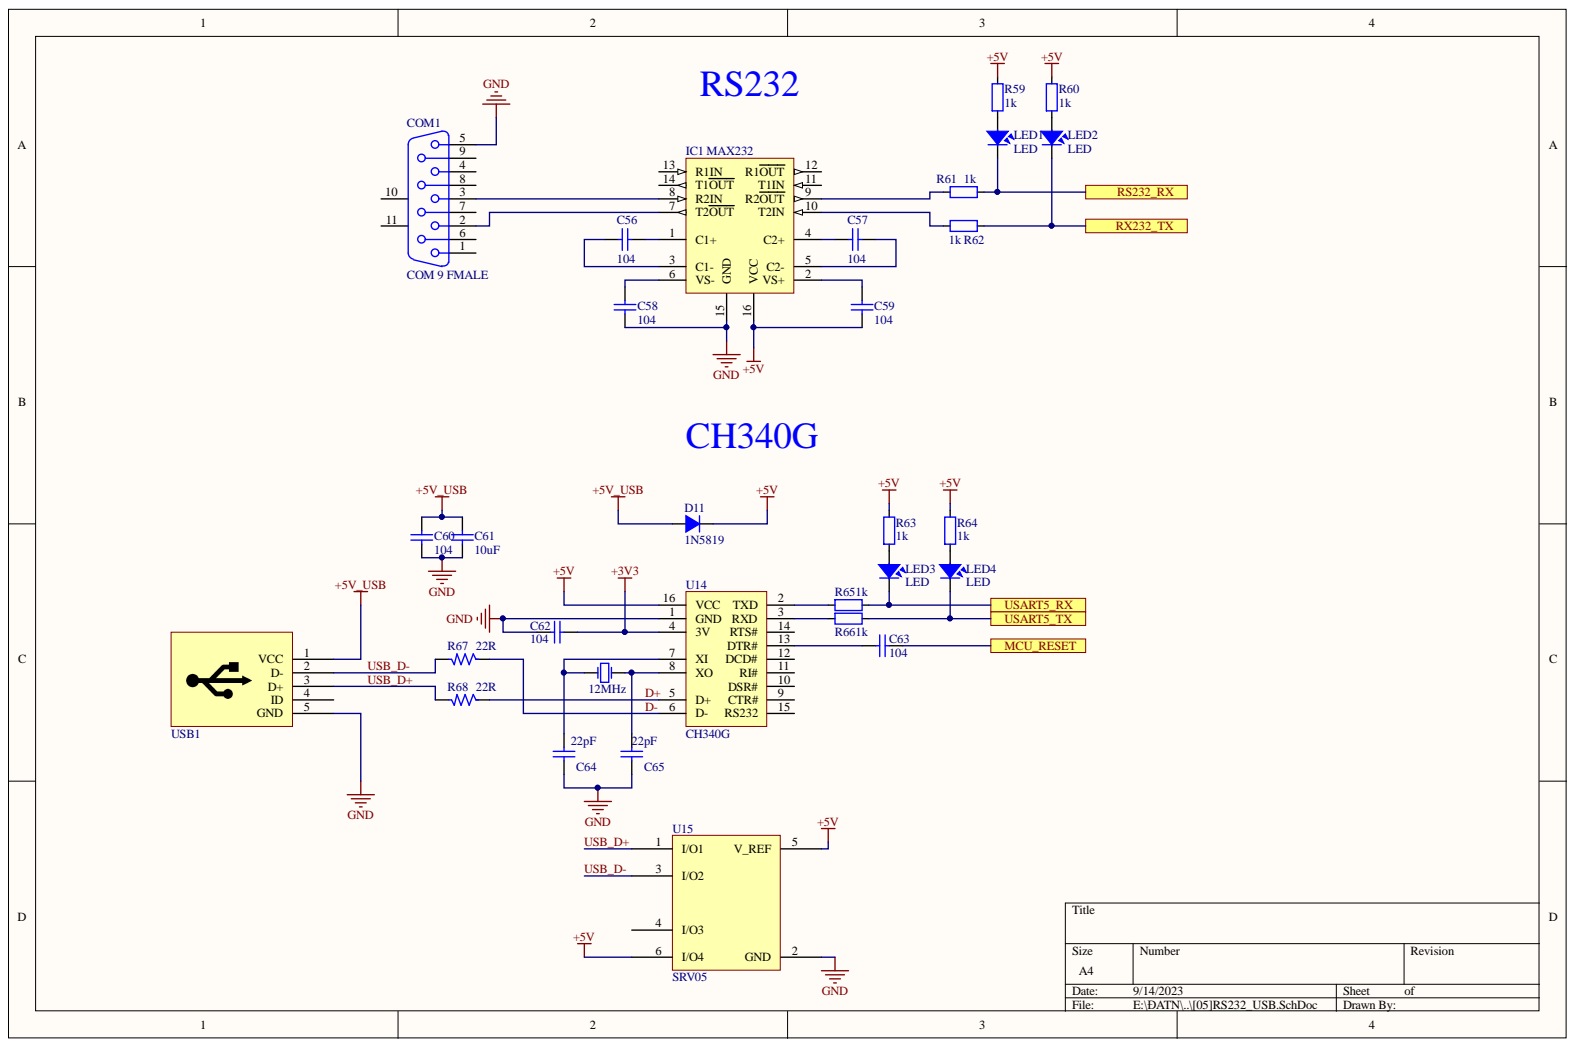
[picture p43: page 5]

Size A4 | Number | Revision

Date: 9/14/2023 | Sheet of
File: E:\ĐATN\..\[05]RS232_USB.SchDoc | Drawn By:

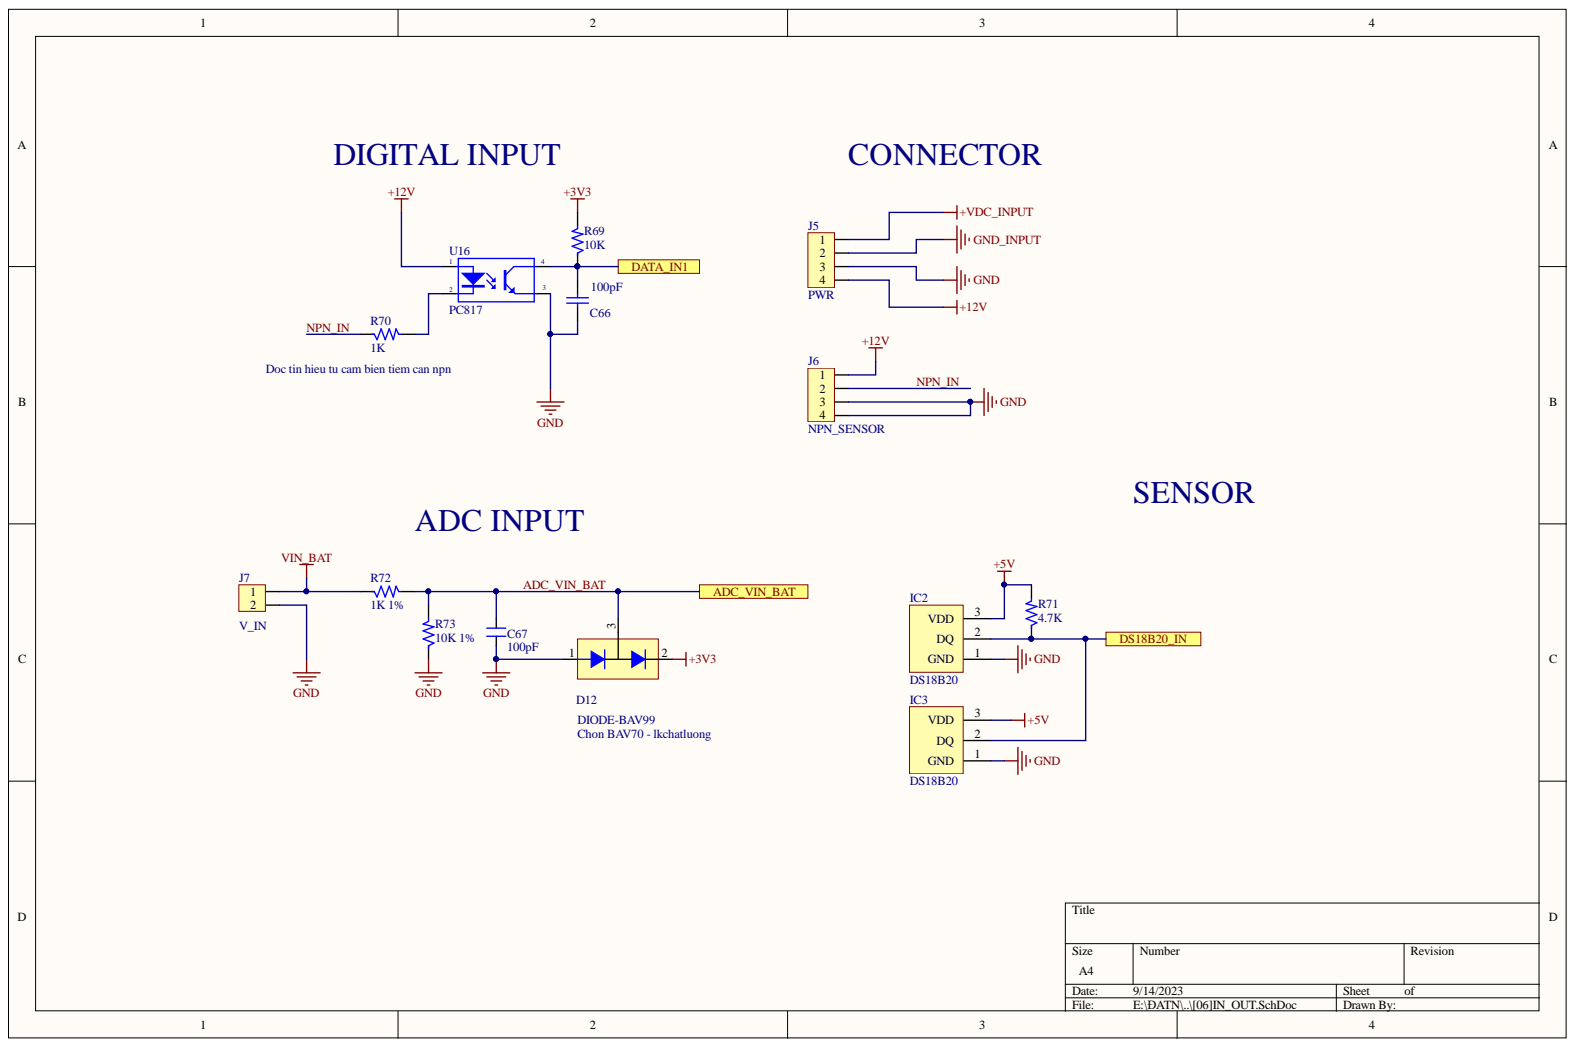
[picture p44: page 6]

Doc tin hieu tu cam bien tiem can npn

Size A4 | Number | Revision

Date: 9/14/2023 | Sheet of
File: E:\ĐATN\..\[06]IN_OUT.SchDoc | Drawn By:

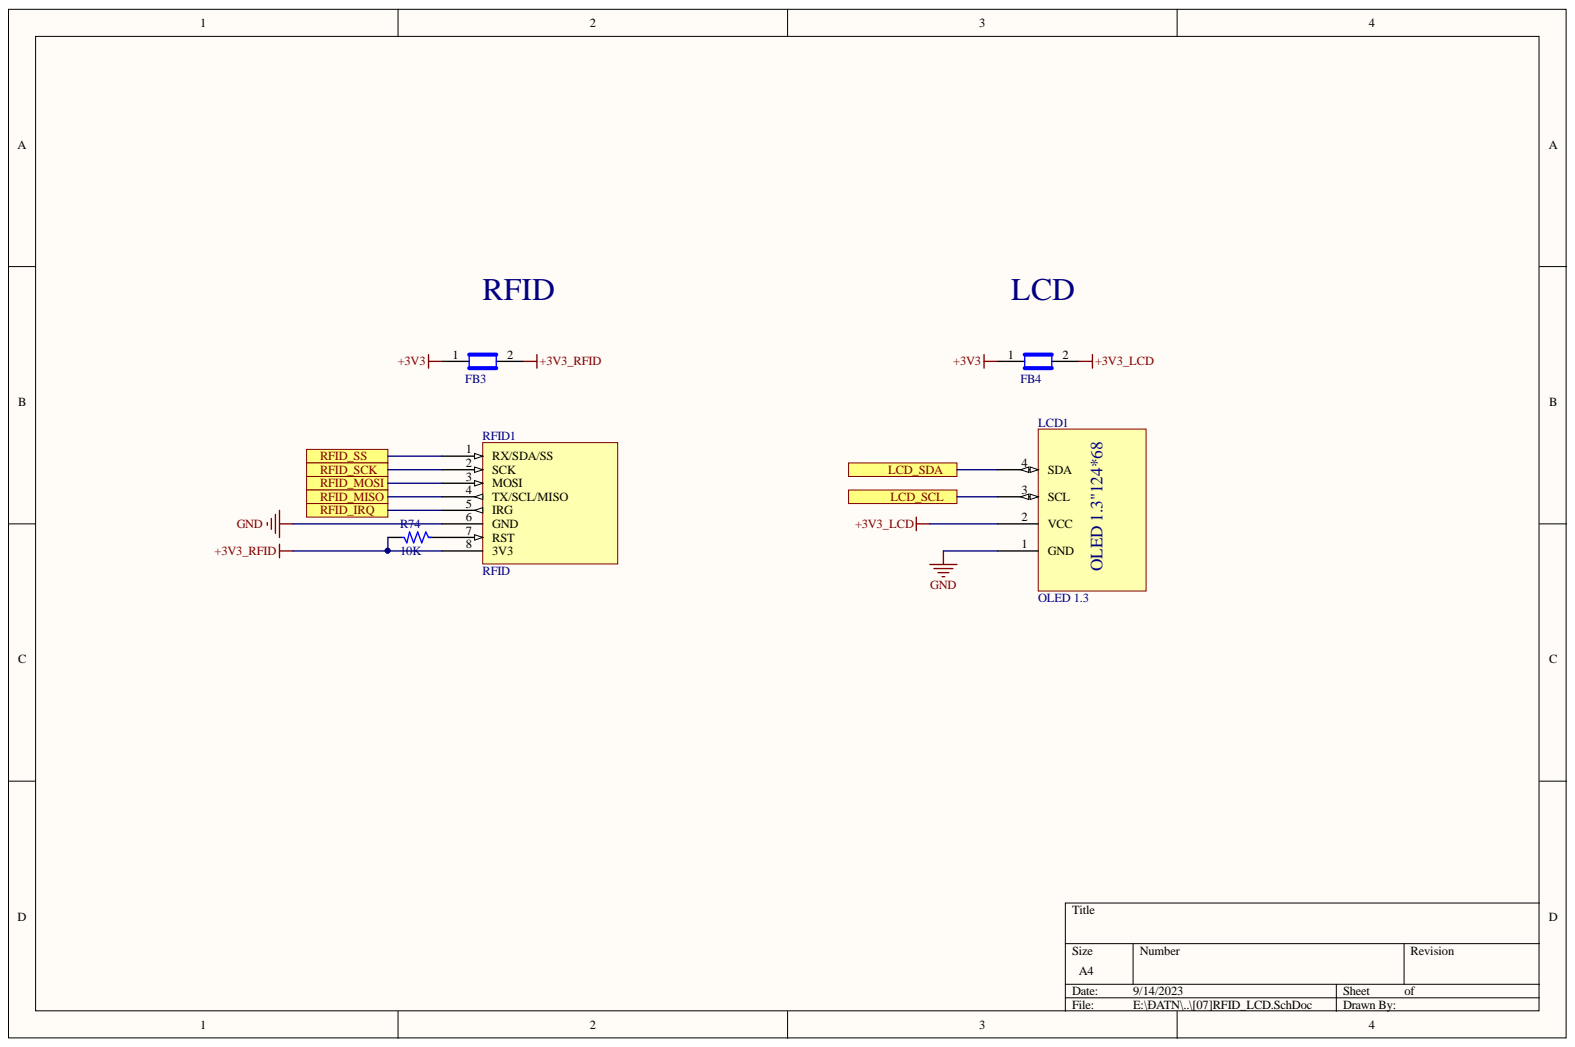
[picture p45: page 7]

Size A4 | Number | Revision

Date: 9/14/2023 | Sheet of
File: E:\ĐATN\..\[07]RFID_LCD.SchDoc | Drawn By:


Numbe r | R evision

: 9/14/2023 | She et of
File : E:\ Đ ATN\. .\G S HT_V1.4. S chDoc | D r a wn By:


Comment | Description | Designator | Footprint | LibRef | Quantity
PIN 3V | Battery 3VDC | BT1, BT2 | CR1220 SMD | PIN 3V | | 2
100uF/100V | Cap 100uF/35V -470uF/16V | C1, C2 | CP1.5/3.4 | CP3 | | 2
5D330K 33V | 5D330K 33V | C3 | CN2 | CN | | 1
104 | Cap SMD, Capacitor | C4, C56, C57, C58, C59, C60, C62, C63 | CAP_0603 | CM_1, CapSMD | | 8
47uF | Cap SMD | C5, C6 | SM-1210 | CM_1 | | 2
1uF | Cap SMD | C7, C8 | CAP_0805 | CM_1 | | 2
2.2uF/100V | CAP CER 2.2UF 100V X7R 1210 445-4498-2-ND | C9, C10, C13 | SM-1210 | CM | | 3
39pF | Cap SMD | C11 | CAP_0805 | CM_1 | | 1
6800pF | Cap SMD | C12 | CAP_0805 | CM_1 | | 1
104 | Cap SMD | C14, C42, C44, C51 | CAP_0805 | CM_1, CM | | 4
10uF/25V | Cap SMD | C15, C16 | CAP_0805 | CM_1 | | 2
10uF/16V | Cap SMD | C17, C18 | CAP_0805 | CM_1 | | 2
1uF | Cap SMD | C19, C30, C32, C35, C37, C38 | C0603 SMT | CM | | 6
104 | Cap SMD | C20, C22, C24, C26, C28, C29, C46, C52, C53, C54, C55 | C0603 SMT | CM | 11
10uF | Cap SMD | C21, C23, C25, C27 | C0603 SMT | CM | | 4
22pF | Cap SMD | C31, C33, C45 | C0603 SMT | CM | | 3
10pF | Cap SMD | C34, C36 | C0603 SMT | CM | | 2
470uF/6V3 | Cap Aluminum | C39, C40 | C_Alu_6.3x7.7 | C-Alu-Tantalum | | 2
100uF/16V | Cap Tantalum 7343 | C41 | C_7343_40 | C-Alu-Tantalum | | 1
10nF | Cap SMD | C43 | CAP_0805 | CM | | 1
10uF | Cap SMD | C47 | CAP_0805 | CM | | 1
NM | Cap SMD | C48, C49 | C0603 SMT | CM | | 2
4.uF | Cap SMD | C50 | SM-1210 | CM | | 1
10uF | Capacitor | C61 | CAP_0603 | CapSMD | | 1
22pF | Capacitor | C64, C65 | CAP_0603 | CapSMD | | 2
100pF | Capacitor, Cap SMD | C66, C67 | CAP_0805 | CapSMD, CM | | 2
COM 9 FMALE | COM 9 | COM1 | DSB 9-F | DSB9F | | 1
B560C-13-F | DIODE SCHOTTKY 60V 5A SMC | D1, D3 | DO-214AB SMC | D5A | | 2
B340-13-F | DIODE SCHOTTKY 40V 3A SMC | D2 | DO-214AB SMA | D1A | | 1
PWR_12V | LED Single colour Green and Red | D4 | LED-0805-Yellow | LED | | 1
PWR_4V | LED Single colour Green and Red | D5 | LED-0805-Green | LED | | 1
LED3mm | LED 2 holder RGB 3mm | D6, D7 | LED 2 holder 3mm | LED2Holder_3mm | | 2
DIODE-BAV99 | ZENER, SOT23, | D8, D9, D12 | SOT23 | DIODE-BAV99 | | 3
GPS | LED Single colour Green and Red | D10 | LED-0805-Red | LED | | 1
1N5819 | Diode 1A | D11 | DO-214AB SMA | D1A_1 | | 1
RKEF300HF-ND | PTC RESET FUSE 60V 3A RADIAL | F1 | FUSE2 | Fuse | | 1
BLM21PG600SN1D | Ferrite Bead | FB1 | RES-SMD-0805 | Ferrite Bead | | 1
BLM21PG600SN1D | Ferrite Bead | FB2, FB3, FB4 | R0805 | Ferrite Bead | | 3
MAX232 | Dual EIA-232 Driver/Receiver | IC1 | MAX232DR | MAX232 | | 1
DS18B20 | High Precision 1-Wire® Digital Thermometer | IC2, IC3 | TO92 | DS18S20 | | 2
ST_LINK | Header IDC, 4 x 1 Pin Vertical 2.54mm Pitch (Non-Boxed, Male) | J1 | CON_4P | Header4 | | 1
GPS_ANTENNA | | J2, J4 | Antenna-MCX5.08-H5 | ANTEN | | 2
SIM MICRO PUSH | | J3 | MICROSIM_PUSH | SIM MICRO PUSH | | 1
PWR | Header 4 (Green) | J5 | Hed4V_3.96 | Hed4 | | 1
NPN_SENSOR | Connector 4 | J6 | CON_2.54mm_4 | Con4 | | 1
V_IN | Connector 2 | J7 | CON_2.54mm_2 | Con2 | | 1
L | Inductor | L1 | L2 UF9.8 | L2x220 | | 1
6.8uH | FIXED IND 6.2UH 5.7A 22.4 MOHM | L2 | L01 SMD 12*12*6 | L1 | | 1
47nH | Inductor | L3 | RES-SMD-0805 | L1 | | 1
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

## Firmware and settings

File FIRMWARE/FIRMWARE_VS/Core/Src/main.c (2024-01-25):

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
/* Includes ------------------------------------------------------------------*/
#include "main.h"
#include "adc.h"
#include "fatfs.h"
#include "i2c.h"
#include "rtc.h"
#include "spi.h"
#include "tim.h"
#include "usart.h"
#include "gpio.h"

/* USER CODE BEGIN Includes */
#include "sensors.h"
#include "rc522.h"
#include "debug.h"
#include "sim4g_lte.h"
#include "gnss.h"
#include "fatfs_sd.h"
#include "mqtt.h"
#include "flash.h"
#include "ssd1306.h"
#include "bitmap.h"

#include <stdio.h>
#include <stdint.h>
#include <string.h>
/* USER CODE END Includes */


/* USER CODE BEGIN PV */
/************************************RFID*********************/
uint8_t CardID[5];
char szBuff[20];
volatile bool waiting4LogOut = false;
volatile bool Logout = false;
enum check
{
  CHANGE,
  NOT_CHANGE
};

volatile int npn_flag_check = NOT_CHANGE;
int npn_count = 0;

enum State
{
  Stop,
  Move
};

int Vehical_State;

float current_time, last_time;
float Vehical_veloc;

/************************************RTC************************/
RTC_TimeTypeDef current_sTime = {0};
RTC_DateTypeDef current_sDate = {0};
RTC_TimeTypeDef last_sTime = {0};
RTC_DateTypeDef last_sDate = {0};
RTC_AlarmTypeDef sAlarm = {0};
uint8_t sencond = 0;
uint8_t minute = 0;
uint8_t hour = 0;
uint8_t date = 0;
uint8_t day = 0;
uint8_t month = 0;
uint8_t year = 0;
char time_buff[20];
char date_buff[20];
volatile int check = 0;

uint16_t totalMinute_OperateTime;
int time_hour;
int time_minute;
char totalMinute_OperateTime_buff[30] = {0};

int numCheck_time = 0;
char utctime_buff[10]={0};
/*********************************** GPS************************/
#define GPS 0
char *GPSResponse;
char latData[15] = {0};
char longData[15] = {0};
char simMessage[200] = {0};

char l70Data1;
char gnss_str[100] = {0};
extern l70Data_t l70DataAfterHadler;

/************************************* SDCARD*******************/
#define SDCard 0
FATFS fs;                      // file system
FIL fil;                       // file
FRESULT fresult;               // store the result
char SD_buffer_w[1024] = {0};  // write data
char SD_buffer_r[10224] = {0}; // read data
char SD_file_name[50] = {0};
UINT br, bw; // file read.write count

FATFS *pfs;
DWORD fre_clust;
uint32_t total, free_space;
char SD_read[256];

/**************************************SIM 4G***************************/
#define SIM 0
// typedef struct
// {
//   char online[2];
//   char offline[2];
//   char sleep[2];
//   char deviceID[20];
//   char license[20];
//   char name[50];
//   char phone[20];
//   char signal[20];
// } dataPubTB_t;
typedef struct
{
  char online[2];
  char offline[2];
  char sleep[2];
  char signal[5];
} stateDevice_t;
stateDevice_t stateDevice;
char Json_Data[500] = {0};
/**************************************RFID*****************************/
uint8_t CardID[5] = {0};
char Card_Startbuff[20] = {0};
char Card_Endbuff[20] = {0};
char *id_ref = "";
typedef struct
{
  char ID[20];      // id     64C43951
  char name[20];    // ABC
  char license[10]; // A1 A2...
  char phoneNum[20];
  char deviceID[20]; // plates license
} infoRFID_t;
infoRFID_t infoUser, infoUser1, infoUser2;

/***************************************TASK**************************/
enum
{
  Task_Sensors,
  Task_GNSS,
  Task_SIM,
  Task_Store,
  Task_Display,
  Task_LogoutOrRS232
};
volatile int Type_Task = Task_Display;
typedef struct
{
  volatile bool TaskSensors;
  volatile bool TaskGNSS;
  volatile bool TaskSIM;
  volatile bool TaskStore;
  volatile bool TaskDisplay;
} TaskPerform_t;

TaskPerform_t Taskperform = {
    .TaskSensors = false,
    .TaskGNSS = false,
    .TaskSIM = false,
    .TaskStore = false,
    .TaskDisplay = false,
};
#define SWITCH_CASE 1
#define IF_SIUTATION 0
enum
{
  Normal_Mode,
  IRQ_Mode
};
volatile int Task_Mode = Normal_Mode;
/*****************************************SENSOR*************************/
int ds18_temp;
float dht_temp;
float dht_hum;

typedef struct
{
  char ds18_buff[5];
  char dhtTemp_buff[50];
  char dhtHum_buff[50];
  char fuel[5];
} sensors_t;
sensors_t sensors;
/*******************************************FLASH***********************/
#define FLASH_ADDRESS_BASE 0x00000000
uint8_t flash_Readbuff[1024] = {0};
/******************************************RS232************************/
char rs232_data;
char rs232_buff[50] = {0};
int rs232_index = 0;
volatile bool rs232_flag = false;
/* USER CODE END PV */

void SystemClock_Config(void);
/* USER CODE BEGIN 0 */
void rs232_logdata(char *str)
{
  HAL_UART_Transmit(&huart2, (uint8_t *)str, strlen(str), 5000);
}

void buzzer(long time)
{
  HAL_GPIO_WritePin(BUZZER_GPIO_Port, BUZZER_Pin, GPIO_PIN_SET);
  HAL_Delay(time);
  HAL_GPIO_WritePin(BUZZER_GPIO_Port, BUZZER_Pin, GPIO_PIN_RESET);
}

void set_alarm(int intervalHour)
{
  RTC_AlarmTypeDef sAlarm = {0};
  sAlarm.AlarmTime.Hours = current_sTime.Hours + intervalHour;
  sAlarm.AlarmTime.Minutes = current_sTime.Minutes;
  sAlarm.AlarmTime.Seconds = current_sTime.Seconds;
  sAlarm.Alarm = RTC_ALARM_A;
  if (HAL_RTC_SetAlarm_IT(&hrtc, &sAlarm, RTC_FORMAT_BIN) != HAL_OK)
  {
    Error_Handler();
  }
}

void set_timer(long time)
{
  TIM3->CNT = 60000 - time * 10;
}

void HAL_RTC_AlarmAEventCallback(RTC_HandleTypeDef *hrtc)
{
  // warning and SMS
  buzzer(5000);
  sim7672_sendSMS(infoUser.phoneNum, "Lai xe qua thoi gian cho phep, xin dung lai");
}

void HAL_UART_RxCpltCallback(UART_HandleTypeDef *huart)
{
  // for SIM
  if (huart == &huart1)
  {
    sim7672_callback();
  }
  // for GPS
  if (huart == &huart4)
  {
    l70_callback();
  }
  // for RS232
  if (huart == &huart2)
  {
    Type_Task = Task_LogoutOrRS232;
    rs232_buff[rs232_index] = rs232_data;
    if (strstr(rs232_buff, "Trichxuatdulieu") != NULL)
    {
      rs232_logdata("OK");
      rs232_flag = true;
    }
    rs232_index++;
    HAL_UART_Receive_IT(&huart2, (uint8_t *)&rs232_data, 1);
  }
}

void HAL_GPIO_EXTI_Callback(uint16_t GPIO_Pin)
{
  // reset timer 2
  HAL_TIM_Base_Stop(&htim2);
  TIM2->CNT = 0;

  current_time = HAL_GetTick();

  npn_flag_check = CHANGE;
  Vehical_State = Move;
  npn_count++;
  if (npn_count == 20)
  {
    float time_cycle = current_time - last_time;
    Vehical_veloc = (1.0 * 3000) / (time_cycle);
    // tinh toan van toc
  }
  // start timer2
  HAL_TIM_Base_Start_IT(&htim2);
}

void HAL_TIM_PeriodElapsedCallback(TIM_HandleTypeDef *htim)
{
  if (htim == &htim2)
  {
    if (rc522_check(CardID) == RC522_OK && waiting4LogOut == true)
    {
      waiting4LogOut = false;
      Type_Task = Task_LogoutOrRS232;
      Logout = true;
    }
  }
  if (htim == &htim3)
  {
    if (Type_Task == Task_Sensors)
    {
      Taskperform.TaskSensors = false;
      Type_Task = Task_GNSS;
      set_timer(200);
      return;
    }
    if (Type_Task == Task_GNSS)
    {
      Taskperform.TaskGNSS = false;
      Type_Task = Task_SIM;
      set_timer(1200);
      return;
    }
    if (Type_Task == Task_SIM)
    {
      Taskperform.TaskSIM = false;
      Type_Task = Task_Store;
      set_timer(200);
      return;
    }
    if (Type_Task == Task_Store)
    {
      Taskperform.TaskStore = false;
      Type_Task = Task_Display;
      set_timer(200);
      return;
    }
    if (Type_Task == Task_Display)
    {
      Taskperform.TaskDisplay = false;
      Type_Task = Task_Sensors;
      set_timer(100);
      return;
    }
  }
}

/* USER CODE END 0 */

/**
 * @brief  The application entry point.
 * @retval int
 */
int main(void)
{
  /* MCU Configuration--------------------------------------------------------*/

  /* Reset of all peripherals, Initializes the Flash interface and the Systick. */
  HAL_Init();

  /* Configure the system clock */
  SystemClock_Config();

  /* Initialize all configured peripherals */
  MX_GPIO_Init();
  MX_ADC1_Init();
  MX_SPI1_Init();
  MX_ADC2_Init();
  MX_TIM1_Init();
  MX_UART5_Init();
  MX_I2C1_Init();
  MX_SPI2_Init();
  MX_SPI3_Init();
  MX_UART4_Init();
  MX_USART1_UART_Init();
  MX_USART2_UART_Init();
  MX_TIM2_Init();
  MX_TIM3_Init();
  MX_RTC_Init();
  MX_FATFS_Init();
  /* USER CODE BEGIN 2 */
  log_data("\nGSHT START\n");
  // init all
  rc522_init();
  log_data("RFID init successfull\n");
  HAL_Delay(10);

  l70_init();
  log_data("GNSS init successfull\n");
  HAL_Delay(500);

  // sim7672_pwrOn();
  // HAL_Delay(4000);
   sim7672_init();
   sim7672_check_signalStrength();
  //  mqtt_disconnectServer();
  //  HAL_Delay(100);
   mqtt_connectServer();
   HAL_Delay(100);

  // w25q32_init();
  // log_data("FLASH init successfull\n");

  SSD1306_Init();

  SSD1306_Clear();
  SSD1306_DrawBitmap(0, 0, bitmap, 128, 64, 1);
  SSD1306_GotoXY(75, 2);
  SSD1306_Puts("2:53", &Font_7x10, 1);
  SSD1306_GotoXY(30, 16);
  SSD1306_Puts("1/1/2023", &Font_7x10, 1);
  SSD1306_GotoXY(1, 28);
  SSD1306_Puts("Lon:            E", &Font_7x10, 1);
  SSD1306_GotoXY(1, 40);
  SSD1306_Puts("Lat:           N", &Font_7x10, 1);
  SSD1306_GotoXY(1, 52);
  SSD1306_Puts("Speed:      m/s", &Font_7x10, 1);
  SSD1306_UpdateScreen();

  fresult = f_mount(&fs, "/", 1);
  if (fresult != FR_OK)
    log_data("ERROR!!! in mounting SD CARD...\n\n");
  else
    log_data("SD CARD mounted successfully...\n\n");
  // Read data FLASH
  strcpy(stateDevice.online, "1");
  strcpy(stateDevice.offline, "0");
  strcpy(stateDevice.sleep, "0");
  strcpy(stateDevice.signal, "OK");

  strcpy(infoUser1.ID, "64C43951");
  strcpy(infoUser1.name, "Nguyen_Huy_Hoang");
  strcpy(infoUser1.phoneNum, "VIE_0987035442");
  strcpy(infoUser1.license, "30N-1234");

  strcpy(infoUser2.ID, "1243");
  strcpy(infoUser2.name, "Nguyen_Van_A");
  strcpy(infoUser2.phoneNum, "VIE_0123562571");
  strcpy(infoUser2.license, "30N-3611");

  strcpy(infoUser.deviceID, "GSHT_ID01");
  // READ TAG RFID
  while (strcmp(infoUser1.ID, Card_Startbuff) != 0 || strcmp(infoUser2.ID, Card_Startbuff) != 0)
  {
    // log_data("wait\n");
    if (rc522_check(CardID) == RC522_OK)
    {
      sprintf(Card_Startbuff, "%02X%02X%02X%02X", CardID[0], CardID[1], CardID[2], CardID[3]);
      log_data(Card_Startbuff);
      if (strcmp(infoUser1.ID, Card_Startbuff) == 0)
      {
        waiting4LogOut = true;
        strcpy(infoUser.ID, infoUser1.ID);
        strcpy(infoUser.name, infoUser1.name);
        strcpy(infoUser.phoneNum, infoUser1.phoneNum);
        strcpy(infoUser.license, infoUser1.license);
        buzzer(200);
        // HAL_Delay(200);
        // buzzer(200);
        log_data("ID1 TAG valid\n");
      }
      if (strcmp(infoUser2.ID, Card_Startbuff) == 0)
      {
        waiting4LogOut = true;
        strcpy(infoUser.ID, infoUser2.ID);
        strcpy(infoUser.name, infoUser2.name);
        strcpy(infoUser.phoneNum, infoUser2.phoneNum);
        strcpy(infoUser.license, infoUser2.license);
        buzzer(200);
        // HAL_Delay(200);
        // buzzer(200);
        log_data("ID2 TAG valid\n");
      }
      else
      {
        // waiting4LogOut = true;
        buzzer(200);
        HAL_Delay(200);
        buzzer(200);
        log_data("ID TAG invalid\n");
        break;
      }
    }
  }
  // collect time at having RFID TAG
  HAL_RTC_GetTime(&hrtc, &current_sTime, RTC_FORMAT_BIN);
  HAL_RTC_GetDate(&hrtc, &current_sDate, RTC_FORMAT_BIN);
  set_alarm(4);
  sprintf(time_buff, "%d:%d:%d", current_sTime.Hours, current_sTime.Minutes, current_sTime.Seconds);
  log_data(time_buff);
  log_data("\n");
  sprintf(date_buff, "%d/%d/%d", current_sDate.Date, current_sDate.Month, current_sDate.Year);
  log_data(date_buff);
  log_data("\n");
  HAL_RTC_GetTime(&hrtc, &last_sTime, RTC_FORMAT_BIN);
  HAL_RTC_GetDate(&hrtc, &last_sDate, RTC_FORMAT_BIN);
  totalMinute_OperateTime = (60 * last_sTime.Hours + last_sTime.Minutes) - (60 * current_sTime.Hours + current_sTime.Minutes);
  time_hour = totalMinute_OperateTime / 60;
  time_minute = totalMinute_OperateTime - time_hour * 60;
  sprintf(totalMinute_OperateTime_buff, "%dh%d", time_hour, time_minute);
  // wait for gps
  do
  {
    GPSResponse = l70_receiveGPS();
    l70_handleGPS(GPSResponse);
    HAL_Delay(1000);
  } while (strstr(l70DataAfterHadler.latitude, ".000000") != NULL && strstr(l70DataAfterHadler.longitude, ".000000") != NULL);
  log_data("\nGSHT Start\n");
  // Check ID tag in Flash

  set_timer(500);
  HAL_TIM_Base_Start_IT(&htim3); // Task
  HAL_TIM_Base_Start(&htim1);    // Sensors
  HAL_TIM_Base_Start_IT(&htim2); // RFID
  // set_timer(1000);
  HAL_UART_Receive_IT(&huart2, (uint8_t *)&rs232_data, 1);
  /* USER CODE END 2 */

  /* Infinite loop */
  /* USER CODE BEGIN WHILE */
  while (1)
  {
    /* USER CODE END WHILE */

    /* USER CODE BEGIN 3 */
#if SWITCH_CASE
    switch (Type_Task)
    {
    case Task_Sensors:
      if (!Taskperform.TaskSensors)
      {
        log_data("TAKS SENSORS\n");
        Taskperform.TaskSensors = true;
        ds18_temp = (int)DS18B20_Result();
        // DHT11_Result(dht_temp, dht_hum);
        sprintf(sensors.ds18_buff, "%d", ds18_temp);
        // sprintf(sensors.dhtTemp_buff,"%d",(int)dht_temp);
        // sprintf(sensors.dhtHum_buff,"%d",(int)dht_hum);
        // ftoa(ds18_temp, ds18_buff, 1);
        //  w25q32_pageWrite(0x00000000,ds18_buff);
        //  ftoa(dht_temp, dhtTemp_buff, 1);
        //  ftoa(dht_hum, dhtHum_buff, 1);
        strcpy(sensors.dhtTemp_buff, "20");
        strcpy(sensors.dhtHum_buff, "80");
        // log_data("Nhiet do va do am moi truong: ");
        // log_data(sensors.dhtTemp_buff);
        // log_data("\n");
        // log_data(sensors.dhtHum_buff);
        // log_data("\n");
        strcpy(sensors.fuel, "80");
        log_data("Nhiet do thiet bi: ");
        log_data(sensors.ds18_buff);
        log_data("\n");
      }
      break;
    case Task_GNSS:
      if (!Taskperform.TaskGNSS)
      {
        log_data("TAKS GNSS\n");
        Taskperform.TaskGNSS = true;
        GPSResponse = l70_receiveGPS();
        l70_handleGPS(GPSResponse);
      }
      break;
    case Task_SIM:
      if (!Taskperform.TaskSIM)
      {
        log_data("TAKS SIM\n");
        Taskperform.TaskSIM = true;
        memset(Json_Data,'\0',sizeof(Json_Data));
        sprintf(totalMinute_OperateTime_buff, "%dh%d", time_hour, time_minute);
        sprintf(Json_Data, "{\"online\":%s,\"offline\":%s,\"sleep\":%s,\"deviceID\":%s,\"license\":%s,\"name\":%s,\"phone\":%s,\"signal\":%s,\"latitude\":%s,\"longitude\":%s,\"ds18b20\":%s,\"dhttemp\":%s,\"dhthum\":%s,\"fuel\":%s,\"timetotal\":%s,\"speed\":%s}",
                stateDevice.online, stateDevice.offline, stateDevice.sleep, infoUser.deviceID, infoUser.license, infoUser.name, infoUser.phoneNum,
                stateDevice.signal, l70DataAfterHadler.latitude, l70DataAfterHadler.longitude, sensors.ds18_buff, sensors.dhtTemp_buff,
                sensors.dhtHum_buff, sensors.fuel,totalMinute_OperateTime_buff,l70DataAfterHadler.Speed);
        mqtt_pub(TOPIC, Json_Data);
        numCheck_time++;
        if (numCheck_time == 10)
        {
          numCheck_time = 0;
          HAL_RTC_GetTime(&hrtc, &last_sTime, RTC_FORMAT_BIN);
          HAL_RTC_GetDate(&hrtc, &last_sDate, RTC_FORMAT_BIN);
          totalMinute_OperateTime = (60 * last_sTime.Hours + last_sTime.Minutes) - (60 * current_sTime.Hours + current_sTime.Minutes);
          time_hour = totalMinute_OperateTime / 60;
          time_minute = totalMinute_OperateTime - time_hour * 60;
          sprintf(totalMinute_OperateTime_buff, "%dh%d", time_hour, time_minute);
          log_data("\nTotal time: ");
          log_data(totalMinute_OperateTime_buff);
          log_data("\n");
        }
      }
      break;
    case Task_Store:
      if (!Taskperform.TaskStore)
      {
        log_data("TASK STORE\n");
        Taskperform.TaskStore = true;

        fresult = f_open(&fil, "GSHT1.txt", FA_WRITE);
        if (fresult != FR_OK)
          log_data("open error...\n\n");
        else
          log_data("open successfully...\n\n");

        f_lseek(&fil, f_size(&fil));

        f_puts(l70DataAfterHadler.utcTime, &fil);
        f_puts("\t", &fil);
        f_puts(Card_Startbuff, &fil);
        f_puts("\t", &fil);
        f_puts(l70DataAfterHadler.latitude, &fil);
        f_puts("\t", &fil);
        f_puts(l70DataAfterHadler.longitude, &fil);
        f_puts("\t", &fil);
        f_puts(l70DataAfterHadler.Speed, &fil);
        f_puts("\t", &fil);
        f_puts(sensors.ds18_buff, &fil);
        f_puts("\n", &fil);

        fresult = f_close(&fil);
      }
      break;
    case Task_Display:
      if (!Taskperform.TaskDisplay)
      {
        log_data("TASK DISPLAY\n");
        Taskperform.TaskDisplay = true;
        memset(utctime_buff,'\0',sizeof(utctime_buff));
        strncpy(utctime_buff,l70DataAfterHadler.utcTime,5);
        SSD1306_GotoXY(75, 2);
        SSD1306_Puts(utctime_buff, &Font_7x10, 1);
        SSD1306_GotoXY(30, 16);
        SSD1306_Puts(l70DataAfterHadler.Date, &Font_7x10, 1);
        SSD1306_GotoXY(30, 28);
        SSD1306_Puts(l70DataAfterHadler.longitude, &Font_7x10, 1);
        SSD1306_GotoXY(30, 40);
        SSD1306_Puts(l70DataAfterHadler.latitude, &Font_7x10, 1);
        SSD1306_GotoXY(45, 52);
        SSD1306_Puts(l70DataAfterHadler.Speed, &Font_7x10, 1);
        SSD1306_UpdateScreen();
      }
      break;
    case Task_LogoutOrRS232:
      // rs232_logdata("Task Logout or RS232\n");
      if (Logout)
      {
        Logout = false;
        sprintf(Card_Endbuff, "%02X%02X%02X%02X", CardID[0], CardID[1], CardID[2], CardID[3]);
        if (strcmp(Card_Startbuff, Card_Endbuff) != 0)
        {
          log_data("Tag invalid\n");
        }
        else
        {
          log_data("Tag valid, End of schedual\n");
          // write flash totaltime
          mqtt_pub(TOPIC, "{\"signal\":LOGOUT}");
          HAL_RTC_GetTime(&hrtc, &last_sTime, RTC_FORMAT_BIN);
          HAL_RTC_GetDate(&hrtc, &last_sDate, RTC_FORMAT_BIN);
          totalMinute_OperateTime = (60 * last_sTime.Hours + last_sTime.Minutes) - (60 * current_sTime.Hours + current_sTime.Minutes);
          set_alarm(10);
          buzzer(200);
          HAL_Delay(200);
          buzzer(200);
        }
        // sleep
        HAL_Delay(1000);
        log_data("Device start sleep\n");
      }
      if (rs232_flag)
      {
        rs232_flag = false;
        rs232_logdata("READ\n");
        if (strstr(rs232_buff, "Trichxuatdulieu") != NULL)
        {
          fresult = f_open(&fil, "GSHT1.txt", FA_READ);
          if (fresult != FR_OK)
            log_data("open error...\n\n");
          else
            log_data("open successfully...\n\n");
          while (f_gets(SD_read, sizeof(SD_read), &fil) != NULL)
          {
            rs232_logdata(SD_read);
          }
        }
      }
      break;
    }
    HAL_Delay(100);
#endif
    // HAL_Delay(100);
  }
  /* USER CODE END 3 */
}

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
/* USER CODE BEGIN 4 */
#if IF_SIUTATION
if (Type_Task == Task_Sensors && !Taskperform.TaskSensors)
{
  log_data("TAKS SENSORS\n");
  Taskperform.TaskSensors = true;
  log_data("TAKS SENSORS\n");
  Taskperform.TaskSensors = true;
  ds18_temp = (int)DS18B20_Result();
  // DHT11_Result(dht_temp, dht_hum);
  sprintf(ds18_buff, "%d", ds18_temp);
  // ftoa(ds18_temp, ds18_buff, 1);
  //  w25q32_pageWrite(0x00000000,ds18_buff);
  //  ftoa(dht_temp, dhtTemp_buff, 1);
  //  ftoa(dht_hum, dhtHum_buff, 1);
  log_data("Nhiet do thiet bi: ");
  log_data(ds18_buff);
  log_data("\n");
}
if (Type_Task == Task_GNSS && !Taskperform.TaskGNSS)
{
  log_data("TAKS GNSS\n");
  Taskperform.TaskGNSS = true;
  GPSResponse = l70_receiveGPS();
  l70_handleGPS(GPSResponse);
}
if (Type_Task == Task_SIM && !Taskperform.TaskSIM)
{

  log_data("TAKS SIM\n");
  Taskperform.TaskSIM = true;
  // mqtt_pub(TOPIC_TEST, Card_Startbuff);
  // mqtt_pub(TOPIC_TEST, ds18_buff);
  // // mqtt_pub(TOPIC_TEST, dhtHum_buff);
  // // mqtt_pub(TOPIC_TEST, dhtTemp_buff);
  // mqtt_pub(TOPIC_TEST, l70DataAfterHadler.longitude);
  // mqtt_pub(TOPIC_TEST, l70DataAfterHadler.latitude);
  // numCheck_time++;
  // if (numCheck_time == 10)
  // {
  //   numCheck_time = 0;
  //   HAL_RTC_GetTime(&hrtc, &last_sTime, RTC_FORMAT_BIN);
  //   HAL_RTC_GetDate(&hrtc, &last_sDate, RTC_FORMAT_BIN);
  //   totalMinute_OperateTime = (60 * last_sTime.Hours + last_sTime.Minutes) - (60 * current_sTime.Hours + current_sTime.Minutes);
  //   sprintf(totalMinute_OperateTime_buff, "totalTime: %d", totalMinute_OperateTime);
  //   mqtt_pub(TOPIC_TEST, totalMinute_OperateTime_buff);
  // }
}
if (Type_Task == Task_Store && !Taskperform.TaskStore)
{
  log_data("TASK STORE\n");
  Taskperform.TaskStore = true;

  fresult = f_open(&fil, "GSHT1.txt", FA_WRITE);
  if (fresult != FR_OK)
    log_data("open error...\n\n");
  else
    log_data("open successfully...\n\n");

  f_lseek(&fil, f_size(&fil));

  f_puts(l70DataAfterHadler.utcTime, &fil);
  f_puts("\t", &fil);
  f_puts(Card_Startbuff, &fil);
  f_puts("\t", &fil);
  f_puts(l70DataAfterHadler.latitude, &fil);
  f_puts("\t", &fil);
  f_puts(l70DataAfterHadler.longitude, &fil);
  f_puts("\t", &fil);
  f_puts(l70DataAfterHadler.Speed, &fil);
  f_puts("\t", &fil);
  f_puts(ds18_buff, &fil);
  f_puts("\n", &fil);

  fresult = f_close(&fil);
}
if (Type_Task == Task_Display && !Taskperform.TaskDisplay)
{
  log_data("TASK DISPLAY\n");
  Taskperform.TaskDisplay = true;
}
HAL_Delay(100);
#endif
// #if SIM
//   // sim7672_pwrOn();
//   // HAL_Delay(5000);
//   sim7672_init();
//   sim7672_check_signalStrength();
//   HAL_Delay(500);
//   // mqtt_disconnectServer();
//   HAL_Delay(1000);
//   mqtt_connectServer();
//   mqtt_pub("test1z", "123456789");
//   HAL_Delay(500);
//   mqtt_sub("test1z");
// #endif

// #if GPS
//   sim7672_pwrOff();
//   l70_init();
//   HAL_Delay(1000);
// #endif

// #if SDCard

//   fresult = f_mount(&fs, "/", 1);
//   if (fresult != FR_OK)
//     log_data("ERROR!!! in mounting SD CARD...\n\n");
//   else
//     log_data("*******************\nSD CARD mounted successfully...\n\n");
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

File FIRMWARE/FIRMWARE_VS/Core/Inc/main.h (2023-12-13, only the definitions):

#define NPN_DATA_IN_Pin GPIO_PIN_0
#define NPN_DATA_IN_GPIO_Port GPIOC
#define ADC_VIN_ACCQI_Pin GPIO_PIN_1
#define ADC_VIN_ACCQI_GPIO_Port GPIOC
#define LEVEL_SENSOR_Pin GPIO_PIN_2
#define LEVEL_SENSOR_GPIO_Port GPIOC
#define DS18B20_SENSOR_Pin GPIO_PIN_3
#define DS18B20_SENSOR_GPIO_Port GPIOC
#define BUZZER_Pin GPIO_PIN_1
#define BUZZER_GPIO_Port GPIOA
#define RS232_TX_Pin GPIO_PIN_2
#define RS232_TX_GPIO_Port GPIOA
#define RS232_RX_Pin GPIO_PIN_3
#define RS232_RX_GPIO_Port GPIOA
#define RFID_SS_Pin GPIO_PIN_4
#define RFID_SS_GPIO_Port GPIOA
#define DHT11_SENSOR_Pin GPIO_PIN_4
#define DHT11_SENSOR_GPIO_Port GPIOC
#define SDCARD_SS_Pin GPIO_PIN_1
#define SDCARD_SS_GPIO_Port GPIOB
#define FLASH_SS_Pin GPIO_PIN_12
#define FLASH_SS_GPIO_Port GPIOB
#define FLASH_CLK_Pin GPIO_PIN_13
#define FLASH_CLK_GPIO_Port GPIOB
#define FLASH_MISO_Pin GPIO_PIN_14
#define FLASH_MISO_GPIO_Port GPIOB
#define FLASH_MOSI_Pin GPIO_PIN_15
#define FLASH_MOSI_GPIO_Port GPIOB
#define GNSS_CTRL_PWR_Pin GPIO_PIN_8
#define GNSS_CTRL_PWR_GPIO_Port GPIOC
#define GNSS_RESET_Pin GPIO_PIN_9
#define GNSS_RESET_GPIO_Port GPIOC
#define SIM_STATUS_Pin GPIO_PIN_8
#define SIM_STATUS_GPIO_Port GPIOA
#define SIM_TX_Pin GPIO_PIN_9
#define SIM_TX_GPIO_Port GPIOA
#define SIM_RX_Pin GPIO_PIN_10
#define SIM_RX_GPIO_Port GPIOA
#define SIM_CTRL_PWR_Pin GPIO_PIN_11
#define SIM_CTRL_PWR_GPIO_Port GPIOA
#define SIM_PWRKEY_Pin GPIO_PIN_12
#define SIM_PWRKEY_GPIO_Port GPIOA
#define SIM_RESET_Pin GPIO_PIN_15
#define SIM_RESET_GPIO_Port GPIOA
#define GNSS_TX_Pin GPIO_PIN_10
#define GNSS_TX_GPIO_Port GPIOC
#define GNSS_RX_Pin GPIO_PIN_11
#define GNSS_RX_GPIO_Port GPIOC
#define DEBUG_TX_Pin GPIO_PIN_12
#define DEBUG_TX_GPIO_Port GPIOC
#define DEBUG_RX_Pin GPIO_PIN_2
#define DEBUG_RX_GPIO_Port GPIOD
#define SDCARD_CLK_Pin GPIO_PIN_3
#define SDCARD_CLK_GPIO_Port GPIOB
#define SDCARD_MISO_Pin GPIO_PIN_4
#define SDCARD_MISO_GPIO_Port GPIOB
#define SDCARD_MOSI_Pin GPIO_PIN_5
#define SDCARD_MOSI_GPIO_Port GPIOB
#define OLED_SCL_Pin GPIO_PIN_6
#define OLED_SCL_GPIO_Port GPIOB
#define OLED_SDA_Pin GPIO_PIN_7
#define OLED_SDA_GPIO_Port GPIOB

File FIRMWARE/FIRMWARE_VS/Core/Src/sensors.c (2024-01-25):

#include "sensors.h"



enum State
{
	Stop,
	Move
};

int detect;

void delay(uint16_t time)
{
	/* change your code here for the delay in microseconds */
	__HAL_TIM_SET_COUNTER(&htim1, 0);
	while ((__HAL_TIM_GET_COUNTER(&htim1)) < time)
		;
}

void Set_Pin_Output(GPIO_TypeDef *GPIOx, uint16_t GPIO_Pin)
{
	GPIO_InitTypeDef GPIO_InitStruct = {0};
	GPIO_InitStruct.Pin = GPIO_Pin;
	GPIO_InitStruct.Mode = GPIO_MODE_OUTPUT_PP;
	GPIO_InitStruct.Speed = GPIO_SPEED_FREQ_LOW;
	HAL_GPIO_Init(GPIOx, &GPIO_InitStruct);
}

void Set_Pin_Input(GPIO_TypeDef *GPIOx, uint16_t GPIO_Pin)
{
	GPIO_InitTypeDef GPIO_InitStruct = {0};
	GPIO_InitStruct.Pin = GPIO_Pin;
	GPIO_InitStruct.Mode = GPIO_MODE_INPUT;
	GPIO_InitStruct.Pull = GPIO_PULLUP;
	HAL_GPIO_Init(GPIOx, &GPIO_InitStruct);
}

/***************************DS18B20***********************/
uint8_t DS18B20_Start(void)
{
	uint8_t Response = INIT_FAIL;
	Set_Pin_Output(DS18B20_SENSOR_GPIO_Port, DS18B20_SENSOR_Pin);		// set the pin as output
	HAL_GPIO_WritePin(DS18B20_SENSOR_GPIO_Port, DS18B20_SENSOR_Pin, 0); // pull the pin low
	delay(480);															// delay according to datasheet

	Set_Pin_Input(DS18B20_SENSOR_GPIO_Port, DS18B20_SENSOR_Pin); // set the pin as input
	delay(80);													 // delay according to datasheet

	if (!(HAL_GPIO_ReadPin(DS18B20_SENSOR_GPIO_Port, DS18B20_SENSOR_Pin)))
		Response = INIT_SUCCESS; // if the pin is low i.e the presence pulse is detected
	else
		Response = INIT_FAIL;

	delay(400); // 480 us delay totally.

	return Response;
}

void DS18B20_Write(uint8_t data)
{
	Set_Pin_Output(DS18B20_SENSOR_GPIO_Port, DS18B20_SENSOR_Pin); // set as output

	for (int i = 0; i < 8; i++)
	{

		if ((data & (1 << i)) != 0) // if the bit is high
		{
			// write 1

			Set_Pin_Output(DS18B20_SENSOR_GPIO_Port, DS18B20_SENSOR_Pin);		// set as output
			HAL_GPIO_WritePin(DS18B20_SENSOR_GPIO_Port, DS18B20_SENSOR_Pin, 0); // pull the pin LOW
			delay(1);															// wait for 1 us

			Set_Pin_Input(DS18B20_SENSOR_GPIO_Port, DS18B20_SENSOR_Pin); // set as input
			delay(50);													 // wait for 60 us
		}

		else // if the bit is low
		{
			// write 0

			Set_Pin_Output(DS18B20_SENSOR_GPIO_Port, DS18B20_SENSOR_Pin);
			HAL_GPIO_WritePin(DS18B20_SENSOR_GPIO_Port, DS18B20_SENSOR_Pin, 0); // pull the pin LOW
			delay(50);															// wait for 60 us

			Set_Pin_Input(DS18B20_SENSOR_GPIO_Port, DS18B20_SENSOR_Pin);
		}
	}
}

uint8_t DS18B20_Read(void)
{
	uint8_t value = 0;

	Set_Pin_Input(DS18B20_SENSOR_GPIO_Port, DS18B20_SENSOR_Pin);

	for (int i = 0; i < 8; i++)
	{
		Set_Pin_Output(DS18B20_SENSOR_GPIO_Port, DS18B20_SENSOR_Pin); // set as output

		HAL_GPIO_WritePin(DS18B20_SENSOR_GPIO_Port, DS18B20_SENSOR_Pin, 0); // pull the data pin LOW
		delay(1);															// wait for > 1us

		Set_Pin_Input(DS18B20_SENSOR_GPIO_Port, DS18B20_SENSOR_Pin);		// set as input
		if (HAL_GPIO_ReadPin(DS18B20_SENSOR_GPIO_Port, DS18B20_SENSOR_Pin)) // if the pin is HIGH
		{
			value |= 1 << i; // read = 1
		}
		delay(50); // wait for 60 us
	}
	return value;
}

float DS18B20_Result(void)
{
	uint8_t Presence = INIT_FAIL;
	uint8_t Temp_byte1, Temp_byte2;
	uint16_t TEMP;
	float Temperature;
	Presence = DS18B20_Start();
	while(Presence!=INIT_SUCCESS)
	{
		log_data("Init ds18b20 fail\nInit again\n");
		Presence = DS18B20_Start();
	}
	// log_data("ds int successfull\n");
	HAL_Delay(1);
	DS18B20_Write(0xCC); // skip ROM
	DS18B20_Write(0x44); // convert t
	HAL_Delay(800);

	Presence = DS18B20_Start();
	HAL_Delay(1);
	DS18B20_Write(0xCC); // skip ROM
	DS18B20_Write(0xBE); // Read Scratch-pad

	Temp_byte1 = DS18B20_Read();
	Temp_byte2 = DS18B20_Read();
	TEMP = (Temp_byte2 << 8) | Temp_byte1;
	Temperature = (float)TEMP / 16;
	return Temperature;
}

/*****************************DHT11*************************/
void DHT11_Start(void)
{
	Set_Pin_Output(DHT11_SENSOR_GPIO_Port, DHT11_SENSOR_Pin);		// set the pin as output
	HAL_GPIO_WritePin(DHT11_SENSOR_GPIO_Port, DHT11_SENSOR_Pin, 0); // pull the pin low
	delay(20000);													// wait for 18ms		1.2ms for DHT22 10ms
	HAL_GPIO_WritePin(DHT11_SENSOR_GPIO_Port, DHT11_SENSOR_Pin, 1); // pull the pin high
	delay(30);														// wait for 20us
	Set_Pin_Input(DHT11_SENSOR_GPIO_Port, DHT11_SENSOR_Pin);		// set as input
}

uint8_t DHT11_Check_Response(void)
{
	uint8_t Response = INIT_FAIL;
	delay(40);
	if (!(HAL_GPIO_ReadPin(DHT11_SENSOR_GPIO_Port, DHT11_SENSOR_Pin))) // if the pin is low
	{
		delay(80);
		if ((HAL_GPIO_ReadPin(DHT11_SENSOR_GPIO_Port, DHT11_SENSOR_Pin)))
			Response = INIT_SUCCESS; // if the pin is high, response is ok
		else
			Response = INIT_FAIL; // 255
	}
	while ((HAL_GPIO_ReadPin(DHT11_SENSOR_GPIO_Port, DHT11_SENSOR_Pin)))
		; // wait for the pin to go low

	return Response;
}

uint8_t DHT11_Read(void)
{
	uint8_t i, j;
	for (j = 0; j < 8; j++)
	{
		while (!(HAL_GPIO_ReadPin(DHT11_SENSOR_GPIO_Port, DHT11_SENSOR_Pin)));	// wait for the pin to go high
		delay(40);														   // wait for 40 us
		if (!(HAL_GPIO_ReadPin(DHT11_SENSOR_GPIO_Port, DHT11_SENSOR_Pin))) // if the pin is low
		{
			i &= ~(1 << (7 - j)); // write 0
		}
		else
			i |= (1 << (7 - j)); // if the pin is high, write 1
		while ((HAL_GPIO_ReadPin(DHT11_SENSOR_GPIO_Port, DHT11_SENSOR_Pin)))
			; // wait for the pin to go low
	}
	return i;
}

float DHT11_Result(float Temperature, float Humidity)
{
	uint8_t Presence = 0;
	uint8_t Rh_byte1, Rh_byte2, Temp_byte1, Temp_byte2;
	uint16_t SUM, RH, TEMP;
	// float Temperature = 0;
	// float Humidity = 0;
	DHT11_Start();
	Presence = DHT11_Check_Response();
	while(Presence!=INIT_SUCCESS)
	{
		log_data("Init dht11 fail\ninit again\n");
		Presence = DHT11_Check_Response();
	}
	Rh_byte1 = DHT11_Read();
	Rh_byte2 = DHT11_Read();
	Temp_byte1 = DHT11_Read();
	Temp_byte2 = DHT11_Read();
	SUM = DHT11_Read();

	TEMP = Temp_byte1;
	RH = Rh_byte1;

	Temperature = (float)TEMP;
	Humidity = (float)RH;
}

/************for LEVEL***************/
//4095 -> 0cm
float Level_Result()
{
	uint16_t value_level;
	float level;
	value_level = HAL_ADC_GetValue(&hadc2);
	level = 10.0-(10/4095)*(float)value_level;
	return level;
}

/************for ADC ACCQUI***************/
//4095-> 3.3V
float Accqui_Result()
{
	uint16_t value_accqui;
	float vol_accqi;
	value_accqui = HAL_ADC_GetValue(&hadc1);
	vol_accqi = (3.3/4095)*(float)value_accqui;
	return vol_accqi;
}

// /*************NPN cam bien Tiem can**********/
// int Vehical_State()
// {
// 	int vhc_state;
// 	detect = HAL_GPIO_ReadPin(NPN_DATA_IN_GPIO_Port, NPN_DATA_IN_Pin);
// }

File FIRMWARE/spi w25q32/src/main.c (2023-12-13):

#include "stm32f10x.h"

void Delay1Ms(void);
void Delay_Ms(uint32_t u32DelayInMs);

void Delay1Ms(void)
{
	
	TIM_SetCounter(TIM2, 0);
	while (TIM_GetCounter(TIM2) < 1000) {
	}
}

void Delay_Ms(uint32_t u32DelayInMs)
{
	
	while (u32DelayInMs) {
		Delay1Ms();
		--u32DelayInMs;
	}
}

uint8_t spi_exchange(uint8_t u8Data);
void w25q32_sector_erase(uint32_t u32Address);
void w25q32_page_write(uint32_t u32Address, uint8_t *pu8Data);
void w25q32_read(uint32_t u32Address, uint8_t *pu8Data, uint32_t len);

uint8_t spi_exchange(uint8_t u8Data)
{
	
	SPI_I2S_SendData(SPI2, u8Data);
	while (SPI_I2S_GetFlagStatus(SPI2, SPI_I2S_FLAG_BSY) == SET) {
	}
	return SPI_I2S_ReceiveData(SPI2);
}

void w25q32_sector_erase(uint32_t u32Address)
{
	
	GPIO_ResetBits(GPIOB, GPIO_Pin_12);
	spi_exchange(0x06);
	GPIO_SetBits(GPIOB, GPIO_Pin_12);

	Delay_Ms(1);
	
	GPIO_ResetBits(GPIOB, GPIO_Pin_12);
	spi_exchange(0x20);
	spi_exchange((u32Address >> 16));
	spi_exchange((u32Address >> 8));
	spi_exchange((u32Address));
	GPIO_SetBits(GPIOB, GPIO_Pin_12);
	
	Delay_Ms(400);
}

void w25q32_page_write(uint32_t u32Address, uint8_t *pu8Data)
{
	uint16_t i;
	
	GPIO_ResetBits(GPIOB, GPIO_Pin_12);
	spi_exchange(0x06);
	GPIO_SetBits(GPIOB, GPIO_Pin_12);

	Delay_Ms(1);
	
	GPIO_ResetBits(GPIOB, GPIO_Pin_12);
	spi_exchange(0x02);
	spi_exchange((u32Address >> 16));
	spi_exchange((u32Address >> 8));
	spi_exchange((u32Address));
	for (i = 0; i < 256; ++i) {
		spi_exchange(pu8Data[i]);
	}
	GPIO_SetBits(GPIOB, GPIO_Pin_12);
	
	Delay_Ms(3);
}
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

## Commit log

2023-09-10 firt commit
    [BOM List - New.xlsx, BOM list.xlsx, GPS_Tracking_V1.0.SchDoc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]
2023-09-27 power sche
    [Abstract.SchDoc, GSHT.PrjPCB, PCB_GSHT.PcbDoc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]
2023-11-07 sim check AT oke
    [GSHT.xlsx, [1]PowerSupply.SchDoc]
2023-12-13 pub data to ThingsBoard
    [1.0_mattruoc.STL, 2.0_matsau.STL, 3.0_laptren.STL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]
2023-12-18 upload report doc
    [1.0_mattruoc.STL, 2.0_matsau.STL, 3.0_laptren.STL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]

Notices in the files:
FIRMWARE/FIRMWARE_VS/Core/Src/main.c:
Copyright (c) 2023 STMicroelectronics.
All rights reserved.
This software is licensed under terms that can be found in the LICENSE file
